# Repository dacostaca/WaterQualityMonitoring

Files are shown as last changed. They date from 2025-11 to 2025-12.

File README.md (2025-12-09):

# Water Quality Monitoring System 🌊





Un sistema autónomo de monitoreo de calidad del agua basado en ESP32 con cuatro sensores: pH, temperatura, TDS y turbidez. Incluye implementación de Deep Sleep y Watchdog Timer para operación autónoma y monitoreo de errores.

---

## 📋 Tabla de Contenidos

- [Descripción General](#-descripción-general)
- [Estado del Proyecto](#-estado-del-proyecto)
- [Estructura del Repositorio](#-estructura-del-repositorio)
  - [Etapa I - Trabajo Previo](#etapa-i---trabajo-previo)
  - [Etapa II - Desarrollo Actual](#etapa-ii---desarrollo-actual)
  - [Código del Firmware (MonitorAgua_ESP32)](#código-del-firmware-monitoragua_esp32)
  - [Código del Servidor (monitor_agua_pagina)](#código-del-servidor-monitor_agua_pagina)
- [Documentación del Código](#-documentación-del-código)
- [Inicio Rápido](#-inicio-rápido)
- [Requisitos](#-requisitos)
- [Colaboradores](#-colaboradores)
- [Licencia](#-licencia)

---

## 🌟 Descripción General

Este proyecto implementa un sistema de monitoreo de calidad del agua diseñado para operar de forma autónoma. El sistema mide cuatro parámetros críticos del agua (pH, temperatura, TDS y turbidez) y transmite los datos a un servidor web para su visualización y análisis.

### ¿Qué mide el sistema?

- **pH**: Nivel de acidez/alcalinidad del agua (0-14)
- **Temperatura**: Temperatura del agua en °C usando sensor DS18B20
- **TDS (Total Dissolved Solids)**: Concentración de sólidos disueltos en ppm
- **Turbidez**: Claridad del agua en NTU

### Aplicaciones

- Monitoreo ambiental de cuerpos de agua naturales
- Control de calidad en plantas de tratamiento
- Investigación científica y educativa
- Acuicultura y piscicultura
- Sistemas de agua potable

---

## 📌 Estado del Proyecto

**Estado actual**: El desarrollo del proyecto ha sido completado en su Etapa II. El sistema se encuentra funcional y documentado, listo para su uso o para ser retomado por futuros desarrolladores que deseen realizar mejoras o extensiones.

**Última actualización**: 09 de diciembre de 2025 (Etapa II)

---

## 📁 Estructura del Repositorio

```
WaterQualityMonitoring/
│
├── Etapa I/                        # Trabajo previo del proyecto (01-08-2025)
│   ├── diseños_pcb/               # Diseños de PCB originales
│   └── documentacion.pdf          # Documentación de la etapa inicial
│
├── Etapa II/                       # Desarrollo actual (09-12-2025)
│   ├── Manual de Usuario.md       # Guía completa para el usuario
│   ├── Pruebas y Validación.pdf   # Documento de pruebas realizadas
│   └── registro sistema de monitoreo.rar  # Fotos y fuente LaTeX
│
├── MonitorAgua_ESP32/             # Código del firmware (ESP32)
│   ├── .vscode/                   # Configuración de Visual Studio Code
│   ├── include/                   # Archivos de cabecera (placeholder)
│   ├── lib/                       # Librerías del proyecto
│   ├── src/                       # Código fuente principal
│   ├── test/                      # Directorio de tests (placeholder)
│   ├── .gitignore                # Archivos ignorados por Git
│   ├── Doxyfile                  # Configuración para Doxygen
│   └── platformio.ini            # Configuración de PlatformIO
│
├── monitor_agua_pagina/           # Código del servidor web
│   ├── web_interface/            # Interfaz web del sistema
│   └── servidor.py               # Servidor Python
│
└── README.md                     # Este archivo
```

---

## 📂 Descripción de Carpetas

### Etapa I - Trabajo Previo

**Fecha de entrega**: 01 de agosto de 2025

La carpeta **`Etapa I/`** contiene el trabajo realizado por los desarrolladores iniciales del proyecto:

#### 📐 Diseños de PCB
- **Ubicación**: `Etapa I/diseños_pcb/`
- **Contenido**: Archivos de diseño de la placa de circuito impreso (PCB) utilizados en las versiones iniciales del proyecto
- **Propósito**: Referencia para entender el hardware original y base para mejoras futuras

#### 📄 Documentación Inicial
- **Ubicación**: `Etapa I/documentacion.pdf`
- **Contenido**: Documentación técnica del proyecto en su fase inicial
- **Incluye**: 
  - Especificaciones originales del sistema
  - Diagramas de conexión
  - Resultados de pruebas preliminares
  - Decisiones de diseño tomadas

**Colaboradores Etapa I:**
- Maria Alejandra González Duque
- Juan Carlos Delgado Figueroa

---

### Etapa II - Desarrollo Actual

**Fecha de entrega**: 09 de diciembre de 2025

La carpeta **`Etapa II/`** contiene el trabajo realizado durante el segundo semestre de 2025:

#### 📖 Manual de Usuario
- **Archivo**: `Etapa II/Manual de Usuario.md`
- **Descripción**: Guía completa y detallada para usuarios finales del sistema
- **Contenido**:
  - Instalación del entorno de desarrollo (Visual Studio Code y PlatformIO)
  - Configuración del hardware y drivers
  - Conexión física de sensores a los pines GPIO
  - Flasheo del programa a la ESP32
  - Configuración de red WiFi
  - Uso del sistema y visualización de datos
  - Solución de problemas comunes
  - Referencias y recursos adicionales
- **Audiencia**: Usuarios finales, técnicos, estudiantes

#### 🧪 Documento de Pruebas y Validación
- **Archivo**: `Etapa II/Pruebas y Validación.pdf`
- **Descripción**: Documentación de todas las pruebas realizadas al sistema
- **Contenido**:
  - Metodología de pruebas
  - Casos de prueba ejecutados
  - Resultados obtenidos
  - Análisis de desempeño del sistema
  - Validación de funcionalidades
  - Conclusiones y recomendaciones
- **Propósito**: Validar el correcto funcionamiento del sistema y documentar su rendimiento

#### 📸 Registro del Sistema (LaTeX)
- **Archivo**: `Etapa II/registro sistema de monitoreo.rar`
- **Contenido**:
  - **Fotografías**: Imágenes del sistema ensamblado, sensores conectados, pruebas en campo
  - **Fuente LaTeX**: Archivos `.tex` del documento de registro
  - **Recursos**: Figuras, tablas y archivos auxiliares para compilar el documento
- **Propósito**: Documentación visual del proyecto y fuente editable para reportes académicos
- **Uso**: Descomprimir el archivo RAR y compilar el documento LaTeX para visualizar el registro completo del sistema

**Colaboradores Etapa II:**
- Daniel Felipe Acosta Castro
- Oscar Santiago Erazo Mora

*Estudiantes de Ingeniería Electrónica, Universidad Nacional de Colombia*

---

### Código del Firmware (MonitorAgua_ESP32)

La carpeta **`MonitorAgua_ESP32/`** contiene todo el código que se ejecuta en la placa ESP32.

#### Estructura del Firmware

```
MonitorAgua_ESP32/
│
├── .vscode/                       # Configuración del entorno VSCode
│   └── [archivos de configuración]
│
├── include/                       # Directorio para archivos de cabecera
│   └── README                    # Archivo placeholder
│
├── lib/                          # Librerías personalizadas del proyecto
│   ├── CalibrationManager/      # Gestión de calibración de sensores
│   │   ├── CalibrationManager.cpp
│   │   └── CalibrationManager.h
│   │
│   ├── DeepSleep/               # Implementación de modo Deep Sleep
│   │   ├── DeepSleep.cpp
│   │   └── DeepSleep.h
│   │
│   ├── RTC/                     # Control del reloj de tiempo real (RTC)
│   │   ├── RTC.cpp
│   │   └── RTC.h
│   │
│   ├── RTCMemory/               # Gestión de memoria del RTC
│   │   ├── RTCMemory.cpp
│   │   └── RTCMemory.h
│   │
│   ├── Sensors/                 # Controladores de sensores
│   │   ├── pH.cpp              # Sensor de pH
│   │   ├── pH.h
│   │   ├── Temperature.cpp     # Sensor de temperatura DS18B20
│   │   ├── Temperature.h
│   │   ├── TDS.cpp             # Sensor TDS
│   │   ├── TDS.h
│   │   ├── Turbidity.cpp       # Sensor de turbidez
│   │   └── Turbidity.h
│   │
│   ├── WatchDog/                # Implementación del Watchdog Timer
│   │   ├── WatchDog.cpp
│   │   └── WatchDog.h
│   │
│   └── WifiManager/             # Gestión de conectividad WiFi
│       ├── WifiManager.cpp
│       └── WifiManager.h
│
├── src/                          # Código fuente principal
│   └── main.cpp                 # Punto de entrada del programa
│
├── test/                         # Directorio para tests unitarios
│   └── README                   # Archivo placeholder
│
├── .gitignore                    # Archivos ignorados por Git
├── Doxyfile                      # Configuración de Doxygen
└── platformio.ini                # Configuración de PlatformIO
```

#### Descripción de Componentes del Firmware

##### Librerías Principales

- **CalibrationManager**: Gestiona los valores de calibración de los sensores, permitiendo ajustar las lecturas para mayor precisión
- **DeepSleep**: Implementa el modo de bajo consumo de energía, haciendo que la ESP32 entre en Deep Sleep entre mediciones para optimizar el uso de batería
- **RTC**: Maneja la comunicación con el módulo de reloj de tiempo real (RTC DS3231) para mantener estampas de tiempo precisas
- **RTCMemory**: Gestiona el almacenamiento de datos en la memoria del RTC que persiste durante los ciclos de Deep Sleep
- **Sensors**: Contiene los controladores para cada uno de los cuatro sensores:
  - **pH**: Sensor analógico de pH que mide acidez/alcalinidad del agua
  - **Temperature**: Sensor digital DS18B20 que usa protocolo OneWire
  - **TDS**: Sensor analógico de sólidos totales disueltos
  - **Turbidity**: Sensor analógico de turbidez que mide claridad del agua
- **WatchDog**: Implementa el temporizador Watchdog para reiniciar automáticamente el sistema en caso de fallos o bloqueos
- **WifiManager**: Gestiona la conexión WiFi, reconexión automática y comunicación con el servidor

##### Código Principal

- **main.cpp**: Programa principal que orquesta todas las funcionalidades:
  - Inicialización de sensores y periféricos
  - Bucle principal de medición
  - Almacenamiento local de datos
  - Gestión de ciclos de Deep Sleep
  - Conexión periódica a WiFi para transmisión de datos

#### Archivos de Configuración

- **platformio.ini**: Define la configuración del proyecto para PlatformIO, incluyendo:
  - Placa objetivo (ESP32)
  - Framework (Arduino)
  - Librerías externas requeridas
  - Velocidad de baudios para comunicación serial
  - Flags de compilación

- **Doxyfile**: Configuración para generar documentación automática del código usando Doxygen

#### Funcionalidades Principales del Firmware

- ⚡ **Adquisición de datos**: Lee valores de los cuatro sensores de forma periódica
- 💾 **Almacenamiento local**: Guarda mediciones en memoria del RTC cuando no hay conectividad
- 🌐 **Conectividad WiFi**: Se conecta a red configurada para transmisión de datos al servidor
- ⏰ **RTC externo**: Mantiene estampas de tiempo precisas con batería de respaldo
- 🔋 **Deep Sleep**: Reduce consumo de energía entrando en modo de bajo consumo entre mediciones
- 🛡️ **Watchdog Timer**: Reinicia automáticamente el sistema ante fallos o bloqueos
- 📊 **Calibración**: Sistema de calibración para ajustar lecturas de sensores
- 📡 **Protocolo OneWire**: Comunicación con sensor de temperatura DS18B20

---

### Código del Servidor (monitor_agua_pagina)

La carpeta **`monitor_agua_pagina/`** contiene el servidor web que recibe y visualiza los datos del sistema.

#### Estructura del Servidor

```
monitor_agua_pagina/
│
├── web_interface/                # Interfaz web del sistema
│   ├── css/                     # Hojas de estilo
│   │   └── styles.css          # Estilos de la interfaz
│   │
│   ├── js/                      # JavaScript del cliente
│   │   └── script.js           # Lógica de la interfaz web
│   │
│   └── index.html               # Página principal
│
└── servidor.py                   # Servidor Python
```

#### Descripción de Componentes del Servidor

##### Servidor Backend

- **servidor.py**: Servidor web implementado en Python que maneja:
  - Recepción de datos enviados por la ESP32
  - Procesamiento y validación de mediciones
  - Almacenamiento temporal de datos
  - Servicio de la interfaz web
  - API para consulta de datos históricos

##### Interfaz Web (web_interface/)

- **index.html**: Página principal de la aplicación web que proporciona:
  - Visualización de datos en tiempo real
  - Gráficos de tendencias de mediciones
  - Tabla con historial de datos (últimas 120 mediciones por defecto)
  - Botón para solicitar datos almacenados en la ESP32
  - Indicadores de estado de conexión

- **styles.css**: Hoja de estilos que define:
  - Diseño y apariencia de la interfaz
  - Estilos para gráficos y tablas
  - Diseño responsivo
  - Indicadores visuales de estado

- **script.js**: JavaScript del lado del cliente que maneja:
  - Solicitudes AJAX al servidor
  - Actualización dinámica de la interfaz
  - Generación de gráficos interactivos
  - Procesamiento y visualización de datos recibidos
  - Gestión de eventos de usuario (botones, filtros, etc.)

#### Funcionalidades del Servidor

- 🌐 **API REST**: Endpoints para recibir datos de la ESP32 vía HTTP
- 📊 **Visualización**: Interfaz web para mostrar datos en tiempo real y tendencias
- 💾 **Almacenamiento temporal**: Mantiene datos recientes en memoria para consulta
- 🔄 **Actualización dinámica**: Refresca automáticamente la interfaz con nuevos datos
- 📈 **Gráficos**: Generación de gráficos de series de tiempo para cada sensor
- 🎨 **Interfaz responsiva**: Diseño adaptable a diferentes tamaños de pantalla

#### Tecnologías Utilizadas

- **Backend**: Python (servidor web)
- **Frontend**: HTML5, CSS3, JavaScript
- **Comunicación**: HTTP/REST API
- **Visualización**: JavaScript (librerías de gráficos integradas en script.js)

---

## 📖 Documentación del Código

### Documentación Doxygen del Firmware

El código del firmware en la carpeta **`MonitorAgua_ESP32/`** está completamente documentado utilizando el estándar **Doxygen**. Esto permite generar documentación HTML profesional de forma automática a partir de los comentarios en el código.

#### ¿Qué es Doxygen?

Doxygen es una herramienta que extrae comentarios especialmente formateados del código fuente y genera documentación en varios formatos (HTML, PDF, LaTeX). Es ampliamente utilizado en proyectos de software para mantener la documentación sincronizada con el código.

#### 📚 Generación de la Documentación

##### Prerrequisitos

Antes de generar la documentación, asegúrese de tener Doxygen instalado:

**Windows:**
1. Descargue el instalador desde: https://www.doxygen.nl/download.html
2. Ejecute el instalador y siga las instrucciones

##### Pasos para Generar la Documentación

1. **Abrir una terminal** (Command Prompt o PowerShell) en la carpeta raíz del firmware:
   ```
   cd MonitorAgua_ESP32
   ```

2. **Ejecutar el comando de Doxygen**:
   ```
   doxygen Doxyfile
   ```

3. **Esperar** a que el proceso termine. Verá mensajes en la terminal indicando el progreso de la generación.

4. **Acceder a la documentación generada**:
   - Una vez completado el proceso, se creará una carpeta llamada **`html/`** dentro del proyecto `MonitorAgua_ESP32/`
   - Navegue a la carpeta: `MonitorAgua_ESP32/html/`
   - Abra el archivo **`index.html`** en su navegador web preferido (doble clic sobre el archivo)

##### Contenido de la Documentación

La documentación generada incluye:

- **Índice de archivos**: Listado de todos los archivos del proyecto con su descripción
- **Índice de clases**: Todas las clases definidas con sus métodos y atributos
- **Índice de funciones**: Listado alfabético de todas las funciones del proyecto
- **Diagramas de clases**: Visualización de relaciones entre clases (requiere Graphviz)
- **Diagramas de dependencias**: Muestra qué archivos dependen de otros
- **Gráficos de llamadas**: Ilustra qué funciones llaman a otras funciones
- **Documentación detallada**: Descripción completa de cada función con:
  - Propósito y funcionalidad
  - Parámetros de entrada
  - Valores de retorno
  - Notas y advertencias
  - Ejemplos de uso (cuando aplica)

##### Navegación de la Documentación

Una vez abierto `index.html`:

1. Use el menú superior para navegar entre secciones:
   - **Files**: Ver todos los archivos del proyecto
   - **Classes**: Ver las clases definidas
   - **Functions**: Buscar funciones específicas

2. Use la barra de búsqueda en la esquina superior derecha para encontrar elementos específicos

3. Haga clic en cualquier elemento para ver su documentación detallada

---

## 🚀 Inicio Rápido

### 1. Clonar el Repositorio

```bash
git clone https://github.com/dacostaca/WaterQualityMonitoring.git
cd WaterQualityMonitoring
```

### 2. Configurar el Firmware (ESP32)

1. Abra Visual Studio Code
2. Instale la extensión PlatformIO IDE
3. Abra la carpeta `MonitorAgua_ESP32` con PlatformIO
4. Conecte la ESP32 al computador mediante USB
5. Compile y flashee el programa usando el botón "Upload" (→) en la barra inferior de PlatformIO

**Nota importante**: El puerto USB Tipo C de la ESP32 solo funciona en **una orientación**. Si el computador no detecta la placa, desconecte el cable USB, voltéelo e intente conectar nuevamente.

### 3. Configurar el Servidor

1. Navegue a la carpeta del servidor:
   ```bash
   cd monitor_agua_pagina
   ```

2. Asegúrese de tener Python instalado en su sistema

3. Ejecute el servidor:
   ```bash
   python servidor.py
   ```

### 4. Acceder a la Interfaz Web

1. Abra su navegador web
2. Vaya a la dirección proporcionada por el servidor (típicamente `http://localhost:5000` o similar)
3. Espere a que la ESP32 se conecte a la red WiFi configurada
4. Use el botón "Solicitar Datos" para descargar las mediciones almacenadas en la ESP32

### 5. Configurar Red WiFi

El sistema está configurado por defecto para conectarse a:
- **SSID**: `RED_MONITOREO`
- **Contraseña**: `Holamundo6`

Para cambiar estas credenciales, edite el archivo de configuración en el firmware y vuelva a flashear el programa.

---

## 🔧 Requisitos

### Hardware

- **Placa**: ESP32 S2 o compatible
- **Sensores DFRobot**:
  - Sensor de pH (analógico)
  - Sensor de temperatura DS18B20 (digital, protocolo OneWire)
  - Sensor TDS (analógico)
  - Sensor de turbidez (analógico)
- **Módulo RTC**: DS3231 con batería CR2032 de 3.3V
- **Cable**: USB Tipo C
- **Alimentación**: 5V (USB o fuente externa)
- **Computador**: Windows 10/11 con puerto USB disponible

### Software

- **[Visual Studio Code](https://code.visualstudio.com/)** - Editor de código
- **[PlatformIO IDE](https://platformio.org/)** - Extensión para VSCode
- **[Python](https://www.python.org/downloads/)** - Para ejecutar el servidor (versión 3.7 o superior)
- **[CP210x USB to UART Bridge Drivers](https://www.silabs.com/developers/usb-to-uart-bridge-vcp-drivers)** - Drivers para comunicación con ESP32
- **[Doxygen](https://www.doxygen.nl/download.html)** - (Opcional) Para generar documentación del código
- **[Graphviz](https://graphviz.org/download/)** - (Opcional) Para diagramas en Doxygen

### Conocimientos Recomendados

- Manejo básico de Visual Studio Code
- Conceptos básicos de electrónica (voltaje, corriente, conexión de sensores)
- Navegación en interfaces web
- Conocimientos básicos de línea de comandos (para ejecutar el servidor)

---

## 📄 Documentación Adicional

Para información detallada sobre el uso del sistema, consulte:

- **[Manual de Usuario](Etapa%20II/Manual%20de%20Usuario.md)**: Guía completa de instalación, configuración y uso
- **[Pruebas y Validación](Etapa%20II/Pruebas%20y%20Validación.pdf)**: Resultados de las pruebas realizadas al sistema
- **[Registro LaTeX](Etapa%20II/registro%20sistema%20de%20monitoreo.rar)**: Documentación visual y fuente LaTeX (descomprimir para acceder)
- **[Documentación Etapa I](Etapa%20I/documentacion.pdf)**: Trabajo previo del proyecto
- **Documentación del código**: Generar con Doxygen siguiendo las instrucciones de la sección anterior

---

## 👥 Colaboradores

### Etapa I (01 de agosto de 2025)
- **Maria Alejandra González Duque**
- **Juan Carlos Delgado Figueroa**

*Responsables del diseño inicial de hardware y primera implementación del sistema*

### Etapa II (09 de diciembre de 2025)
- **Daniel Felipe Acosta Castro** - [GitHub](https://github.com/dacostaca)
- **Oscar Santiago Erazo Mora**

*Estudiantes de Ingeniería Electrónica*  
*Universidad Nacional de Colombia*  
*Segundo semestre de 2025*

---

## 🙏 Agradecimientos

- DFRobot por la documentación de los sensores utilizados
- Comunidad de PlatformIO por las herramientas de desarrollo
- Espressif por el soporte de ESP32
- Universidad Nacional de Colombia por el apoyo académico

---

**⭐ Si este proyecto te fue útil, considera darle una estrella en GitHub ⭐**

---

*Proyecto desarrollado como parte del programa de Ingeniería Electrónica*  
*Universidad Nacional de Colombia - 2025*

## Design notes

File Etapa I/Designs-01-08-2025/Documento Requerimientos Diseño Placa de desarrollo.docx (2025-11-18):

Documento de Requerimientos para Diseño de Circuitos Electrónicos

# Especificaciones Técnicas y Selección de Componentes en diseño de PCB

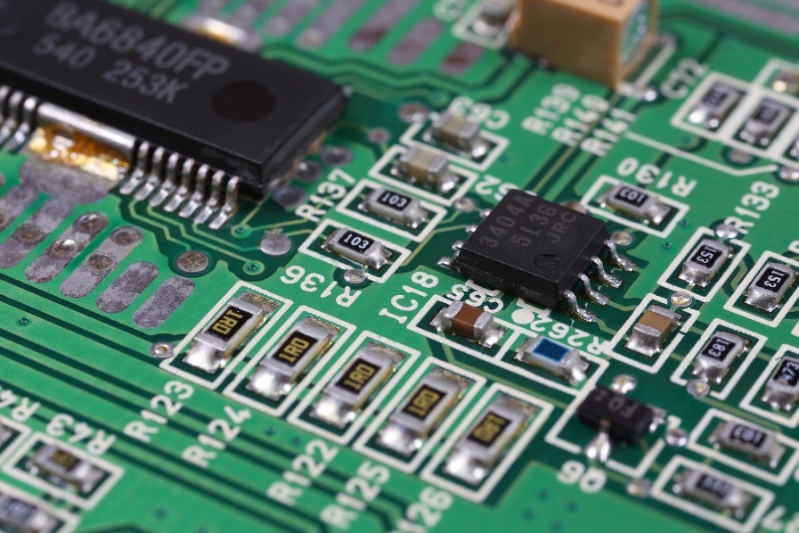
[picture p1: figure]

Tabla de Contenido

1. Introducción y Objetivos 1.1 Propósito del Documento 1.2 Alcance 1.3 Objetivos de Aprendizaje
2. Metodología de Análisis de Requerimientos 2.1 Proceso de Definición de Requerimientos 2.1.1 Identificación de Stakeholders 2.1.2 Jerarquía de Requerimientos 2.2 Análisis de Criticidad
3. Especificaciones Técnicas del Proyecto 3.1 Definición de Requerimientos Funcionales 3.1.1 RF-001 – Acceso físico a Pines GPIO 3.1.2 RF-002 – Interfaz de alimentación y comunicación USB 3.1.3 RF-003 – Indicadores y puntos de prueba 3.2 Requerimientos No Funcionales 3.2.1 RNF-001 – Consumo de Energía 3.2.2 RNF-002 – Estabilidad en entorno de desarrollo 3.2.3 RNF-003 – Manufacturabilidad 3.2.4 RNF-004 – Optimización de costo 3.3 Requerimientos Derivados 3.3.1 RD-001 – Selección de componentes 3.3.2 RD-002 – Tolerancias técnicas 3.3.3 RD-003 – Métodos de prueba y validación 3.4 Análisis de Carga y Distribución de Energía 3.4.1 Presupuesto de Energía
4. Criterios de Selección de Componentes 4.1 Metodología de Selección 4.1.1 Etapas del proceso de Evaluación 4.2 Criterios Específicos por Categoría 4.2.1 Microcontroladores 4.2.2 Componentes Pasivos 4.2.3 Conectores 4.3 Herramientas de Selección 4.3.1 Bases de Datos Recomendadas 4.3.2 Herramientas de Análisis 4.4 Selección de BOM para placa de desarrollo ESP32 4.4.1 Microcontrolador (ESP32-S2-SOLO) 4.4.2 Regulador de Voltaje (AMS1117CD-3.3) 4.4.3 Conector USB-C y ESD (TPD4S009DBVR) 4.4.4 Conversor USB-Serial (CP2102N) 4.4.5 Indicadores LED 4.4.6 Protección de Alimentación 4.4.7 Pasivos funcionales (resistencias, capacitores, inductores) 4.4.8 Automatización de Programación (BOOT & EN) 4.5 Análisis de Riesgo
5. Consideraciones de Normas y Estándares 5.1 Normas Internacionales 5.2 Reglas de Diseño Prácticas para Fabricación Recomendadas 5.3 Consideraciones de Costos
6. Validación y Pruebas 6.1 Estrategia de Validación 6.1.1 Niveles de Validación 6.1.2 Métodos de Validación 6.2 Protocolo de Pruebas 6.2.1 Pruebas Eléctricas Básicas 6.2.2 Pruebas Funcionales 6.3 Criterios de Aceptación
7. Documentación 7.1 Documentos Generados 7.2 Documentación de Diseño
8. Referencias Bibliográficas 8.1 Normas y Estándares 8.2 Literatura Técnica 8.3 Recursos Online
9. Conclusiones

1. Introducción y Objetivos

1.1 Propósito del Documento

Este documento técnico establece los requerimientos y lineamientos para el diseño y de un conjunto de placas electrónicas, compuesto por:

- Una placa de desarrollo general basada en el microcontrolador ESP32-S2-SOLO, orientada a prototipado y pruebas de comunicación.
- Una auxiliar, alimentada mediante dos baterías recargables de 3.7V, cuya carga y regulación está gestionada por el controlador MP2639, además de estar gestionada por un RTC externo.

1.2 Alcance

Este documento aplica a proyectos de diseño de circuitos electrónicos impresos (PCBs), incluyendo especificaciones funcionales y no funcionales, criterios de validación, selección de componentes clave y consideraciones de diseño electrónico y PCB que garanticen manufacturabilidad, seguridad y fiabilidad operativa. Está orientado a respaldar las decisiones técnicas de diseño.

1.3 Objetivos de Aprendizaje

Al aplicar esta metodología, el diseñador será capaz de:

- Convertir requerimientos funcionales en especificaciones técnicas claras
- Evaluar y seleccionar componentes usando criterios técnicos objetivos
- Identificar restricciones de diseño y riesgos técnicos en etapas tempranas del proyecto
- Documentar requerimientos técnicos de forma estructurada y trazable
- Aplicar buenas prácticas en el diseño esquemático y el ruteo de PCB
- Integrar consideraciones de alimentación, protección, comunicación y sensores en el diseño electrónico
- Establecer criterios de validación y pruebas acordes a los requerimientos definidos
- Generar documentación técnica útil para validación, rediseño y manufactura

2. Metodología de Análisis de Requerimientos

2.1 Proceso de Definición de Requerimientos

2.1.1 Identificación de Stakeholders

En esta etapa inicial es fundamental identificar a las partes interesadas del proyecto, ya que cada una de ellas impone requisitos específicos que deben ser considerados durante el diseño del circuito electrónico:

Stakeholders | Necesidad | Impacto en el diseño | Requerimientos derivados
Usuario Final | Facilidad de uso, funcionalidad clara, confiabilidad | Interfaz intuitiva, respuesta adecuada, diseño robusto | Dimensiones compactas, distribución funcional, protecciones básicas
Fabricación | Bajo costo, ensamblaje sencillo, procesos repetibles | Elección de componentes comunes, diseño sin pasos complejos | PCB de una o dos capas, encapsulados SMD comunes
Regulatorio | Cumplimiento de normativas básicas (CE, FCC, RoHS, etc.) | Aislamiento eléctrico, compatibilidad electromagnética (EMC) | Filtros EMI, separación de pistas, protección ESD
Mantenimiento y validación | Diagnóstico sencillo, acceso a señales, facilidad de reemplazo de componentes | Componentes accesibles con documentación clara, inclusión de puntos de prueba | Pads de prueba, conectores de depuración, etiquetas serigráficas, guía de soporte técnico.

2.1.2 Jerarquía de Requerimientos

Los requerimientos del sistema se organizan en tres categorías, cada una con un propósito específico dentro del diseño y validación de la placa de desarrollo.

A. Requerimientos Funcionales (RF)

Funciones que la placa debe realizar para cumplir su propósito como herramienta de prototipado.

- RF.1 Funciones Principales
- Exposición de señales digitales y analógicas mediante pines GPIO, respetando límites eléctricos.
- Interacción con sensores y/o módulos externos a través de buses de comunicación (UART, I²C, SPI).
- Alimentación regulada y protección básica para pruebas de conectividad.
- RF.2 Funciones secundarias
- Indicadores LED para estado de alimentación y comunicación.
- Zonas de test (test points) para caracterización eléctrica en placa.
- Pulsadores de reinicio y arranque para programación.
- RF.3 Interfaces externas
- Conectores físicos disponibles, incluyendo USB para alimentación y programación, y headers para expansión de periféricos.
- Acceso físico a buses de comunicación estándar (UART, I²C, SPI), a través de pines documentados en el datasheet del microcontrolador y habilitados en el diseño.
- Capacidad de comunicación inalámbrica programable por firmware.
B. Requerimientos No Funcionales (RNF)

Condiciones de calidad y operación bajo las cuales la placa de desarrollo debe funcionar en un entorno de pruebas o prototipado.

- RNF.1 Consumo de Energía
- El sistema debe operar con un consumo típico bajo, adecuado para aplicaciones de desarrollo embebidos.
- El sistema debe tolerar picos de corriente derivados de la activación simultánea de periféricos digitales, transmisores inalámbricos o funciones internas del microcontrolador.
- El diseño de la etapa de alimentación debe incorporar márgenes de seguridad que garanticen arranque estable y operación confiable durante actividades como la programación o la transmisión de datos.
- Se recomienda dimensionar la capacidad de corriente disponible en al menos un 30% por encima del consumo promedio estimado para evitar inestabilidad o caídas de voltaje.
- RNF.2 Confiabilidad en Entorno de Desarrollo
- Operación estable en sesiones prolongadas, sin reinicios ni fallos funcionales.
- Tolerancia a ciclos frecuentes de reinicio, programación y conexión/desconexión de periféricos sin pérdida de integridad.
- RNF.3 Manufacturabilidad
- Uso de componentes estándar (SMD, THT) con disponibilidad comercial.
- Diseño de PCB compatible con procesos básicos de ensamblaje manual o semiautomático.
- Trazabilidad y facilidad de reemplazo de componentes críticos durante pruebas.
- RNF.4 Costo
- Límite de costo estimado por unidad definido según el presupuesto del proyecto.
- Lista de materiales (BOM) optimizada con enfoque en disponibilidad y precio sin comprometer funcionalidad.
C. Requerimientos Derivados (RD)

Condiciones técnicas necesarias para implementar los requerimientos funcionales y no funcionales.

- RD.1 Selección de componentes específicos
- Elección de microcontrolador compatible con los requerimientos funcionales del proyecto.
- Reguladores de voltaje adecuados para manejo de corriente de carga.
- Componentes pasivos y sensores con tolerancias acordes a los márgenes operativos definidos.
- Preferencia por encapsulados compatibles con soldadura manual durante el prototipado.
- RD.2 Tolerancias técnicas
- Tolerancia de voltaje de entrada: ±5% respecto al valor nominal definido en el diseño.
- Compatibilidad con niveles lógicos de 3.3 V o 5 V, según la arquitectura seleccionada.
- Resistencia a ruido eléctrico y desacoples adecuados para operación confiable.
- RD.3 Métodos de prueba y validación
- Verificación de montaje.
- Medición de tensiones y corrientes en puntos clave del sistema (alimentación, referencia, señales de I/O).
- Verificación de arranque del microcontrolador mediante monitoreo serial.
- Carga de firmware de prueba y ejecución de funciones básicas (parpadeo de LED, comunicación UART o inalámbrica).

2.2 Análisis de Criticidad

La criticidad se determina para identificar qué requerimientos impactan directamente en la funcionalidad y validación del sistema. Esta clasificación permite priorizar el cumplimiento de aquellos aspectos que comprometerían el uso correcto del prototipo en caso de fallar.

ID | Tipo | Fuente | Verificación | Prioridad
RF-001 | Funcional | Usuario | Inspección visual y prueba de funcionalidad GPIO. | Alta
RF-002 | Funcional | Usuario | Verificación de funcionamiento de LEDs y test points. | Media
RF-003 | Funcional | Usuario | Prueba de conectividad física y funcionamiento de buses. | Alta
RNF-001 | No funcional | Diseñador | Medición de consumo y verificación de arranque | Alta
RNF-002 | No funcional | Usuario | Pruebas de uso prolongado en entorno de desarrollo. | Media
RNF-003 | No funcional | Diseñador | Revisión de componentes, layout y disponibilidad. | Alta
RNF-004 | No funcional | Proyecto | Comparación con presupuesto y análisis del BOM. | Media
RD-001 | Derivado | Diseñador | Revisión de hojas de datos y compatibilidad funcional. | Alta
RD-002 | Derivado | Diseñador | Cálculo de márgenes eléctricos y tolerancias. | Media
RD-003 | Derivado | Diseñador | Validación funcional mediante firmware de prueba. | Alta

3. Especificaciones Técnicas del Proyecto

3.1 Definición de Requerimientos Funcionales

3.1.1 RF-001 – Acceso físico a Pines GPIO

Descripción:

La placa de desarrollo debe proporcionar acceso físico a los pines GPIO del ESP32-S2-SOLO mediante conectores estándar (headers), respetando las especificaciones eléctricas del microcontrolador.

- Entradas: Señales digitales o analógicas desde sensores o periféricos externos.
- Salidas: Señales digitales, PWM, protocolos de comunicación (UART, I²C, SPI), según configuración del firmware.
- Criterios de Aceptación:
  - Todos los pines habilitados deben estar disponibles en conectores identificados mediante serigrafía legible en la PCB.
  - La disposición física debe permitir conexión directa a cables o módulos comunes de desarrollo.
  - El diseño debe mantener la capacidad nominal del ESP32-S2, incluyendo corriente máxima por pin (hasta 40 mA) bajo las condiciones indicadas en su hoja de datos.
- Prioridad: Alta

Nota técnica:
El valor de corriente máxima por pin (hasta 40 mA) corresponde a una especificación propia del microcontrolador ESP32-S2-SOLO bajo ciertas condiciones eléctricas. Esta placa de desarrollo no amplifica ni modifica dichas salidas, sino que simplemente las expone al usuario final mediante conectores adecuados, permitiendo el uso completo de las capacidades nativas del chip.

    3.1.2 RF-002 – Interfaz de alimentación y comunicación USB

Descripción:

La placa debe incorporar un conector USB-C para permitir tanto la alimentación como la programación del microcontrolador mediante una interfaz USB-UART integrada.

- Parámetros eléctricos:
  - Entrada: 5 V DC (desde puerto USB estándar).
  - Corriente mínima: 500 mA (USB 2.0), recomendada: 900 mA o más.
  - Salida regulada: 3.3 V DC, hasta 800 mA disponibles para el sistema.
- Criterios de Aceptación:
  - Presencia de conector USB-C funcional.
  - Regulación estable de 3.3 V bajo carga media.
  - Reconocimiento del dispositivo como puente USB-UART en el computador.
- Prioridad: Alta
    3.1.3 RF-003 – Indicadores y puntos de prueba

Descripción:

La placa debe incluir al menos dos LEDs de diagnóstico (alimentación y actividad GPIO), y puntos de prueba accesibles (test points) para monitorear señales clave.

- Criterios de Aceptación:
  - LED de encendido activo al recibir alimentación.
  - LED de usuario controlable desde GPIO del ESP32.
  - Al menos dos test points etiquetados (por ejemplo: 3.3 V, GND, UART TX o RX).
- Prioridad: Media

3.2 Requerimientos No Funcionales

    3.2.1 RNF-001 – Consumo de Energía

Especificación:

La placa debe tener un consumo típico máximo de 180 mA durante operación normal, con capacidad de tolerar picos de hasta 320 mA (modo transmisión WiFi), y hasta 500 mA en escenarios extremos.

- Condiciones de referencia:
  - Firmware con WiFi y UART activos.
  - GPIOs y periféricos en uso (SPI, I²C, ADC, etc.).
  - CPU a máxima frecuencia (240 MHz).
  - Posible carga externa moderada en salidas.
- Criterios de aceptación:
  - Consumo en reposo < 100 mA.
  - Soporte de picos sin inestabilidad o reinicios.
  - Regulador de 3.3 V funcionando dentro de rango térmico seguro.
- Prioridad: Alta
    3.2.2 RNF – 002: Estabilidad en entorno de desarrollo

Especificación:

La placa debe operar de manera estable en sesiones continuas (> 2 horas), soportando múltiples ciclos de programación, reinicio y conexión sin errores funcionales.

- Criterios de aceptación :
  - Sin reinicios inesperados.
  - LED y UART activos tras múltiples pruebas.
  - Capacidad de carga de firmware repetida sin fallos.
- Prioridad: Media
    3.2.3 RNF-003 – Manufacturabilidad

Especificación:

El diseño debe contemplar el uso de componentes estándar y encapsulados compatibles con procesos de ensamblaje manual o semiautomático, con especial atención a la accesibilidad para re-trabajo y sustitución durante pruebas.

- Criterios de aceptación:
  - Uso de componentes SMD comunes.
  - Layout compatible con servicios de manufactura comunes (JLCPCB, PCBWay u otros equivalentes).
  - Componentes críticos con distribución física que permita su sustitución sin riesgo de dañar pistas o pads cercanos.
- Prioridad: Alta
    3.2.4 RNF-004 – Optimización de costo

Especificación:

El diseño debe priorizar el uso de componentes con buena relación costo-beneficio, manteniendo la disponibilidad comercial y sin comprometer la funcionalidad mínima esperada del sistema.

- Criterios de aceptación:
  - Componentes clave disponibles en múltiples distribuidores confiables (LCSC, Digi-Key, Mouser).
  - Selección de componentes con equivalentes funcionales y encapsulados alternativos disponibles.
  - Estimación de costo unitario alineada con el presupuesto del proyecto, ajustable según volumen y proveedor.
- Prioridad: Media
  3.2 Requerimientos Derivados
    3.2.1 RD-001 – Selección de componentes

Especificación:

La placa debe garantizar componentes con compatibilidad eléctrica y funcional con los requerimientos definidos, priorizando disponibilidad comercial y facilidad de integración.

- Criterios de aceptación:
  - Microcontrolador con conectividad inalámbrica y buses periféricos integrados (ESP32-S2-SOLO).
  - Regulador con capacidad mínima de 800 mA y salida de 3.3 V.
  - Pasivos con tolerancia adecuada (resistencias ±5%, capacitores X7R o mejores).
- Prioridad: Alta
    3.2.2 RD-002 – Tolerancias técnicas

Especificación:

La placa debe tener tolerancias de voltaje, corriente y niveles lógicos deben mantenerse dentro de márgenes seguros definidos por la hoja de datos para los componentes principales.

- Criterios de aceptación:
  - Voltaje de entrada permitido: 5 V ±5%.
  - Niveles lógicos compatibles con 3.3 V (máximo absoluto: 3.6 V).
  - Uso de desacoples y filtrado para proteger contra transitorios.
  - Aislamiento adecuado entre señales sensibles y líneas de alimentación.
- Prioridad: Media
    3.2.3 RD-003 – Métodos de prueba y validación

Especificación:

Se deben realizar pruebas funcionales básicas que permitan verificar el montaje, la alimentación, y la comunicación del microcontrolador con el entorno de desarrollo.

- Criterios de aceptación:
  - Medición de voltaje regulado (3.3 V) en punto de prueba.
  - Verificación de consumo de corriente con multímetro.
  - Prueba de encendido de LED conectado a GPIO.
  - Carga de firmware.
  - Comunicación UART funcional (reconocimiento por PC).

Nota: No se incluyen pruebas de estrés, ambientales ni de certificación industrial, por tratarse de una placa de desarrollo.

- Prioridad: Alta
  3.3 Análisis de Carga y Distribución de Energía
    3.3.1 Presupuesto de Energía

Esta sección define los márgenes de consumo eléctrico esperados para la placa, considerando distintos modos de operación y posibles picos de corriente. Su objetivo es asegurar una fuente de alimentación adecuada que garantice estabilidad y confiabilidad durante el uso del sistema.

Componente | Corriente Típica | Corriente Máxima | Notas
ESP32-S2-SOLO | 80mA | 320mA | Pico durante transmisión WiFi (802.11b)
CP2102N | 11.4mA | 20mA | Durante comunicación USB-UART
LEDs indicadores | 5-10mA | 10mA | Corriente limitada por resistencia
Periféricos GPIO | 0-50mA | 200mA | Dependiente del uso y carga conectada.
Total | 155mA | 540mA | Margen de seguridad 20%

El valor pico de 320 mA proviene de la hoja de datos del ESP32-S2, en modo de transmisión 802.11b a 20 MHz, 1 Mbps @19.5 dBm.

El valor estimado de 790 mA representa un escenario extremo, considerando el consumo simultáneo del microcontrolador, el CP2102N (~14 mA), los LEDs, periféricos GPIO activos, y posibles buffers o módulos conectados externamente.

Recomendación: El sistema de alimentación debe estar dimensionado para entregar al menos 800 mA de corriente de salida, considerando márgenes de seguridad, condiciones pico y la eficiencia del regulador.

4. Criterios de Selección de Componentes

4.1 Metodología de Selección

La selección de componentes se realiza bajo un enfoque técnico y estratégico, considerando tanto los requerimientos funcionales como las restricciones reales de manufactura manual y presupuesto. Se priorizan componentes con documentación técnica confiable, disponibilidad estable y compatibilidad adecuada para procesos de prototipado manual, reconociendo la dificultad inherente de este tipo de montaje.

4.1.1 Etapas del proceso de Evaluación

La selección técnica de componentes deberá contemplar, como mínimo, los siguientes aspectos:

1. Definición de Especificaciones Mínimas
- Identificación clara y precisa de parámetros eléctricos esenciales (voltaje, corriente máxima, tolerancia requerida, frecuencia de operación), rango de temperatura de funcionamiento según las condiciones típicas.
- Restricción del tipo de encapsulado a formatos compatibles con ensamblaje manual o semiautomático, priorizando encapsulados SMD desde tamaño 0603 en adelante, o THT cuando el componente lo requiera por disponibilidad, facilidad de montaje o reemplazo.
- Consideración de dimensiones físicas que permitan fácil acceso a pines o terminales para soldadura, medición o validación funcional durante el desarrollo.
2. Búsqueda y Filtrado
  - Consultar en bases de datos confiables de componentes electrónicos (Digi-Key, Mouser, LCSC), filtrando según las especificaciones mínimas definidas.
  - Aplicación de filtros técnicos que garanticen compatibilidad eléctrica y mecánica, con prioridad a formatos compatibles con montaje manual.
  - Verificación de disponibilidad comercial inmediata y suficiente cantidad en stock para garantizar la continuidad del prototipo o pruebas.
3. Evaluación Técnica
  - Análisis crítico de hojas de datos, asegurando que las características y parámetros técnicos sean compatibles con las condiciones reales del proyecto.
  - Comparación de alternativas viables en función de parámetros clave (rendimiento eléctrico, límites operativos, tolerancias, condiciones de montaje manual).
  - Evaluación realista de márgenes de seguridad y robustez del diseño frente a posibles variaciones en condiciones operativas.
4. Evaluación Comercial
  - Análisis de costos unitarios y posibles descuentos por volumen de compra.
  - Evaluación detallada sobre disponibilidad actual, confiabilidad del suministro y plazos de entrega.
  - Revisión cuidadosa del entorno de soporte disponible, incluyendo documentación técnica, referencias de aplicación, herramientas de software y respaldo de la comunidad).
5. Validación y Selección Final
  - Se deben realizar pruebas prácticas o prototipos preliminares para verificar el desempeño real de los componentes seleccionados, especialmente si son críticos o presentan desafíos para el montaje manual.
  - Análisis da vigencia comercial del componente, considerando su disponibilidad a largo plazo, la hoja de ruta del fabricante y su política de retiro (End of Life – EOL), minimizando riesgos de obsolescencia.
  - Decisión fundamentada en criterios técnicos y comercialmente objetivos, documentando claramente las razones que respaldan la selección realizada.

4.2 Criterios Específicos por Categoría

Los criterios de evaluación deben adaptarse al tipo de componente considerado, atendiendo a sus funciones, requerimientos de integración y criticidad en el sistema. A continuación, se describen los principales aspectos a considerar por categoría.

4.2.1 Microcontroladores

- Evaluar la capacidad de procesamiento en función de la velocidad de reloj, la cantidad de memoria RAM y flash disponibles, así como los tiempos de respuesta ante eventos.
- Asegurar la disponibilidad y diversidad de periféricos (UART, SPI, I²C, ADC, PWM, entre otros) son fundamentales para garantizar la compatibilidad con el resto del sistema.
- Analizar el consumo energético debe analizarse tanto en operación activa como en modos de bajo consumo, especialmente en aplicaciones portátiles o de energía limitada o alimentadas por batería.
- Verificar la compatibilidad con entornos de desarrollo consolidados, así como la disponibilidad de documentación técnica, soporte del fabricante y respaldo por parte de la comunidad.
- Comprobar la continuidad del producto en el tiempo, mediante la revisión de la hoja de ruta tecnológica del fabricante y su política de soporte a largo plazo.

4.2.2 Componentes Pasivos

- Evaluar la tolerancia en función del costo y la aplicación, especialmente en circuitos que requieran precisión, como divisores de tensión o filtros.
- Considerar la estabilidad frente a temperatura, envejecimiento y variaciones ambientales, en especial en capacitores e inductores.
- Seleccionar el tamaño del encapsulado considerando ensamblaje, disponibilidad y espacio en el PCB.
- Validar límites eléctricos (voltaje, corriente, disipación térmica) y establecer márgenes adecuados para confiabilidad a largo plazo.
- Incluir dispositivos de protección según criticidad del nodo: diodos Schottky, TVS, fusibles o resistencias de 0 Ω.

4.2.3 Conectores

- Analizar la durabilidad mecánica en función de los ciclos de uso, robustez y resistencia al desgaste.
- Asegurar la capacidad de conducción de corriente sin comprometer la integridad del sistema.
- Priorizar compatibilidad con cables y pines estándar, facilitando mantenimiento y evitando herramientas especiales.
- Precio del conector y del cable compatible, incluyendo accesorios o herramientas si son necesarios.

4.3 Herramientas de Selección

La selección de componentes se apoyó en plataformas confiables que permiten consultar especificaciones técnicas, verificar disponibilidad comercial y comparar alternativas de manera eficiente.

4.3.1 Bases de Datos Recomendadas

- Digi-Key y Mouser: Distribuidores con filtros técnicos detallados, documentación técnica y herramientas de selección asistida.
- LCSC: Distribuidor de bajo costo con conexión directa a JLCPCB para producción y ensamble de tarjetas electrónicas.
- Octopart: Plataforma de búsqueda con integración multi-distribuidor, útil para comparación rápida de precios y disponibilidad.
    4.3.2 Herramientas de Análisis

En aplicaciones discretas como filtros, fuentes o protecciones, se emplearon simuladores eléctricos o herramientas de análisis físico de PCB. Su aplicación en circuitos integrados complejos es limitada y se complementa con hojas de datos y notas de aplicación del fabricante.

- TINA-TI y LTSpice son simuladores SPICE adecuados para validar reguladores, etapas de filtrado o circuitos analógicos simples.
- Altium Designer y KiCad, además de ser entornos de diseño, permiten realizar análisis básicos y simulaciones preliminares de ciertos componentes antes de su integración en el diseño final.
  4.3 Selección de BOM para placa de desarrollo ESP32

La selección de componentes se realizó siguiendo los lineamientos definidos en la sección 4.1, integrando criterios técnicos, comerciales y de disponibilidad. Se tomaron en cuenta tanto los requerimientos funcionales específicos del sistema como las restricciones derivadas del diseño del circuito esquemático y la implementación física en la PCB.

La mayoría de los componentes incluidos en la lista de materiales (BOM) corresponden a dispositivos de montaje superficial (SMD), lo cual permite optimizar el uso del espacio, mejorar el comportamiento eléctrico de las señales y facilitar la producción mediante procesos automatizados de ensamblaje.

Si bien ciertos componentes podrían implementarse en versiones through-hole (THT) sin comprometer la funcionalidad, se priorizó el uso de tecnología SMD debido a sus ventajas en cuanto a densidad de integración, disponibilidad en el mercado y compatibilidad con servicios de ensamblaje industrial, como los ofrecidos por JLCPCB o similares.

4.4.1 Microcontrolador

Requerimiento funcional:

El sistema requiere un microcontrolador de arquitectura de 32 bits con conectividad WiFi-integrada, soporte para interfaces periféricas estándar (UART, SPI, I²C), y capacidad de procesamiento suficiente para manejo de sensores comunicación y funciones de control local.

Componente seleccionado: ESP32-S2-SOLO (Espressif Systems)

Justificación de Selección:

El ESP32-S2-SOLO fue utilizado por su disponibilidad previa en el laboratorio y por cumplir con los requerimientos funcionales del sistema. Aunque no se evaluaron múltiples alternativas, se validó que sus características técnicas fueran adecuadas para la aplicación. Entre sus características técnicas relevantes se incluyen:

- Núcleo Xtensa LX7 32-bit a 240 MHz,
- 320 kB de memoria SRAM interna y flash incluida.
- Conectividad WiFi 802.11 b/g/n (2.4 GHz).
- UART, SPI, I²C, ADC y hasta 43 pines GPIOs disponibles.
- Soporte para USB-OTG, permitiendo comunicación directa con PC o periféricos sin requerir un chip USB-UART adicional.
- Múltiples modos de bajo consumo disponibles.

El microcontrolador cuenta con amplio soporte de desarrollo (ESP-IDF, Arduino), documentación oficial completa y comunidad activa, lo cual facilita la implementación, depuración del firmware y mantenimiento del firmware.

Implementación en hardware:

El microcontrolador se integró siguiendo el circuito mínimo de aplicación recomendado en la Hoja de datos. Se emplearon valores de capacitores de filtrado y desacoplo según las indicaciones de Espressif para garantizar la estabilidad del sistema y la correcta operación del microcontrolador.

Cabe aclarar que no todos los elementos del circuito de aplicación típico fueron implementados; se emplearon únicamente aquellos relevantes para los requerimientos funcionales del sistema, como el botón de arranque (boot), resistencias de configuración y líneas de comunicación esenciales.

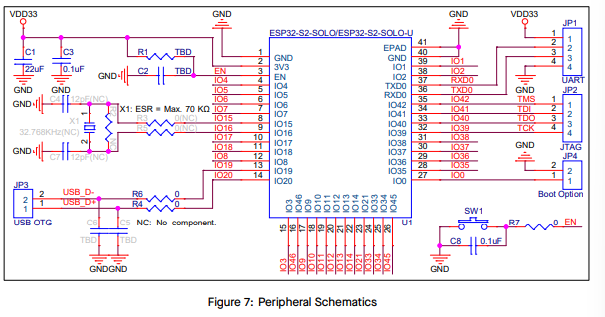
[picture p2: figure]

Figura 4.1 – Circuito de aplicación típico del ESP32-S2-SOLO
Diagrama oficial sugerido por Espressif para implementar las conexiones mínimas del microcontrolador, incluyendo alimentación, cristal externo, botón de reinicio, USB-OTG y puertos UART/JTAG.
Fuente: Espressif Systems – Hoja de datos del ESP32-S2-SOLO/SOLO-U, sección 6: Peripheral Schematics.

    4.3.2 Regulador de Voltaje

Requerimiento Funcional:

El sistema requiere un regulador de voltaje capaz de convertir una entrada de 5 V proveniente del puerto USB-C a una salida estable de 3.3 V con una capacidad mínima de corriente de 800 mA, considerando picos de consumo del microcontrolador y periféricos conectados. Además, se privilegió una solución con buena disipación térmica.

Alternativas evaluadas:

Se analizaron cinco reguladores de voltaje de salida fija a 3.3 V, ampliamente utilizados en aplicaciones de bajo voltaje. La siguiente tabla resume las principales características y criterios que influyeron en su selección o descarte:

Componente | Corriente máx. salida | Dropout @ IOUT máx | Encapsulado | Resultado
AP2112K-3.3 | 600 mA | 0.40 V | SOT-25 | Descartado por corriente limitada
RT9013-33GB | 500 mA | 0.40 V | SOT-23-5 | Descartado por corriente limitada
AMS1117-3.3 | 1 A | 1.1 V | SOT-223-3L | Aceptable, pero menos eficiente y peor disipación térmica
AMS1117CD-3.3 | 1 A | 1.1 V | TO-252-2 | Seleccionado por disipación, disponibilidad y corriente

Justificación de Selección:

El regulador AMS1117CD-3.3 fue seleccionado por ofrecer una combinación adecuada entre capacidad de corriente (hasta 1 A), robustez térmica y compatibilidad con fabricación manual, además, su disponibilidad comercial y uso extendido en diseños similares lo convierten en una solución versátil y confiable. Su encapsulado TO-252-2 proporciona una base metálica de disipación más amplia que otras versiones (como el SOT-223), facilitando el manejo de potencia sin necesidad de soluciones adicionales de refrigeración.

Implementación en hardware:

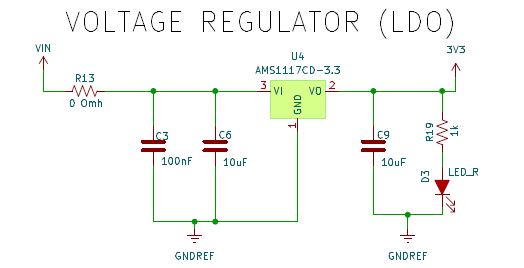
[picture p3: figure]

Figura 4.2 – Implementación del regulador AMS1117CD-3.3

El regulador AMS1117CD-3.3 fue implementado conforme a la topología mínima sugerida por el fabricante, con adaptaciones menores orientadas a facilitar el ensamblaje y el monitoreo en la placa. Se utilizaron capacitores de entrada y salida según la hoja de datos, junto con un LED indicador en la salida (con resistencia limitadora) para verificar la presencia de voltaje. También se incorporó una resistencia de 0 Ω que, además de facilitar pruebas o depuración, puede actuar como punto de seccionamiento o protección ante fallos menores.

    4.3.3 Conector USB-C y ESD

Requerimiento Funcional:

El sistema requiere un conector USB tipo C que actúe como entrada principal de alimentación (5 V) y enlace de comunicación USB 2.0. Debe ser compatible con dispositivos host estándar (computadoras, cargadores, etc.), admitir al menos 500 mA y permitir la negociación de corriente de hasta 3 A. Es indispensable que el conector soporte transferencia de datos, no limitándose únicamente a funciones de carga.

Componente Seleccionado:

- Nombre: UJ20-C-H-G-SMT-1-P16-TR
- Tipo: Receptáculo USB Tipo C, compatible con estándar USB 2.0
- Corriente nominal: Hasta 3 A
- Motivo de selección: Compatibilidad mecánica, disponibilidad y soporte completo para señales D+/D− del estándar USB 2.0.

Este conector cuenta con 16 pines, incluyendo VBUS, GND, D+, D−, y los pines CC1 y CC2, que permiten detectar la orientación del cable y negociar la corriente disponible con el host. A diferencia de conectores diseñados solo para carga, este modelo permite comunicación completa, cumpliendo con el perfil "Sink" según la especificación USB-C, lo que lo hace adecuado para aplicaciones mixtas de alimentación y transmisión de datos

Protección contra ESD:

Las líneas D+ y D− están protegidas mediante el TPD4S009DBVR, un supresor de transitorios de voltaje (TVS) diseñado para proteger hasta cuatro líneas de señal frente a descargas electrostáticas (ESD) o picos transitorios. Este dispositivo brinda protección bidireccional conforme a los requerimientos de integridad de señal USB.

Aunque en esta placa de desarrollo solo se utilizan dos líneas sensibles (D+/D−), se optó por emplear este modelo de (ESD) debido a su disponibilidad en laboratorio. Para diseños más optimizados o con restricciones de espacio y/o costo, podría considerarse el uso de un TVS de menor cantidad de canales, específicamente diseñado para proteger dos líneas USB, manteniendo la protección requerida. Por ejemplo, comparando el utilizado actualmente, con algunos comunes de 2 canales:

Componente | Canales | Tipo | Encapsulado | Comentario
TPD4S009DBVR | 4 | Bidireccional | SOT-23-6 | Utilizado; disponible en laboratorio
PESD2USB | 2 | Bidireccional | SOT-236AB | Alternativa más compacta
USBLC6-2SC6 | 2 | Bidireccional | SOT-23-6 | Baja capacitancia (~ 3.5 pF),
TPD2E007 | 2 | Bidireccional | SC-70-3 | Alta velocidad de respuesta, protección bidireccional

Implementación en hardware:

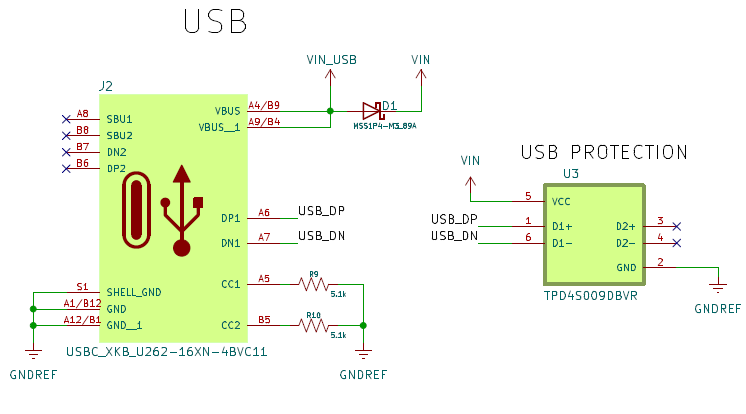
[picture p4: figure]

Figura 4.3 – Conexión e implementación del conector USB-C con protección de datos

El conector USB-C vincula las líneas VBUS y GND al sistema de alimentación. Para proteger el sistema frente a posibles inversiones de polaridad o picos de voltaje, se utilizó un diodo Schottky (D1) en la línea de entrada VIN, permitiendo conducción directa hacia la etapa de regulación de voltaje con caída mínima de tensión.

Las señales D+ y D− se enrutan como par diferencial hacia el convertidor USB–Serial CP2102N, pasando previamente por el supresor de transitorios (TVS) TPD4S009 para brindar protección frente a descargas electrostáticas (ESD) y picos de tensión.

Se implementaron resistencias de 5.1 kΩ en CC1 y CC2 para configurar el dispositivo como sink (receptor de energía) frente al host, conforme a la especificación del estándar USB-C, la cual establece que un dispositivo tipo UFP (Upstream Facing Port) debe colocar resistencias Rd a GND en dichos pines para que el DFP (Downstream Facing Port) detecte y negocie la corriente de suministro disponible (ver Figura 4.3).

Según Texas Instruments:
“USB-C can natively support either 1.5A or 3A. A DFP can advertise its current-carrying capability with a specific value pullup resistor. A UFP has a fixed-value pulldown resistor (Rd) such that when connected, it forms a voltage divider with Rp.”

— Texas Instruments, USB Type-C® Basics, SLYY228, p. 3.

    4.3.4 Conversor USB-Serial

Requerimiento Funcional:

El sistema requiere una interfaz de conversión USB–UART confiable para realizar la programación, monitoreo y comunicación del microcontrolador ESP32-S2 desde un PC. El componente debe ofrecer velocidad de transmisión adecuada (≥ 2 Mbps), disponibilidad en el mercado, soporte de drivers actualizados y un encapsulado que facilite la integración en placa.

Alternativas Evaluadas:

Se consideraron dos conversores USB–UART ampliamente utilizados en aplicaciones electrónicas. La comparación incluyó aspectos de velocidad, encapsulado, disponibilidad y confiabilidad general. La tabla resume los criterios clave para su evaluación.

Componente | Velocidad máx. UART | Tipo de comunicación Serial | Distribuidores | Precio | Encapsulado | Drivers
CH340C | 2 Mbps | Full-Dúplex | LCSC | $0.52 | SOP-16 | Nativos en Windows / Linux
CP2102N-A02-GQFN28 | 3 Mbps | Full-Dúplex | LCSC / DigiKey Mouser | $1.66 / $4.32 | QFN-28 | Soporte oficial Silicon Labs (instalación manual)

Justificación de Selección:

Aunque ambos componentes son ampliamente utilizados en proyectos de desarrollo, se optó por el CP2102N-A02-GQFN28 debido a su mayor velocidad de transmisión (3 Mbps), bajo consumo energético y un encapsulado más compacto QFN-28. Cuenta además con soporte oficial por parte de Silicon Labs y alta disponibilidad en múltiples distribuidores.

Implementación en hardware:

Figura 4.4 – Implementación del conversor USB–Serial CP2102N-A02-GQFN28.

El conversor fue implementado siguiendo las recomendaciones del fabricante para el CP2102N. En el esquemático se observa la conexión del puente USB–UART con las señales de datos (D+ y D−), que ya se encuentran protegidas mediante el circuito ESD mostrado en la sección del conector USB-C. También se incorporaron capacitores de desacoplo y conexiones adecuadas de alimentación (VREGIN, VDD, VBUS). Las líneas UART se conectan directamente al microcontrolador, asegurando compatibilidad con el estándar USB 2.0.

    4.3.5 Indicadores LED

Requerimiento funcional:

El sistema permite incorporar indicadores visuales (LEDs) para facilitar el diagnóstico del estado de alimentación y el funcionamiento básico del microcontrolador. La cantidad y ubicación de estos elementos puede adaptarse según las necesidades del usuario o del entorno de desarrollo, pero en diseños educativos o de prototipo se recomienda al menos un LED de encendido (Power) y otro conectado a una línea GPIO programable.

Criterios para selección de LEDs:

A continuación, se presentan las recomendaciones técnicas para seleccionar LEDs adecuados en un diseño electrónico básico, considerando tanto funcionalidad como disponibilidad comercial:

Parámetro | Recomendación | Justificación
Tipo de LED | SMD (Montaje Superficial) | Optimiza el espacio, facilita la automatización y reduce costos frente a LEDs THT.
Encapsulado | 0603 o 0805 | 0805: mejor disipación térmica y manejo manual; 0603: mayor densidad en diseño compacto.
Color | Rojo, Verde, Azul, Blanco, Amarillo | Códigos de color estándar facilitan diagnóstico visual e interpretación rápida.
Voltaje directo (Vf) | 1.8 - 2.2 V (Rojo / Amarillo) 2.0 – 2.4 V (Verde) 2.8 – 3.4 V (Azul) 3.0 – 3.6 V (Blanco) | Parámetro crítico para calcular correctamente la resistencia limitadora.
Corriente típica (Id) | 5 – 20 mA (típico 10 mA) | Balance entre visibilidad, consumo de energía y vida útil del LED.
Corriente máxima | 20 – 30 mA | Límite seguro de operación; superar este valor puede degradar rápidamente el LED.
Brillo (mcd) | Interior: 50 – 200 mcd Exterior: 500 - 1000 mcd | Garantiza visibilidad adecuada según el entorno.
Temperatura de operación | –40 °C a +85 °C | Rango estándar para aplicaciones industriales y ambientes exigentes.
Vida útil | >50,000 horas | Garantiza confiabilidad durante la vida del producto.
Disponibilidad comercial | Activo, con stock, no obsoleto o con alternativas recomendadas | Facilita la reposición y evita rediseños por cambios de componente.
Documentación | Hoja de datos y curva I-V disponibles | Permite validar comportamiento eléctrico y compatibilidad con el circuito.

Recomendación por color y función:

Color | Uso común sugerido
Rojo | Indicador de alimentación, error, o alarma
Verde | Estado OK, listo, encendido exitoso
Azul | Comunicación activa, modo especial, transferencia
Amarillo/Ámbar | Advertencia, transición de estado, actividad en pausa
Blanco | Iluminación general, estado neutro

Componentes seleccionados:

Se integraron dos LEDs SMD de color rojo de uso general, acompañados por resistencias limitadoras de 1 kΩ.

LED (Rojo) de encendido (Power LED):
Conectado a la salida del regulador de 3.3 V, permite verificar visualmente que la regulación de voltaje es correcta. Si no está encendido, indica un posible fallo en el sistema de alimentación.

LED (Verde) de usuario (GPIO2):
Conectado al pin GPIO2 del ESP32-S2, se utiliza como señal visual en pruebas de carga de firmware o control básico de salidas digitales. Este pin es comúnmente utilizado por Espressif en sus ejemplos y placas de referencia, por lo que su inclusión resulta útil para verificación rápida de funcionalidad.

Implementación en hardware:

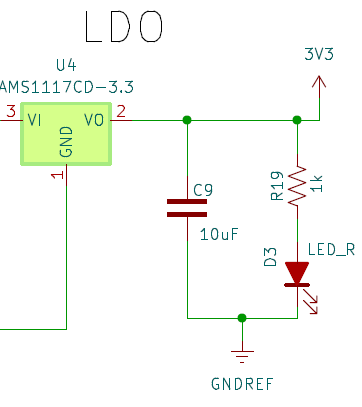
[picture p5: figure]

Figura 4.5 – 4.6 – Diodos LED de verificación (Power y Prueba)

Ambos LEDs (rojo y verde) fueron conectados en configuración estándar con resistencia limitadora en serie y referencia a GND. El LED rojo se vinculó a la salida del regulador para indicar presencia de voltaje, mientras que el LED verde se asoció al pin GPIO2 del microcontrolador, permitiendo pruebas funcionales durante el desarrollo del firmware. Las resistencias se calcularon para operar a 3.3 V, asegurando visibilidad óptima sin impactar el consumo del sistema.

    4.3.6 Protección de Alimentación

Requerimiento funcional:

El sistema debe contar con elementos que garanticen la protección de la entrada de energía (VIN), especialmente frente a eventos de conexión invertida, picos de tensión o condiciones de sobrecorriente. Estas protecciones buscan evitar daños permanentes a los reguladores, al microcontrolador o a los periféricos sensibles del sistema.

Tipos comunes de protección en la entrada de alimentación:

- Diodo Schottky: El diodo Schottky es uno de los métodos más comunes para proteger contra inversión de polaridad en la entrada de alimentación. Su estructura metal-semiconductor le otorga una respuesta ultrarrápida y una caída de voltaje directa, típicamente baja, entre 0.2 V y 0.4 V, lo que minimiza pérdidas frente a diodos de silicio tradicionales.
  - Respuesta rápida sin tiempo de recuperación inversa significativo y favorable para señales o conmutaciones rápidas.
  - Alta eficiencia en conmutación y protección inmediata.
  - En sistemas de alta corriente, puede requerir disipación térmica adecuada.

Es ideal para sistemas embebidos o alimentados por USB, donde se busca simplicidad, robustez y bajo consumo. A continuación, se presentan los criterios clave para su selección:

Criterio | Recomendación | Justificación
Corriente directa (IF) | ≥120 - 150 % de la corriente máxima esperada del sistema. | Evita operación al límite y mejora la confiabilidad térmica.
Voltaje inverso VRRM) | ≥1.5 × la tensión máxima de entrada. | Protege contra sobrevoltajes en polarización inversa.
Caída de voltaje directa (VF) | Lo más baja posible (ideal: 0.2 V–0.45 V en Schottky). | Minimiza pérdidas de energía y calentamiento.
Encapsulado | Compatible con espacio disponible y disipación (SOD-123, DO-214, SMA, etc.) | Facilita montaje, disipación térmica y automatización.
Disponibilidad | Modelos ampliamente disponibles con suficiente stock y activos. | Evita problemas de reposición o escalado del diseño.
Documentación | Datasheet completo y claro del fabricante. | Permite verificar y comparar especificaciones.

- MOSFET de Protección (P-Channel): Ofrece una solución más eficiente que el diodo Schottky para proteger la entrada de alimentación. Gracias a su baja resistencia en conducción, reduce significativamente las pérdidas de potencia, lo que lo hace ideal para sistemas de alta corriente o alimentados por batería.
  - Muy baja caída de voltaje (típicamente 10 mV–100 mV).
  - Alta eficiencia energética y menor generación de calor.
  - Bloqueo total en caso de inversión de polaridad.
  - Ideal para dispositivos portátiles, telecomunicaciones y aplicaciones de alta corriente.

Puede requerir un circuito de control adicional (auto-polarizado o con GPIO), lo que complica ligeramente el diseño en comparación con un simple diodo. Además, su capacitancia parásita puede afectar el rendimiento en aplicaciones sensibles a EMI. A continuación, se presentan los criterios clave para su selección:

Criterio | Recomendación | Justificación
Voltaje de drenador-fuente ( V_(DS) ) | ≥ 1.5 × tensión máxima del sistema. | Garantiza operación segura ante transitorios y sobrevoltajes.
Resistencia en conducción ( R_(DS) (on)) | Lo más baja posible (≤ 100 mΩ ideal). | Minimiza pérdidas térmicas y mejora eficiencia energética.
Corriente continua ( I_D )) | ≥ 150 % de la corriente máxima esperada. | Asegura margen térmico y evita saturación en condiciones exigentes.
Voltaje de compuerta ( V_(GS) (th)) | Acorde a señal de control (típico -1 V a -4 V). | Permite conmutación confiable según lógica de control utilizada.
Encapsulado | Acorde a disipación y espacio (SOT-23, DPAK, TO-220) | Facilita montaje y control térmico.
Disponibilidad | Modelos con buen stock, activos. | Facilita la reposición y evita modificaciones innecesarias en el diseño.
Documentación | Datasheet confiable | Permite verificar y comparar especificaciones.

- Diodo TVS (Transient Voltage Suppressor): Es un dispositivo diseñado para proteger entradas de alimentación y señales contra picos de voltaje, ESD y transitorios. Su respuesta es ultrarrápida (nanosegundos), conduciendo cuando se supera su voltaje de ruptura, limitando el voltaje a un nivel seguro.
  - Disponible en versiones unidireccionales (líneas DC) y bidireccionales (líneas AC o señales diferenciales).
  - Modelos de baja capacitancia ideales para proteger señales de datos (USB, HDMI, I2C, etc.) sin afectar su integridad.

La selección debe considerar voltaje de trabajo, sujeción, potencia pico y capacitancia. En señales rápidas, usar TVS < 5 pF. Se ubican cerca del conector o punto vulnerable. A continuación, se resumen los criterios clave de selección:

Criterio | Recomendación | Justificación
Voltaje de trabajo ( V_(RWM) ) | ≥ 10 % sobre el voltaje nominal del sistema. | Evita conducción en condiciones normales.
Voltaje de sujeción ( V_C ) | ≤ el voltaje máximo tolerado por el circuito. | Limita el voltaje durante el transitorio y evita daños.
Voltaje de ruptura ( V_(BR) ) | Debe estar entre V_(RWM) y V_C . | Asegura activación precisa sin falsas detecciones.
Potencia pico ( P_(PK) ) | ≥ 400 W (alimentación) o según riesgo esperado. | Define la capacidad de absorber picos sin daño.
Capacitancia ( C_j ) | < 5 pF en señales rápidas (USB, HDMI, etc.). | Evita distorsión en líneas de datos de alta velocidad.
Tipo | Unidireccional para DC, bidireccional para AC o señales diferenciales. | Asegura compatibilidad con el tipo de línea protegida.
Tiempo de respuesta | Nanosegundos. | Asegura protección efectiva ante picos rápidos como ESD.
Encapsulado | SMC, DO-214, SMB, SOT-23, etc. | Depende de potencia requerida y espacio disponible.
Disponibilidad | Modelos comunes y con buen stock | Evita problemas de reposición o rediseño.
Documentación | Datasheet confiable del fabricante | Permite comparar parámetros críticos de manera precisa.

- PTC Resettable (Polymeric Positive Temperature Coefficient Thermistor): Dispositivo de protección contra sobrecorrientes. Ofrece recuperación automática tras una falla, evitando reemplazos y permitiendo ciclos repetidos de protección. Su resistencia aumenta bruscamente con la temperatura (efecto Joule). Cuando la corriente supera el umbral, el dispositivo se calienta y su resistencia crece exponencialmente, limitando la corriente a un valor seguro.
  - Tiempo de respuesta más lento que un fusible (segundos).
  - Mayor resistencia en estado normal que un fusible (~0.1–1 Ω).
  - Dependiente de temperatura ambiente (afecta disparo)

Parámetro | Recomendación | Justificación
Corriente de mantenimiento ( I_(HOLD) ) | ≥ corriente normal del sistema. | Evita activación errónea.
Corriente de disparo ( I_(TRIP) ) | ~2 x I_(HOLD) . | Asegura activación ante sobrecorrientes.
Voltaje máximo ( V_(MAX) ) | ≥ 10 % por encima del voltaje de operación. | Evita fallos por sobretensión.
Tiempo de disparo | Segundos (varía con la corriente y temperatura). | Define velocidad de respuesta ante fallas.
Resistencia inicial ( R_(MIN) ) | ~0.1–1 Ω. | Minimiza caída de tensión en operación normal.
Temperatura de operación | –40 °C a +85 °C (típico). | Asegura funcionamiento confiable en ambientes industriales.
Encapsulado | SMD (1206, 1812) o radial (según espacio) | Facilita integración en el layout y disipación térmica
Disponibilidad | Modelos comunes y con buen stock | Evita problemas de reposición o rediseño.
Documentación | Datasheet confiable del fabricante | Permite comparar parámetros críticos de manera precisa.

Componente seleccionado:

Dado el análisis previo de los principales mecanismos de protección para la alimentación en placas de desarrollo, se optó por la implementación combinada de un diodo Schottky y un diodo TVS, seleccionados en función de sus características eléctricas adecuadas al entorno de operación de la placa.

- Nombre: MSS1P4-M3-89A

Tipo: Diodo Schottky

Corriente directa (IF): Hasta 1 A

Tensión inversa repetitiva máxima (VRRM): 40 V

Tensión Directa (VF): 0.550 V

- Nombre: TPD4S009DBVRG

Tipo: Diodo TVS

Tensión de trabajo (VRWM): 5.5 V

Tensión de sujeción (VC): 20 V (máx)

Tensión de ruptura (VBR): 9 V (min)

Potencia pico (PPK): 25W

Capacitancia (Cj): 0.8 pF

Tipo de polaridad: Unidireccional

Implementación en hardware:

Ambos dispositivos fueron montados directamente en la zona del conector USB (ver Figura 4.3), maximizando su efectividad como primera línea de defensa ante eventos eléctricos.

- El diodo Schottky fue colocado en serie sobre la línea de alimentación VIN, actuando como barrera contra polaridad inversa y caída de tensión controlada.
- El diodo TVS fue conectado entre las líneas D+ y D- y tierra, brindando protección efectiva contra descargas electrostáticas (ESD) y transitorios rápidos sobre las líneas de datos del USB.

Esta implementación proporciona una primera línea de defensa tanto para la alimentación como para la integridad de la interfaz de datos USB, sin comprometer el funcionamiento normal del sistema ni generar interferencias relevantes en señales de alta velocidad.

4.4.7 Pasivos funcionales

Requerimiento Funcional:

El diseño requiere el uso de elementos pasivos para funciones esenciales de acondicionamiento, filtrado, desacoplo, polarización y configuración de líneas de señal. Estos elementos garantizan estabilidad eléctrica, protección contra ruido y correcto funcionamiento del sistema en diferentes condiciones de operación.

Tipos comunes de componentes Pasivos Funcionales:

- Resistencias: Las resistencias son componentes fundamentales en el diseño de PCBs. Se utilizan para limitar corriente, dividir voltajes, fijar niveles lógicos, polarizar transistores, proteger entradas, sensar corriente, entre muchas otras funciones. Su correcta selección afecta directamente la precisión, seguridad, consumo y estabilidad del circuito.

Existen varios tipos según su construcción, cada uno con propiedades específicas:

- Película delgada: Fabricadas con una capa fina de material resistivo, ofrecen alta precisión, baja tolerancia (±0.1–1%) y bajo coeficiente térmico. Son ideales para circuitos analógicos, sensores, ADCs/DACs y divisores de tensión donde la estabilidad y exactitud son críticas.
- Película gruesa: Son las más comunes en electrónica general. Tienen tolerancias más amplias (±5%), suficiente para aplicaciones digitales, pull-ups, LEDs, y uso general. Son económicas y de amplia disponibilidad.
- Bobinadas (Wirewound): Construidas con un alambre resistivo enrollado. Soportan altas corrientes y disipación de potencia (hasta decenas de vatios). Se usan en etapas de potencia, pruebas de carga, frenado dinámico o fuentes conmutadas. No son recomendadas para frecuencias altas, ya que pueden presentar inductancia parasitaria.

Clasificación funcional:

Grupo | Uso | Aplicación principal
Configuración y control lógico | Pull-up / Pull-down, puente/jumper. | Fijan niveles lógicos estables en entradas digitales flotantes. Se usan también como rutas de configuración, selección de modos (boot, periferias) o para verificación durante pruebas. - Pull-up/down: típicas 5.1 k – 10 kΩ - Puente: 0 Ω
Protección y limitación | Limitadoras de corriente, termistores (PTC/NTC), resistencias en serie | Protegen componentes como LEDs (limitación de corriente), entradas digitales (protección básica frente a ruido o sobrecorriente) o controlan el encendido suave (termistores). - LEDs: R= (V_(fuente) -V_(LED))/(I_(LED)) , 220–470 Ω (típica), hasta 1kΩ o más para menor consumo e intensidad. - GPIO/señales: 100–100k Ω
Medición y referencia | Resistencias de sensado, divisores de tensión normalmente película delgada. | Permiten medición precisa de corriente / voltaje y establecen referencias precisas. - Sensado: típicas 0.01 – 1 Ω
Potencia y disipación | Resistencias bobinadas de película gruesa o cerámicas de alta potencia | Empleadas en sistemas que requieren disipación significativa o absorción de energía en frenado, precarga o pruebas de carga. • Valores: 1 Ω – 1 kΩ o más • Potencias: desde 1 W hasta 20 W (según necesidad)

Criterios para selección de resistencias:

Criterio | Recomendación | Justificación
Tolerancia | ±1% para señales críticas (ADCs o) o mediciones. ±5% para usos generales. | Mejora precisión donde se requiere estabilidad (referencias, sensores); tolerancia mayor donde no afecta.
Potencia nominal (W) | Mínimo 1/4 W para lógica. ≥1/2 W en LED, elementos de disipación. | Evita sobrecalentamiento, garantiza margen seguro ante variaciones de voltaje o carga.
Coeficiente térmico (ppm/°C) | ≤100 ppm/°C para resistencias de precisión. No crítico en pull-up/down, LEDs o señales no sensibles | Mantiene estabilidad de valores resistivos ante variaciones térmicas ambientales.
Encapsulado | SMD: 0201, 0402, 0603, 0805 para tamaño compacto. 1206+ para mayor potencia. | Optimiza espacio en PCB y facilita el montaje según la potencia requerida.
Tipo de película | Película delgada. Película gruesa. Resistencia bobinada. | Adecúa la tecnología al nivel de precisión o disipación necesaria.
Disponibilidad | Serie E24 para aplicaciones generales, E96 en diseño de precisión. Buscar fabricantes con amplio stock | Garantiza continuidad de producción y reduce riesgos de rediseño por obsolescencia.
Documentación | Hoja de datos del fabricante. | Permite verificar comportamiento eléctrico bajo condiciones específicas.

- Capacitores: Los capacitores son componentes pasivos esenciales que almacenan y liberan energía eléctrica, suprimen ruidos, estabilizan tensiones y permiten el acoplamiento o desacoplo de señales. Su correcta selección impacta directamente en la estabilidad, eficiencia y comportamiento del sistema electrónico, particularmente en frecuencia, temperatura y duración operativa. Según su construcción y material dieléctrico tenemos lo siguientes:
- Cerámicos (MLCC - Multicapa) Son los más utilizados. Tienen baja ESR, buena respuesta en alta frecuencia y tamaño compacto. Se emplean en desacoplo, filtrado, bypass, osciladores y señales de alta velocidad.
    - Clase I (C0G/NP0): Muy estables, baja deriva con temperatura y voltaje. Ideales para aplicaciones críticas o RF.
    - Clase II (X7R, X5R): Mayor capacidad por volumen, pero menor estabilidad. Adecuados para desacoplo general.
    - Clase III (Y5V, Z5U): Muy alta capacidad, pero poca estabilidad. Solo para usos no críticos o baja frecuencia.
- Electrolíticos (aluminio/tántalo) Alta capacidad en volúmenes pequeños. Útiles en filtrado de energía, almacenamiento de carga y estabilización de alimentación.
- Aluminio: Mayor capacidad y económicos, pero con mayor ESR.
- Tántalo: Mejor estabilidad, menor ESR, más costosos y sensibles al sobrevoltaje.
- Poliéster / Polipropileno Alta estabilidad, baja absorción dieléctrica. Usados en circuitos de precisión, audio, temporización, y fuentes de potencia. Soportan voltajes altos.
- Electrolíticos sólidos (polímeros) Baja ESR, buena estabilidad, larga vida útil. Son ideales para fuentes de alimentación modernas (switching, CPUs , etc.).

Clasificación funcional:

Grupo | Uso / Aplicación principal
Desacoplo / bypass | Estabilización de tensión de alimentación y supresión de ruido de alta frecuencia. Se colocan cerca de CI. Típicos: 100nF (cerámico clase II) por pin, combinados con mayores (1 µF – 10 µF – 22uF).
Filtrado | Remueven componentes de alta frecuencia en fuentes o líneas de señal. Complementan inductores o protegen etapas sensibles Típicos: 1 µF – 470 µF (electrolíticos o cerámicos de gran tamaño).
Acoplamiento / bloqueo DC | Permiten el paso de señales AC entre etapas y bloquean el componente DC. Muy comunes en audio, sensores o comunicaciones. Típicos: 100nF – 10 µF (dependiendo de impedancias). (Cerámicos clase I, II o de Tántalo).
Temporización / osciladores | Determinan tiempos en circuitos RC (reset, rampas, PWM, osciladores). Típicos: 1nF – 1 µF (con resistencias). (Cerámicos de precisión o Poliéster).
Estabilización / almacenamiento | En fuentes de poder, cargadores, conversores DC-DC. Tienen alta capacidad para mantener voltaje estable ante cambios de carga. Típicos: 10 µF – 1000 µF (electrolíticos, polímeros, tántalo, cerámico X7R).

Nota: Los capacitores electrolíticos (aluminio, tántalo, polímero) son polarizados: tienen un terminal positivo (+) y uno negativo (–). En cambio, los capacitores cerámicos y de película no tienen polaridad, por lo que pueden instalarse en cualquier sentido.

Criterios para selección de capacitores:

Criterio | Recomendación | Justificación
Tolerancia | ±5% o mejor en temporización / precisión. +-10% - ±20% para desacoplo general. | La precisión de capacitancia influye en frecuencias, tiempos y estabilidad del circuito
Voltaje nominal | ≥ 2× el voltaje real de operación. | Margen de seguridad ante sobrevoltajes; compensación por derivas en cerámicos
Coeficiente de temperatura (TCC) | C0G/NP0 para precisión. X7R/X5R en desacoplo. Evitar Y5V/Z5U en funciones críticas. | Mantiene comportamiento estable en ambientes con variaciones térmicas.
Constante de tiempo (τ = RC) | Evaluar en temporizadores, filtros, control de carga. | Determina respuesta transitoria, duración de señales y tiempo de retardo
Encapsulado | SMD: 0201, 0402, 0603, 0805 para tamaño compacto 1206+ en mayores capacidades Radiales/SMD en electrolíticos | Relación tamaño vs montaje y disipación
ESR / ESL | Baja ESR en fuentes conmutadas, alta frecuencia. No crítico en bypass simple. | Afecta directamente el comportamiento en régimen transitorio.
Vida útil | Consultar hoja de datos (mil horas a 85° o 105°C). Polímeros y cerámicos tienden a durar más. | Importante en fuentes de alimentación y equipos de larga duración.
Documentación | Verificar hoja de datos, curva de capacitancia vs voltaje, ESR, tolerancia real. | Validación técnica para comportamiento en condiciones reales.

- Inductores: Son componentes pasivos que almacenan energía en forma de campo magnético cuando circula corriente a través de ellos. Se oponen a los cambios bruscos de corriente y resultan fundamentales en aplicaciones de filtrado, conversión de energía, almacenamiento y oscilación. Su correcta elección impacta directamente en la eficiencia, estabilidad, ruido, respuesta dinámica y compatibilidad electromagnética (EMI) del circuito.

Según su construcción y material de núcleo, podemos clasificarlos en:

- Núcleo de aire: No poseen material magnético, lo que les otorga gran estabilidad y linealidad, aunque con baja inductancia y eficiencia. Se utilizan principalmente en osciladores de radiofrecuencia (RF) y filtros para señales de alta frecuencia.
- Núcleo de ferrita: Poseen alta permeabilidad magnética, ofreciendo buena eficiencia en rangos de frecuencia baja y media. Son ideales para filtrado de EMI, almacenamiento de energía y se utilizan comúnmente en fuentes conmutadas, filtros EMI y convertidores DC-DC
- Núcleo de polvo de hierro: Se caracterizan por una saturación más gradual y menor permeabilidad que los de ferrita, pero con excelente estabilidad térmica. Son adecuados para convertidores tipo Buck/Boost, filtros de audio y corrección de factor de potencia (PFC).
- Toroidal: Toroidales: Estos inductores están bobinados en forma de toroide (donut). Esta geometría minimiza las fugas de campo magnético y el acoplamiento con otros componentes, lo que permite una alta eficiencia y bajo ruido EMI. Se aplican en filtros de línea, inductores de potencia y circuitos de audio. Generalmente, usan núcleos de ferrita o polvo de hierro y son más comunes en montaje THT aunque existen algunas versiones SMD para aplicaciones específicas.

Clasificación funcional:

Grupo | Uso / Aplicación principal
Filtrado EMI / RFI | Atenúan interferencias de alta frecuencia en líneas de alimentación o señal. Típicos: 1 uH – 1 mH (ferrita, SMD, toroidal).
Convertidores DC-DC | Almacenan energía durante la conmutación para regular el voltaje. Típico: 1 µH – 1000 µH (núcleo de ferrita o polvo de hierro).
Filtros LC / Integradores | Forman filtros pasivos paso bajo, paso alto o integradores analógicos. Típico: 10 µH – 1 mH (depende de frecuencia y carga).
Desmagnetización / flyback | En fuentes aisladas, almacenan y liberan energía al secundario. Típicos: 10 µH – 1 mH (ferrita, toroides).
Osciladores LC / RF | Definen frecuencia de resonancia junto con capacitores. Típico: 10 nH – 10 µH (núcleo aire o cerámico SMD)

Nota: Los inductores generan campos magnéticos que pueden acoplarse con otras pistas o componentes sensibles (como señales analógicas). Es recomendable alejarlos o usar modelos blindados.

Tabla para criterios de selección:

Criterio | Recomendación | Justificación
Tolerancia | Usualmente ±10 % o ±20 %. Para filtros de precisión, elegir inductores de ±5 % o mejor. | En aplicaciones como osciladores o filtros sintonizados, la tolerancia afecta directamente la frecuencia de corte o resonancia.
Corriente nominal (IRMS, ISAT) | IRMS ≥ corriente promedio del circuito. ISAT ≥ pico esperado sin saturar el núcleo. | Protege el componente y evita saturación que reduce su efectividad.
Resistencia serie (DCR) | Baja DCR para minimizar pérdidas mínimo en el orden de los mΩ (especialmente en convertidores). | Afecta la eficiencia y disipación térmica.
Frecuencia de trabajo | Seleccionar inductores optimizados para la frecuencia (100 kHz – MHz). | Los núcleos y pérdidas varían según frecuencia.
Tamaño / Encapsulado | SMD: 0603 – 1210 para electrónica compacta. Axiales / Toroidales en fuentes grandes. | Relación tamaño, disipación y corriente.
Tipo de núcleo | Ferrita: eficiencia alta, saturación brusca. Hierro en polvo: buena tolerancia, saturación gradual. | Afecta respuesta dinámica, estabilidad térmica y EMI.
Factor Q | Alto Q en filtros resonantes. (Q = reactancia / resistencia). | Mejora selectividad y eficiencia en filtros.
Blindaje | Usar blindados en diseño denso o sensible a EMI. | Reduce emisión de interferencias y ruido acoplado.
Documentación | Verificar curvas de inductancia vs frecuencia, DCR, ISAT y comportamiento térmico en la hoja de datos. Asegura un diseño fiable bajo condiciones reales de operación. | Asegura que el comportamiento real coincide con el esperado en condiciones operativas.

Componentes seleccionados en diseño:

A. Resistencias:
  - Pull-up / Pull-down: Estabilizan niveles lógicos en entradas digitales del ESP32 (IO0, EN) y del CP2102N (~RST, ~SUSPEND).
  - Resistencias limitadoras: Aplicadas en LEDs para verificación de presencia de tensión (post-regulación) y programación vía GPIO2. También son comunes en líneas de comunicación (TX, RX), aunque en este diseño no fueron colocadas.
  - Puentes de 0 Ω: Empleadas como puentes de configuración y prueba, permiten reconfiguración del circuito o aislamiento durante el desarrollo y validación.
  - Divisores de tensión: Usados en la línea VBUS del CP2102N para su activación correcta, asegurando niveles lógicos seguros.
B. Capacitores:
- Desacoplo / Bypass : Capacitores cerámicos de 100 nF, 0.1 µF, 10 µF y 22 µF fueron distribuidos estratégicamente en pines de alimentación del ESP32 y CP2102N, así como en la entrada y salida del regulador AMS1117CD-3.3, con el fin de suprimir ruido y estabilizar el voltaje.
- Filtrado y estabilización: Particularmente en la etapa de regulación y entradas sensibles, mejorando la respuesta transitoria ante cambios de carga.
- Temporización / reinicio: Asociados a las líneas BOOT y EN del ESP32 para generar retardo de arranque y permitir la correcta secuencia de programación automática.
C. Inductores: No se emplearon inductores en esta versión del diseño. Sin embargo, pueden integrarse fácilmente para filtrado EMI o mejoras de eficiencia.

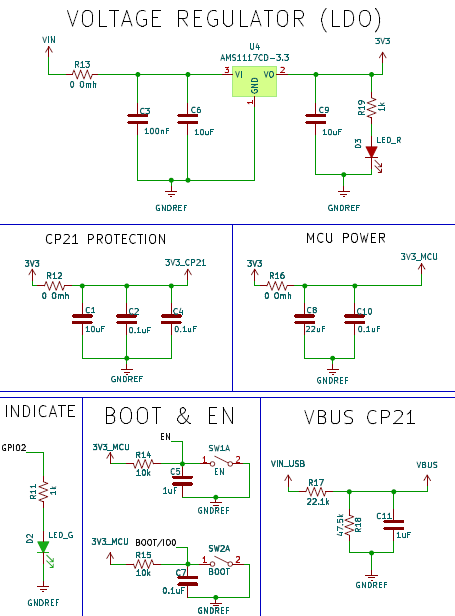
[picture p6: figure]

Figura 4.7 Implementación de componentes pasivos en el diseño.

    4.4.8 Automatización de Programación (BOOT & EN)

Requerimiento funcional:

El sistema debe permitir la programación del microcontrolador ESP32-S2 sin necesidad de presionar botones físicos, utilizando una lógica que controle automáticamente las señales EN (reset) e IO0 (modo boot). Esta lógica será controlada por el convertidor USB-UART (CP2102N) durante la carga del firmware, mediante las señales RTS y DTR.

Adicionalmente, el sistema debe incluir botones físicos para EN y IO0, que permitan realizar reinicios o entradas manuales al modo de programación en caso de necesidad (por ejemplo, en pruebas sin PC o por fallas en la lógica automática). Esto garantiza redundancia funcional y mejora la usabilidad durante el desarrollo.

Criterios de Selección – Transistores NPN para señales EN y BOOT

Criterio | Recomendación | Justificación
Encapsulado | SMD: SOT-23 para un NPN SOT363, SC88, SC70, SOT-563 para pares NPN | Compacto y compatible con montaje superficial en PCBs modernas.
Corriente de colector (IC) | ≥ 100 mA | Las señales de control consumen pocos mA, pero un margen amplio mejora fiabilidad.
Tensión colector-emisor (VCEO) | ≥ 30 V | Muy superior a los 3.3 V de operación lógica. Protege contra picos de voltaje.
Tensión colector-emisor (VEBO) | ≥ 5 V | Evita ruptura por exceso de polarización inversa en la unión base-emisor.
Disipación de potencia | ≥ 250 mW | Asegura estabilidad térmica ante corrientes moderadas sin necesidad de disipador externo.
Ganancia (hFE) | 50 – 800 (típico a baja corriente) | Facilita saturación con corrientes de base muy pequeñas, ideales para activación directa desde UART.
Tensión de saturación (VCE(sat)) | ≤ 0.3 V a 5–10 mA de IC | Asegura que EN e IO0 bajen a nivel lógico 0 confiable cuando están activados.
Frecuencia de transición (fT) | ≥ 100 MHz | Proporciona conmutación rápida en señales digitales. Aunque no es crítico, mejora margen de diseño.
Documentación | Verificar curvas: hFE vs IC, VCE(sat) vs IC, Pd, límites absolutos | Asegura que el comportamiento real coincide con los requerimientos de la aplicación.

Switches físicos – EN y BOOT

Aunque la programación automática se logra con transistores y control UART, se incluyen pulsadores físicos conectados a los pines EN e IO0, como respaldo manual.

- Encapsulado SMD tipo tact-switch (2 o 4 pines) o THT estándar (miniatura de 6x6 mm)
- Sus requisitos eléctricos mínimos, soporte al menos 5V y 10 mA. Requieren resistencias pull-up externas o internas si no están ya en la placa.

Estos botones son necesarios para forzar manualmente el modo de programación o reiniciar el sistema, útil en pruebas sin computadora o ante errores del circuito automático.

Componentes seleccionados:

- Nombre: BC848

Tipo: Transistor NPN (x2)

Corriente colector (IC): 100 mA

Tensión colector-emisor (VCEO): 30 V

Tensión colector-emisor (VEBO): 5 V

Tensión de saturación (VCE(sat)): 600 mV (Aunque es algo superior al valor recomendado, en la práctica suele ser menor bajo baja corriente. Se ha validado su correcto funcionamiento en placas ESP32-S2 comerciales.

Disipación de potencia: 250 mW

Ganancia (hFE): 450

Frecuencia de transición (fT): 100 MHz

Observación final: Aunque el BC848 ha demostrado un desempeño aceptable en la aplicación propuesta, se recomienda considerar su reemplazo en futuras versiones del diseño, ya que este componente se encuentra actualmente descontinuado. Además, existen alternativas con características eléctricas mejoradas (menor VCE(sat), mayor hFE) que podrían optimizar el comportamiento del sistema y mejorar la disponibilidad a largo plazo.

- Nombre: PTS810SJG250SMTR LFS

Tipo: Switch táctil (x2)

Numero contactos: 4

Justificación de selección:

Los transistores BC848 fueron seleccionados por su disponibilidad en laboratorio, dimensiones compactas (SOT-23), capacidad de corriente adecuada para control de señales lógicas y ganancia suficiente para operar con las líneas UART del CP2102N sin requerir amplificación adicional. A pesar de tener una VCE(sat) algo mayor a la ideal, su comportamiento práctico ha demostrado ser funcional para la activación confiable de los pines EN y IO0 del ESP32-S2 en múltiples placas comerciales.

Implementación en hardware:

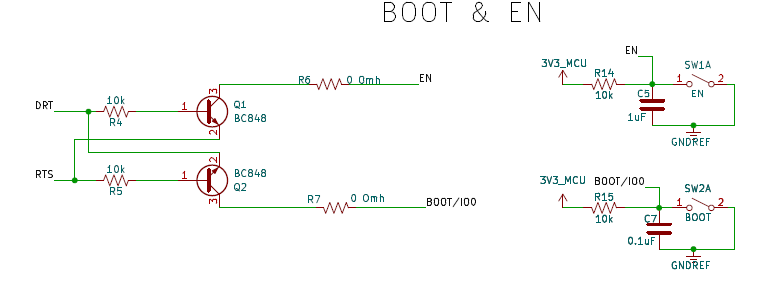
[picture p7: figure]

Figura 4.8 Circuito de programación automática del ESP32-S2

La lógica automática basada en transistores NPN permite activar los pines EN e IO0 desde el CP2102N usando señales RTS y DTR, replicando la secuencia de programación sin intervención del usuario. Los pulsadores físicos se conectan en paralelo para permitir activación manual cuando sea necesario

  4.4 Análisis de Riesgo

Durante el proceso de selección de componentes, se evaluaron los principales riesgos asociados a disponibilidad, soporte técnico y posibles afectaciones a largo plazo. A continuación, se presentan los aspectos considerados:

- Riesgo de Obsolescencia: Se priorizó el uso de componentes activos con producción vigente, documentación técnica actualizada y respaldo oficial del fabricante .Se evitaron referencias en estado EOL (End of Life). En casos puntuales, se utilizaron componentes disponibles en laboratorio que actualmente se encuentran descontinuados o fuera del mercado comercial; esta condición fue debidamente documentada y se recomienda su reemplazo en versiones futuras del diseño.
- Riesgo de Suministro: Para componentes críticos se verificó la disponibilidad en múltiples distribuidores internacionales (Digi-Key, Mouser, LCSC), seleccionando referencias ampliamente utilizadas en la industria y con múltiples equivalentes funcionales (por ejemplo, AMS1117, TPD4S009, UJ20-C-H), con el fin de garantizar continuidad de abastecimiento.
- Riesgo Técnico: Los componentes con impacto directo en la funcionalidad del sistema —como el regulador de voltaje, el microcontrolador y el convertidor USB-UART— fueron validados mediante el análisis de sus hojas de datos y los circuitos de aplicación recomendados por el fabricante. Se procuró una adaptación mínima al diseño original para reducir errores de implementación y asegurar un funcionamiento confiable.
- Riesgo de Costo: Se descartaron componentes con precios unitarios excesivos o alta volatilidad en el mercado. Se priorizaron soluciones estables en costo, adecuadas tanto para prototipos como para escalabilidad en lotes pequeños, sin comprometer la funcionalidad ni la robustez del sistema. Esto contribuye a mantener un balance entre rendimiento técnico y viabilidad económica.

5. Consideraciones de Normas y Estándares de diseño

5.1 Normas Internacionales

Durante el desarrollo del circuito impreso, se consideraron las siguientes normas técnicas de referencia:

Norma | Aplicable | Fase de Aplicación | Criticidad | Observación
IPC-2221A | Sí | Diseño PCB | Alta | Norma fundamental para el diseño de circuitos impresos. Establece directrices sobre espaciado, ancho de pistas, aislamiento eléctrico y requisitos de seguridad.
IPC-A-610 | Sí | Manufactura | Alta | Estándar clave para evaluar la calidad del ensamblado, incluyendo soldadura, limpieza, alineación de componentes y criterios de inspección visual.
IEEE 802.11 | Sí | Diseño RF | Media | Aplica indirectamente debido a la integración de Wi-Fi en el ESP32-S2. Es relevante en el diseño de antenas impresas (PCB) o trazados de alta frecuencia..
FCC Part 15 | Opcional | Certificación | Nula | No aplicable a prototipos personales sin intención de comercialización. Será relevante si el proyecto evoluciona hacia una versión certificada.

5.2.1 Reglas de Diseño Prácticas para Fabricación Recomendadas

Se siguieron criterios compatibles con los servicios de fabricación económica de placas como JLCPCB, lo cual permite asegurar manufacturabilidad con bajo costo y altos estándares de calidad. Aunque existen múltiples proveedores, los valores aquí presentados se alinean con las capacidades comunes para PCBs de FR4 a 2 capas.

Parámetro | Valor mínimo | Valor recomendado | Comentario
Clearance | 0.127 mm | ≥ 0.20 mm | Espaciado entre pistas y pads. Mayor aislamiento, reduce riesgo de cortocircuitos.
Track width | 0.127 mm | ≥ 0.20 mm | Ancho de pista. Mejora la resistencia térmica y facilita la inspección visual.
Vía diameter (externo) | 0.25 mm | ≥ 0.6 mm | Mejora la resistencia mecánica y facilita soldadura manual.
Vía hole size (interno) | 0.15 mm | ≥ 0.3 mm | Mejora robustez y facilidad de manufactura.
Anular ring | 0.2 mm | ≥0.25 mm | Área de cobre alrededor de la vía. Disminuye riesgo de desprendimiento del cobre.
Hole-to-hole spacing | 0.127 mm | ≥ 0.2 mm | Evita debilidad mecánica entre taladros.
Pad-to-track clearance | 0.1 mm | ≥ 0.25 mm | Reduce riesgo de puentes de soldadura.
Silkscreen line width | 0.15 mm | ≥ 0.2 mm | Mejora legibilidad y durabilidad del texto.
Silkscreen to pad clearance | 0.15 mm | ≥ 0.2 mm | Evita la superposición con pads, mejorando la legibilidad y reduciendo defectos de soldadura.
Soldermask bridge mínimo | 0.2 mm | ≥ 0.25 mm | Reduce posibilidad de cortocircuitos por soldadura.
Soldermask expansion | 0.05 mm | 0.05 – 0.12 mm | Mejora tolerancia de alineación de máscara.
Copper thickness | 35 µm (1 oz) | 35 µm (1 oz) | Estándar para corriente < 1 A.
PCB thickness estándar | 0.4–2.0 mm | 1.6 mm | Buena rigidez y compatibilidad con conectores estándar.
Surface finish | HASL / ENIG / OSP | ENIG | Mejora soldabilidad y precisión en SMD.
Pares diferenciales (USB) | ≥ 0.1 mm | 0.15–0.20 mm (espaciado) | Mantener impedancia característica cercana a 90 Ω.

Buenas prácticas:

- Rutas de potencia: usar ≥ 0.4 mm (16 mil) para pistas que conduzcan más de 500 mA.
- Antenas o pares diferenciales (USB, I²C de alta velocidad): mantener simetría, traza directa, sin cambios de capa si es posible. Evitar pistas bajo el par diferencial.
- Disipación de potencia: en lugar de pistas, usar zonas de cobre cuando se maneje corriente significativa.
- Usar teardrops: mejora la transición mecánica entre pista y pad, y refuerza conexiones.
- Habilitar thermal pads facilita la soldadura en pads conectados a planos de masa o alimentación, reduciendo la disipación térmica durante el proceso.
- Plano de tierra en ambas capas: interconectado mediante múltiples vías. Evitar dejar “islas” sin cobre o zonas sin conexión clara.
- Evitar pistas paralelas entre capas: reduce acoplamiento capacitivo y ruido inducido.
- Evitar trazas en zonas de interferencia: como cerca de inductores, osciladores o módulos RF.

5.3 Consideraciones de Costos

- Tolerancias mínimas elevan costos: Usar valores mínimos de pista, vía o spacing incrementa significativamente el costo, ya que requiere procesos de mayor precisión, control óptico estricto y pruebas adicionales.
- Diseño con reglas estándar reduce el precio: Para placas prototipo o de producción limitada, se recomienda respetar los parámetros estándar del fabricante (pistas ≥ 0.2 mm, vías ≥ 0.25 mm, clearances ≥ 0.2 mm) para garantizar compatibilidad con procesos económicos de fabricación.
- Color del soldermask: Los colores no estándar (como negro, blanco, azul o amarillo) pueden presentar mayores tolerancias dimensionales, menor definición en la serigrafía, y en algunos casos, una disipación térmica menos eficiente o una reflectancia óptica no deseada. Además, algunos fabricantes limitan la densidad de cobre en capas internas con soldermask blanco o negro, lo cual puede afectar diseños de alta corriente o RF. El color verde sigue siendo el más económico, confiable y ampliamente utilizado en la industria.
- Acabado superficial: Acabados como ENIG o OSP son más caros que HASL, pero ofrecen mejor soldabilidad, especialmente en componentes SMD. ENIG se recomienda si el presupuesto lo permite y se requiere mayor durabilidad o manejo de componentes de paso fino (fine pitch).
- Número de capas: a mayor cantidad de capas, mayor complejidad y precio. Una PCB de 2 capas es significativamente más económica que una de 4 o más, tanto en materiales como en pruebas y fabricación.
- Perforaciones y fresados especiales: el uso de ranuras, bordes curvos, V-cuts, o perforaciones no estándar (slots, castellated holes) también incrementa el costo de fabricación.

6. Validación y Pruebas

Una vez completada la fabricación del PCB y el montaje de los componentes, se inició el proceso de validación del sistema con el objetivo de verificar su funcionalidad eléctrica, mecánica y de comunicación. El enfoque se estructuró en varios niveles y utilizó métodos de prueba progresivos, adaptados al estado del prototipo.

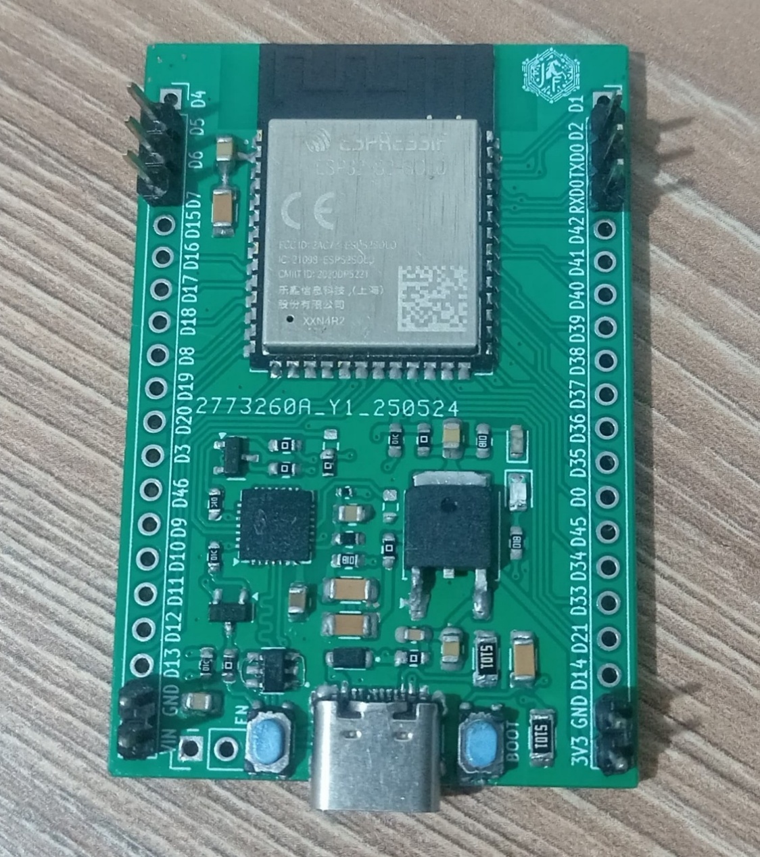
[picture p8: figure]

Figura 6.1 PCB montada

6.1 Estrategia de Validación

    6.1.1 Niveles de Validación
- Componente: Cada componente clave fue inspeccionado visualmente antes del montaje para verificar su valor, orientación y encapsulado. Se utilizaron pruebas simples de continuidad y verificación con multímetro para comprobar reguladores, conectores y diodos de protección.
- Subsistema: Se validaron bloques funcionales como el sistema de alimentación, la comunicación USB-UART, y la respuesta del microcontrolador ESP32-S2-SOLO de forma parcial, verificando arranque y respuesta básica.
- Sistema: Se comprobó la funcionalidad completa del diseño, incluyendo carga de firmware, alimentación estable, arranque, y comunicación con el entorno de desarrollo ESP-IDF.
- Integración: Se realizaron pruebas en condiciones reales de uso, validando la capacidad de programar y alimentar la tarjeta desde un computador, así como la detección del dispositivo en el sistema operativo.

6.1.2 Métodos de Validación

- Análisis: Se consultaron hojas de datos y referencias para seleccionar valores adecuados, realizando algunos cálculos manuales y otras selecciones basados en los datasheets aunque no se realizaron simulaciones debido a la complejidad del sistema embebido.
- Inspección: Se efectuó una revisión visual tras el montaje, verificando el correcto posicionamiento, soldadura y orientación de los componentes. También se midieron dimensiones básicas para asegurar compatibilidad con carcasas.
- Prueba: Se utilizaron instrumentos como multímetro para verificar continuidad, presencia de voltaje, y consumo de corriente en la fuente. Se probó la comunicación serial y programación del micro.
- Demostración: El sistema fue puesto en funcionamiento, con conexión a PC, carga de firmware vía USB, encendido de LEDs de prueba, y reconocimiento del dispositivo como puerto serial.

6.2 Protocolo de Pruebas

6.2.1 Pruebas Eléctricas Básicas

Se realizaron pruebas iniciales tras el montaje de la PCB para verificar la integridad eléctrica y funcionamiento básico del sistema.

- Continuidad de conexiones críticas: Se verificó con multímetro la continuidad entre el conector USB-C, LDO, líneas de alimentación principales, y pines del ESP32-S2-SOLO.
- Aislamiento entre redes: Se revisaron posibles cortocircuitos entre VCC y GND antes de aplicar voltaje. No se detectaron fallas críticas.

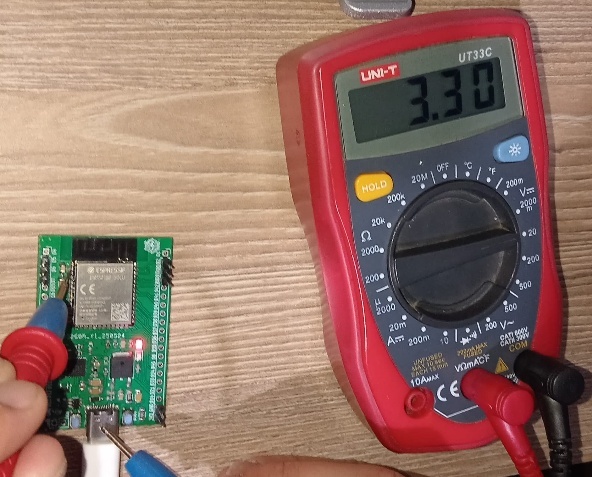
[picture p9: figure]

- Voltajes de alimentación: Entrada de 5V desde USB correctamente regulada a 3.3V por el regulador principal (Figura 6.2) y Se midieron 3.3V estables en la salida del regulador y en el pin de alimentación del ESP32 (Figura 6.3).

Figura 6.3 Medición 3.3 V en el pin de entrada del ESP32-S2

Figura 6.2 Medición 3.3 V Salida LDO

- Corrientes de consumo: Se realizaron mediciones de corriente en diferentes estados operativos del sistema para evaluar el comportamiento energético de la placa. Las pruebas se efectuaron sin carga externa conectada a los pines GPIO, por lo que los resultados reflejan únicamente el consumo intrínseco del microcontrolador y los circuitos asociados.

Los estados considerados fueron los siguientes:

  - Reposo: Se cargó un firmware completamente vacío, sin ninguna tarea activa ni inicialización de periféricos. En este estado, el microcontrolador permanece encendido con configuración por defecto, pero sin generar actividad en sus bloques funcionales. Esto permite estimar el consumo mínimo de la placa en condiciones de espera sin uso funcional
  - Ejecución básica: Firmware con una rutina que alterna el estado de un LED conectado a un GPIO y transmite mensajes por UART. Este escenario simula un uso básico del sistema con salida visual e interacción mínima
  - Consumo máximo simulado: Se activaron periféricos internos como ADC, UART, WiFi en modo activo y varias salidas digitales configuradas en alto. Aunque esta configuración permite estimar un consumo elevado, no representa un caso completamente real, ya que los pines no tienen cargas conectadas (sensores, actuadores u otros dispositivos), lo que limita el flujo de corriente total en comparación con una aplicación final.

Esta caracterización sirve como base para el análisis energético y puede ampliarse con pruebas en condiciones reales.

Estado | Condiciones | Consumo típico (mA)
Reposo | Firmware completamente vacío. Sin inicialización de periféricos ni tareas activas. Microcontrolador encendido sin uso funcional. | 20 mA
Ejecución básica | Firmware con parpadeo de LED en GPIO y transmisión periódica por UART. Sin cargas externas conectadas. | 20 mA
Consumo máximo simulado | Periféricos internos habilitados: ADC, UART, WiFi activo, múltiples GPIO en alto. Sin dispositivos externos conectados (carga mínima en pines). | 90 mA

Figura 6.4 Reposo Figura 6.5 Ejecución básica

Figura 6.6 Máximo consumo

- Funcionalidad básica:
  - LED de voltaje regulado activado.
  - Regulador con salida estable de 3.3V
  - El microcontrolador recibe alimentación.

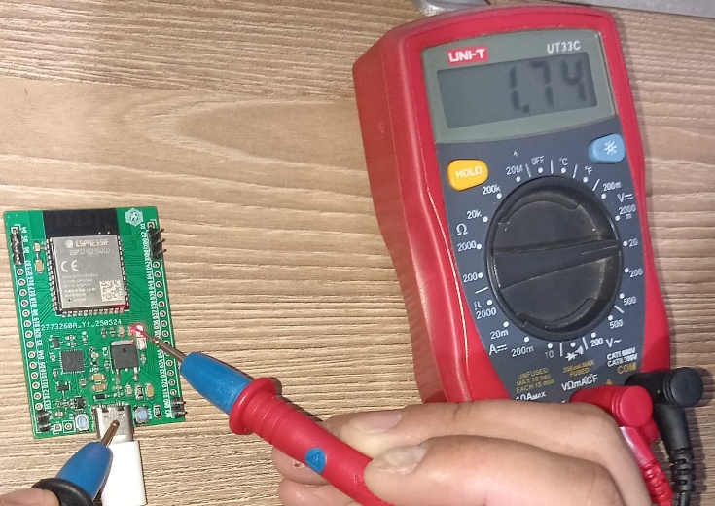
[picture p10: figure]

Figura 6.7 Tensión a través del LED de encendido desde el LDO, a través de una resistencia de 1 kΩ.

Estas pruebas básicas validaron el correcto funcionamiento inicial del sistema, sirviendo como punto de partida para pruebas funcionales más avanzadas.

6.2.2 Pruebas Funcionales

Una vez verificada la integridad eléctrica, se procedió a validar funciones específicas del sistema.

- Programación y comunicación:

Durante las pruebas iniciales, el dispositivo no era detectado como puerto serial en el computador. Al revisar el diseño, se identificó un error de conexión en el supresor de transitorios TPD4S009DBVR, el cual impedía que las señales de datos del USB llegaran correctamente al convertidor USB-UART CP2102N.

Causa del error:
Las líneas USB_DP y USB_DN fueron conectadas al par de pines D1+ y D1− del supresor ESD, pero luego se intentó continuar la señal hacia el CP2102N desde los pines D2+ y D2−, asumiendo erróneamente que estos actuaban como salidas. Esta interpretación incorrecta se debió a una lectura superficial de la hoja de datos del componente.

No obstante, el TPD4S009DBVR está diseñado para proteger hasta dos pares de señales independientes, y no actúa como un bloque de entrada-salida. Por tanto, las señales deben conectarse únicamente al par D1+ / D1−, y desde esos mismos nodos derivarse hacia el CP2102N. Los pines D2+ / D2− deben dejarse sin conexión si no se utilizan (ver Figura 6.5).

Solución implementada:
Dado que el dispositivo está compuesto por diodos TVS en paralelo con la señal, se optó por realizar un puente directo entre los nodos D1 y D2 correspondientes, de modo que se restableciera la continuidad de la línea de datos hacia el CP2102N. Esta solución fue válida sin comprometer la integridad de la señal USB, ya que los TVS actúan únicamente cuando se supera el umbral de tensión y poseen una capacitancia parásita muy baja, adecuada para señales de alta velocidad.

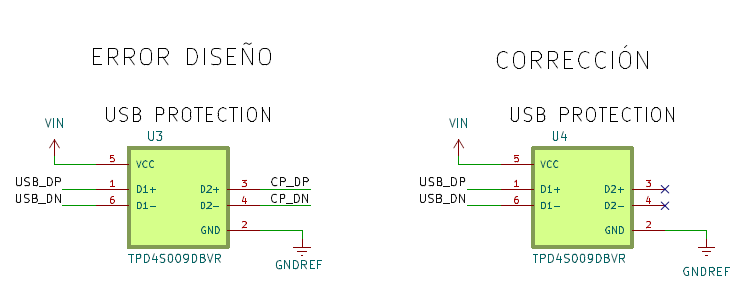
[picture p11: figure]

Figura 6.8 Comparación esquemático entre el diseño incorrecto (izquierda) y la corrección implementada (derecha) en la protección ESD para las líneas de datos USB.

Este error fue identificado una vez las placas ya estaban fabricadas, por lo que el inconveniente se corrigió durante el montaje. Se analizó en profundidad el datasheet del TVS y se verificó que la solución adoptada no afectaría el funcionamiento eléctrico ni la integridad de señal, permitiendo continuar con la validación sin necesidad de fabricar nuevas placas.

La siguiente imagen muestra el montaje físico de la placa con el supresor conectado, donde se aplicó una corrección para redirigir las líneas USB directamente al CP2102N, solucionando el problema de comunicación serial.

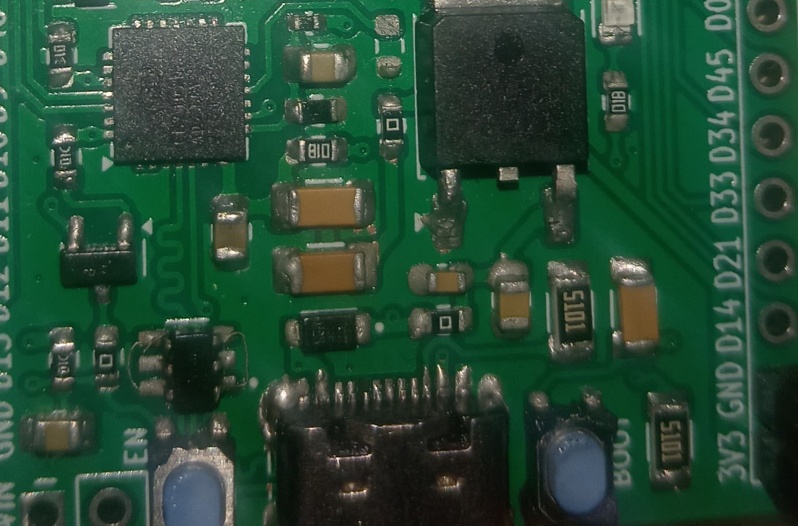
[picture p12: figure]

TPD4S009DBVR

Figura 6.9 Región de la PCB donde se encontraba el error en el conexionado del supresor ESD TPD4S009

Problema adicional durante la programación:
Después de resolver el problema de detección USB, el sistema identificó correctamente el dispositivo como "Silicon Labs CP210x USB to UART Bridge". Sin embargo, al intentar cargar el firmware desde el entorno ESP-IDF, aparecía el mensaje “El ESP32-S2 no responde”.

Al principio, se pensó que el problema podría estar en los transistores de control para los pines BOOT y EN, pero los pulsos de programación se generaban correctamente. También se revisaron las conexiones entre el CP2102N y el ESP32-S2 (TX y RX), sin encontrar errores.

Como siguiente paso, se intentó usar un conversor USB-UART externo, conectado directamente a los pines del microcontrolador (TX, RX, 3.3 V y GND), pero el problema seguía. No se recibía ninguna respuesta del ESP32-S2.

Entonces, se decidió probar algo simple: se desconectaron las resistencias de 0 Ω entre el CP2102N y el micro. Al repetir la prueba con el convertidor externo, esta vez funcionó perfectamente. Esto sugería que el problema estaba en el propio CP2102N, tal vez interfiriendo en la comunicación.

Para confirmarlo, se desmontó y volvió a montar el CP2102N con cuidado, descartando posibles cortocircuitos. Luego se hizo una prueba de loopback conectando su salida TX a su propia entrada RX desde el PC, pero no se recibió ninguna respuesta: el pin RX estaba dañado.

Finalmente, se hizo una prueba cruzada conectando otro convertidor USB-UART directamente al CP2102N, y se confirmó que sí transmitía datos (TX funcionaba), pero no recibía nada (RX seguía fallando).

Solución final:
Se reemplazó el CP2102N por un nuevo componente, tras lo cual la programación vía ESP-IDF fue exitosa. El problema se debió a una falla física en el pin RX del CP2102N original.

- Operación de GPIO

Se validó la funcionalidad de los pines GPIO programables a través de una rutina de prueba que configuraba ciertos pines como salidas digitales para encender/apagar un LED, y otros como entradas digitales con pulsadores. Se verificó que respondieran correctamente en tiempo real y sin interferencias lógicas o conflictos eléctricos. Esta prueba también confirmó la correcta configuración de resistencias pull-up/pull-down internas del microcontrolador.

Figura 6.10 Prueba de funcionalidad de GPIO

mediante encendido de LED verde.

- Estabilidad térmica

El dispositivo se mantuvo encendido durante sesiones prolongadas (>2 horas) bajo condiciones normales de operación para observar posibles incrementos de temperatura o comportamientos erráticos. Se usó una cámara térmica para confirmar que ninguna región de la PCB superara los 50 °C, incluyendo el regulador de voltaje y el microcontrolador. No se observaron apagones, reinicios espontáneos ni degradación en el rendimiento.

- Compatibilidad electromagnética

Dado que no se realizaron pruebas certificadas en cámara anecoica, se optó por una verificación preliminar. Se encendió el dispositivo cerca de una radio AM/FM y de otros dispositivos inalámbricos para detectar interferencias. Adicionalmente, se verificó que el módulo WiFi/Bluetooth operara de forma estable sin cortes ni pérdidas de conectividad al transmitir datos. No se observaron comportamientos anómalos atribuibles a EMC.

6.3 Criterios de Aceptación

Para cada bloque funcional probado se definieron criterios objetivos de éxito. A continuación, se presenta un ejemplo correspondiente a la prueba de conectividad USB-UART mediante el convertidor CP2102N:

- Condiciones de prueba:
  - Plataforma: PC con Windows 11.
  - Cable: USB tipo C.
  - Herramienta: ESP-IDF correctamente instalado y configurado.
  - Alimentación: 5 V, 1 A, estable.
- Procedimiento:
  - Conectar el dispositivo al PC mediante el puerto USB-C.
  - Verificar en el Administrador de dispositivos que sea reconocido como:

"Silicon Labs CP210x USB to UART Bridge (COM12)"

  - Abrir una terminal (PowerShell o CMD) con el entorno ESP-IDF activo (por ejemplo, ejecutando export.ps1).
  - Ejecutar comando: “idf.py -p COMX monitor”, reemplazando X por el puerto correspondiente.
  - Observar en el monitor serie la salida enviada por la ESP32-S2, incluyendo mensajes de arranque del bootloader y ejecución del firmware.

Figura 6.11 Ejecución de firmware "Blink" en terminal serial.

En este caso, se utilizó un programa de ejemplo que hace parpadear un LED conectado al GPIO2 cada 2 segundos. El resultado confirma que el firmware fue cargado correctamente, ejecutándose el código y dando veracidad que la comunicación UART funciona correctamente.

- Criterios de pase/falla:
  - El dispositivo no aparece como puerto USB.
  - No hay salida en terminal tras pulsar EN o al encender el dispositivo.
  - Aparecen símbolos extraños (problemas de velocidad de baudios o hardware dañado).
  - El microcontrolador entra en reinicios repetidos o muestra errores críticos.
- Documentación:
  - Registro de número de serie del dispositivo probado (si aplica.
  - Bitácora de eventos observados en consola durante la sesión.
  - Confirmación de comportamiento esperado del firmware.
  - Observaciones relevantes (ej. tiempos de respuesta, temperatura de operación, consistencia de comunicación).

6.4 Observaciones sobre placa alternativa basada en el diseño principal

Durante la etapa de pruebas y validación, se diseñó una segunda versión de la placa con el objetivo de desarrollar un sistema capaz de medir ciertos parámetros del agua en quebradas, alimentado por dos celdas de batería. Esta nueva versión incorporó un módulo RTC y un gestor de carga de baterías MP2639, permitiendo que el sistema se alimente automáticamente desde batería cuando se desconecte la entrada USB, y que se cargue la batería cuando el USB esté conectado.

6.4.1 Error detectado: pin PB sin configuración adecuada

Uno de los problemas detectados en esta placa fue el manejo incorrecto del pin PB (Push Button Input) del MP2639. En el esquemático original, el pin PB no fue conectado a ningún componente. Al detectar esta omisión una vez fabricada la PCB, se intentó corregir mediante la conexión directa de un botón entre PB y tierra (GND). Sin embargo, no se incorporó una resistencia de pull-up externa a VCC, lo que provocó que el pin quedara flotante cuando el botón no era presionado, generando un comportamiento errático.

Cabe mencionar que se deben revisar otras conexiones del MP2639, ya que podrían existir errores adicionales no detectados durante esta fase preliminar.

6.4.2 Consecuencia observada

Durante las pruebas realizadas:

- Al presionar brevemente el botón, se activaba el modo de descarga del MP2639.
- No obstante, no se activaba el voltaje de salida VL, por lo que la placa no era alimentada correctamente desde la batería.
- El sistema comenzaba a descargar la batería, pero sin energizar el resto del circuito, lo que se identificó como una falla crítica.

Este comportamiento coincide con la información técnica del datasheet del MP2639, en el cual se explica que:

“When PB is pushed for less than 2.5s, the discharge function is enabled and latched when MODE is high. If discharging is enabled, push PB for more than 2.5s to disable the discharge. Otherwise, discharging remains, and LED1-4 are enabled for 5s.”

En los diagramas de aplicación del fabricante, se sugiere explícitamente conectar el pin PB mediante un botón hacia GND, acompañado de una resistencia de pull-up externa (típicamente de 10kΩ) a VCC. Esta configuración asegura un nivel lógico alto cuando el botón no está presionado y permite que el sistema reconozca correctamente los eventos de entrada por pulsación.

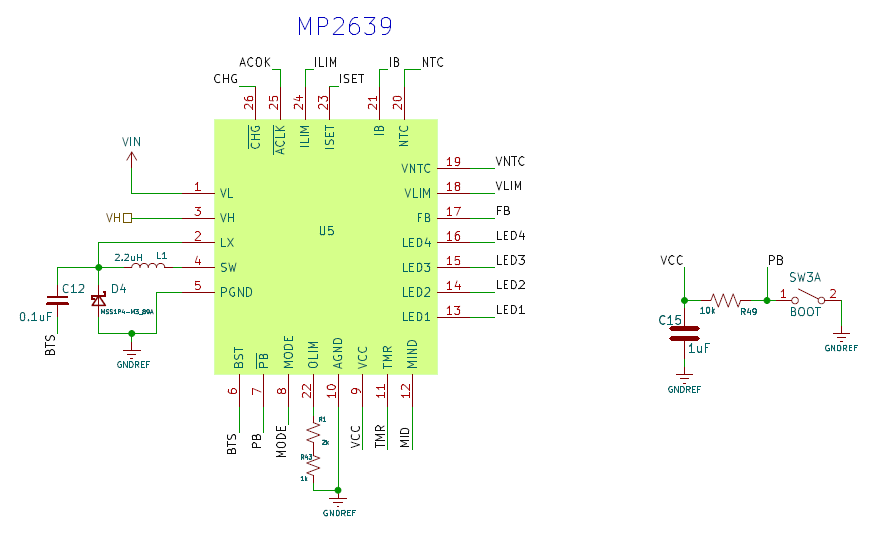
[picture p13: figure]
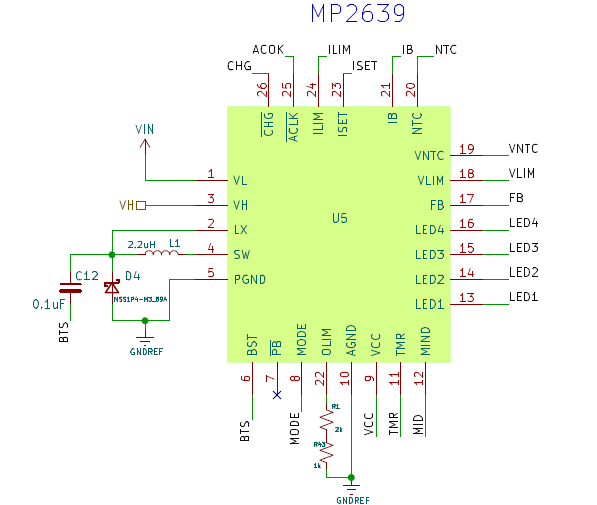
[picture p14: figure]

Figura 6.12 Error de conexión: pin PB Figura 6.13 Conexión corregida del sin configurar en esquemático original. Pin PB con resistencia pull-up y botón a tierra.

7. Documentación

Esta sección describe los documentos técnicos generados durante el desarrollo del proyecto. Si bien algunos elementos ya han sido explicados en las secciones anteriores, aquí se organiza de forma estructurada todo el conjunto de entregables que forman parte del diseño completo del sistema.

7.1 Documentos Generados

- Diseño Eléctrico (Esquemático): El circuito principal fue desarrollado en entorno KiCad. El archivo PDF correspondiente será incluido como parte del entregable técnico.
- Diseño de PCB (Layout): El diseño físico del circuito impreso fue realizado con base en el esquemático anterior. Se incluyen consideraciones de enroutado, tamaños de pads y restricciones de manufactura.

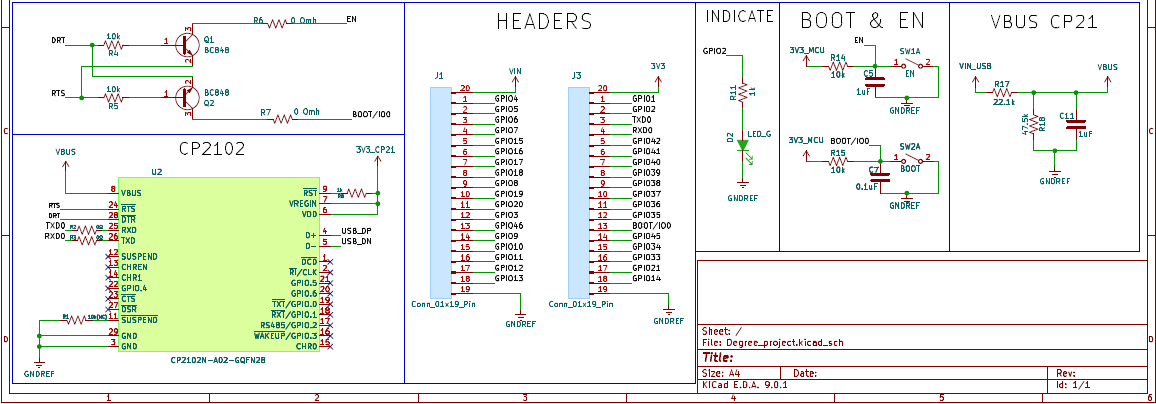
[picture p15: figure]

- Lista de Materiales (BOM): Contiene los componentes utilizados, junto con valores, referencias, encapsulados y códigos de fabricante. Aunque no se incluye en este documento debido a su extensión, forma parte del conjunto de archivos generados desde el software de diseño electrónico y puede ser entregado por separado si se requiere.

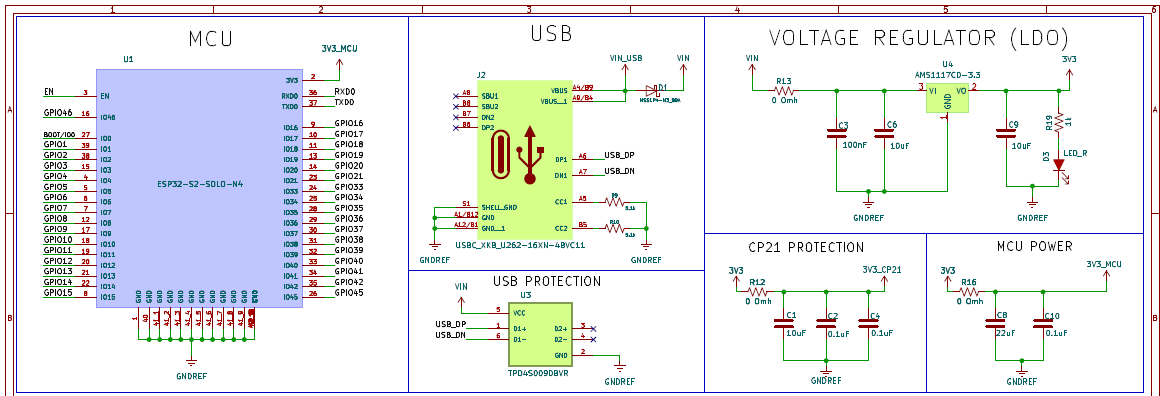
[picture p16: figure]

Figura 7.1 Esquemático diseño placa de desarrollo basado en ESP32

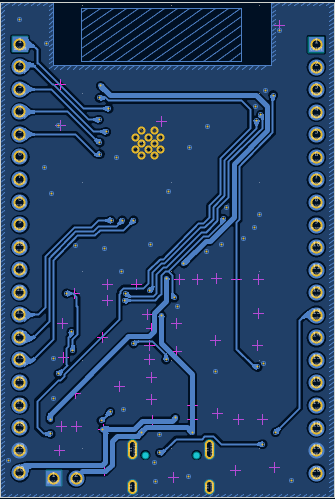
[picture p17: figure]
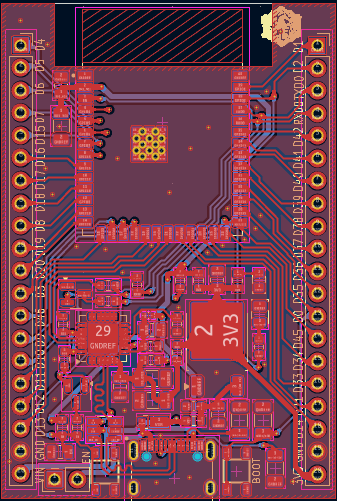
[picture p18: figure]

Figura 7.2 Lyout del PCB

7.1.2 Documentación de Diseño

La documentación técnica generada incluye tanto el esquemático eléctrico como el diseño físico del PCB, ambos elaborados en el software KiCad. Esta información permite comprender la distribución funcional de los componentes y facilita procesos como validación, depuración y fabricación.

- Figura 7.1 muestra el esquemático eléctrico del sistema, organizado por bloques funcionales: microcontrolador (MCU), interfaz USB, reguladores de voltaje, protección ESD, conversión USB-UART y encabezados para pruebas o expansión. Este diagrama permite identificar fácilmente la conectividad entre señales y la asignación de pines.
- Figura 7.2 presenta el layout del PCB, con una vista de las capas superior (Top Layer) e inferior (Bottom Layer). El diseño contempla consideraciones de integridad de señal, rutas optimizadas para alimentación y datos, y un tamaño compacto. Las zonas de cobre (pours) están dedicadas a planos de GND y alimentación, lo que mejora el rendimiento eléctrico y térmico del sistema.

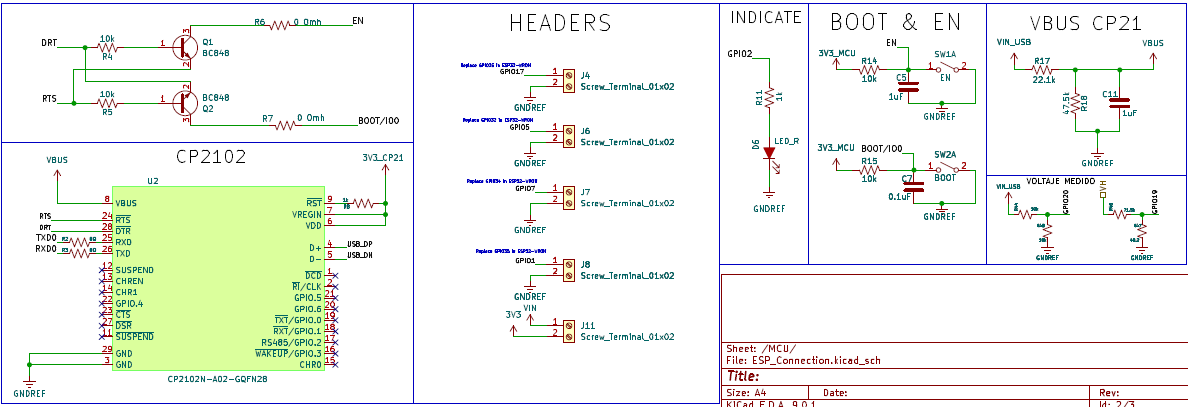
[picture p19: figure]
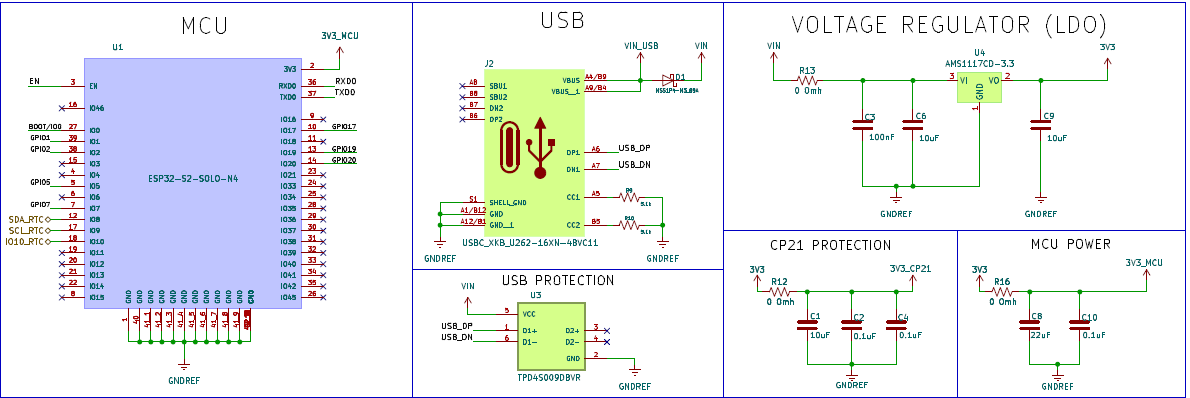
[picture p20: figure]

7.2 Documentación segunda placa con RTC y gestor de energía inteligente MP2639.

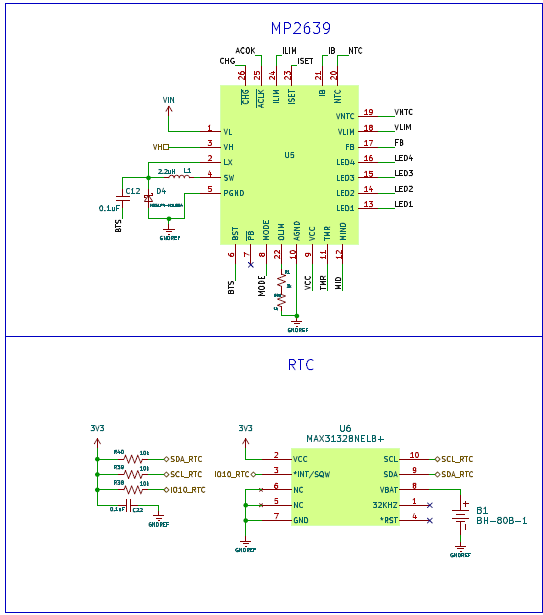
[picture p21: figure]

Figura 7.3 Esquemático de la segunda placa, con RTC MAX31328NE y gestor de carga MP2639.

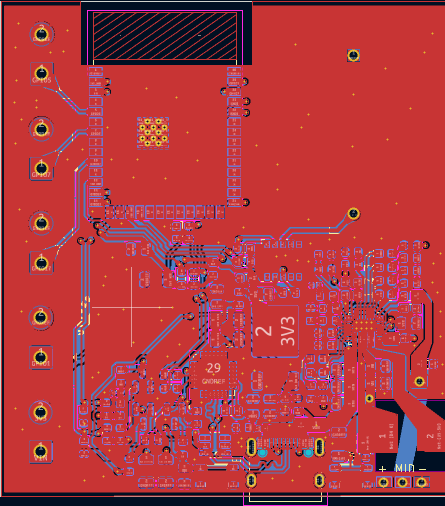
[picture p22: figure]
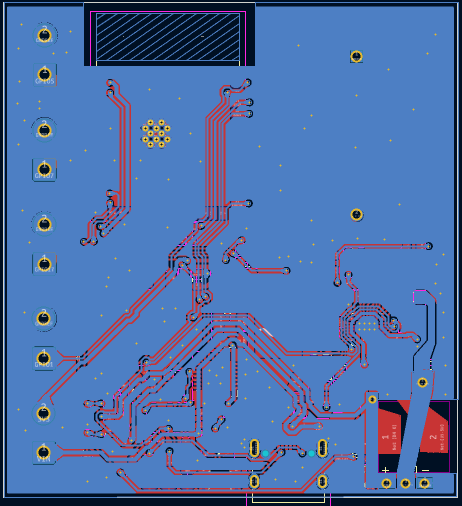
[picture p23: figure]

Figura 7.4 Lyout del PCB

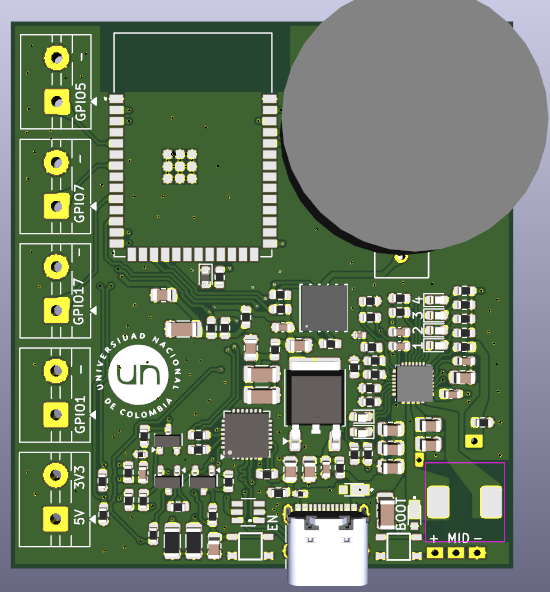
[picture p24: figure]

Figura 7.5 Vista 3D de la segunda placa de desarrollo

8. Referencias Bibliográficas

8.1 Normas y Estándares

- IPC-2221A. Generic Standard on Printed Board Design. IPC Association.
- IPC-A-610. Acceptability of Electronic Assemblies. IPC Association.
- IEEE 802.11. Wireless LAN Medium Access Control and Physical Layer Specifications. IEEE.
- ISO 9001. Quality Management Systems – Requirements. International Organization for Standardization.

8.2 Literatura Técnica

- Bogatin, E. Signal and Power Integrity – Simplified. Prentice Hall, 2nd Ed., 2009.
- Johnson, H., & Graham, M. High-Speed Digital Design: A Handbook of Black Magic. Prentice Hall, 1993.
- Montrose, M. EMC and the Printed Circuit Board: Design, Theory, and Layout Made Simple. Wiley-IEEE Press, 2000.

8.3 Recursos Online

- Altium Designer Documentation. Disponible en: https://www.altium.com/documentation
- Texas Instruments. USB Type-C® Basics. Document Number: SLYY228. Disponible en: https://www.ti.com/lit/eb/slyy228/slyy228.pdf

Conclusiones

El desarrollo del sistema basado en el microcontrolador ESP32-S2 permitió integrar de forma exitosa las funcionalidades previstas, desde el diseño esquemático hasta la validación en hardware real. A lo largo del proyecto se abordaron todas las etapas clave del ciclo de desarrollo electrónico, incluyendo selección de componentes, diseño de esquemático, layout del PCB, validación funcional y documentación técnica.

Se logró establecer una comunicación estable por USB mediante la interfaz CP2102, así como pruebas funcionales básicas utilizando el GPIO2 como indicador visual (LED). La integración con ESP-IDF demostró compatibilidad con el entorno de desarrollo y facilitó la depuración durante las etapas de prueba.

El diseño del PCB fue realizado teniendo en cuenta las restricciones de manufactura y aplicando buenas prácticas de distribución de señales, alimentación y planos de referencia. Esto permitió obtener una placa funcional y confiable.

Además, toda la documentación técnica generada facilita la comprensión del sistema, permitiendo su reproducción, depuración y mejora en futuras versiones.

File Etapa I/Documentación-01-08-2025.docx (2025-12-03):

Diseño y Análisis Teórico de un Sistema Autónomo de Monitoreo de Calidad del Agua

Realizado por: Maria Alejandra Gonzalez Duque

1. Arquitectura del Sistema y Principios de Diseño

1.1. Introducción

El monitoreo continuo e in situ de la calidad del agua es un pilar fundamental para la salvaguarda de la salud ecológica de los ecosistemas acuáticos y la seguridad del suministro de agua para consumo humano. Los métodos tradicionales, que dependen de la recolección manual de muestras y su posterior análisis en laboratorio, son costosos, laboriosos y ofrecen una resolución temporal limitada, lo que impide la detección de eventos de contaminación transitorios. En respuesta a estas limitaciones, los sistemas de monitoreo basados en el Internet de las Cosas han surgido como una alternativa escalable y costo-efectiva, permitiendo la recolección de datos de alta frecuencia directamente en el campo.

Este documento presenta el diseño y el análisis teórico de un nodo de monitoreo de calidad del agua autónomo, de bajo consumo y multiparamétrico. El objetivo principal del proyecto es desarrollar un kit de medición robusto, capaz de operar de manera desatendida en un cuerpo de agua como un río durante un período de dos días, registrando parámetros clave para la caracterización del agua. El sistema está diseñado para optimizar la autonomía energética mediante estrategias avanzadas de bajo consumo, almacenar las mediciones de forma persistente y transmitirlas a una estación base para su visualización y análisis.

1.2. Visión General del Sistema y Arquitectura de Alto Nivel

El sistema se concibe como un dispositivo electrónico integrado, compuesto por cuatro bloques funcionales principales que operan de manera coordinada bajo el control de un microcontrolador central. La arquitectura está diseñada para equilibrar la capacidad de medición, la eficiencia energética y la conectividad.

Los bloques funcionales son:

1. Unidad Central de Procesamiento (CPU): El núcleo del sistema es un microcontrolador ESP32. Este componente es responsable de orquestar todas las operaciones: gestionar los ciclos de sueño y despertar, inicializar y leer los datos de los sensores, procesar las señales, almacenar los resultados y manejar la comunicación inalámbrica.
2. Conjunto de Sensores (Sensor Array): Un grupo de sensores seleccionados para medir cuatro parámetros fundamentales de la calidad del agua:
  - Turbidez: Sensor analógico SEN0189.
  - Sólidos Disueltos Totales (TDS): Sensor analógico SEN0244.
  - Potencial de Hidrógeno (pH): Sensor analógico SEN0161-V2.
  - Temperatura: Sensor digital DS18B20.
3. Subsistema de Alimentación (Power Management Subsystem): Diseñado para la operación autónoma con baterías. Consiste en dos baterías de ion de litio de 3.7 V conectadas en serie, un chip MP2639A que es un dispositivo de gestión de carga de baterías en modo conmutado, altamente integrado y flexible, diseñado específicamente para paquetes de baterías de ion de 2 celdas en serie. Su característica principal es su operación bidireccional, que le permite tanto cargar la batería desde una fuente de 5V como alimentar un sistema a 5V desde la batería e incluye un sistema buck para reducir el voltaje de 5 V a 3.3 V.
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

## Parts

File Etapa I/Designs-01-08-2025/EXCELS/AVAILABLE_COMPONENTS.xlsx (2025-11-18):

AVAILABLE COMPONENTS
Index | Reference Designator | Component | Manufacturer Part Number | Manufacturer Name | Pack Quantity | Distributor | Package | Description | Munting Style | Pack Type
1 | U1 | MCU | ESP32-S2-SOLO | Espressif Systems | 6 | Mouser | 40-SMD Module | WiFi 802.11b/g/n Transceiver Module 2.4GHz PCB Trace Surface Mount | SMD/SMT | Cut Tape (CT)
2 | U2 | spiFlash | W25Q80DVSSIG | Winbond | 3 | Mouser | SOIC-8 | NOR Flash spiFlash, 8M-bit, 4Kb Uniform Sector | SMD/SMT | Cut Tape (CT)
3 | U3 | USB Interface | CP2102N-A02-GQFN28 | Silicon Labs | 1 (Falla TX) | Mouser | QFN-28 | USB Interface IC USBXpress - USB to UART Bridge QFN28 | SMD/SMT | Cut Tape (CT)
4 | U4 | ESD Protection Diodes | TPD4S009DBVR | Texas Instruments | 1 | Mouser | SOT-23-6 | ESD Protection Diodes / TVS Diodes 4Ch ESD Sol for Hi S peed Diff Interface | SMD/SMT | Cut Tape (CT)
5 | B1 | LDO | ADP150AUJZ-3.3-R7 | Analog Devices | 3 | Mouser | TSOT-23-5 | Linear Voltage Regulators 150mA Ultra-Low Noise LDO 3.3 Vout | SMD/SMT | Cut Tape (CT)
6 | LED1 | Red LED | TLMS1100-GS08 | Vishay Semiconductors | 3 | Mouser | 0603 (1608 Metric) | Single Color LEDs Red Non-Diffused | SMD/SMT | Cut Tape (CT)
7 | D | Schottky Diode | MSS1P4-M3_89A | Vishay General Semiconductor | 5 | Mouser | DO-219AD-2 | Schottky Diodes & Rectifiers 1.0 Amp 40 Volt | SMD/SMT | Cut Tape (CT)
8 | C1 | Capacitor 10uF 16V | GRM21BR61C106KE15L | Murata Electronics | 89 | Mouser | 0805 (2012 Metric) | Multilayer Ceramic Capacitors MLCC - SMD/SMT 10 uF 16 VDC 10% 0805 X5R | SMD/SMT | Cut Tape (CT)
9 | C2 | Capacitor 10uF 25V | GRM21BR61E106KA73L | Murata Electronics | 6 | Mouser | 0805 (2012 Metric) | Multilayer Ceramic Capacitors MLCC - SMD/SMT 10 uF 25 VDC 10% 0805 X5R | SMD/SMT | Cut Tape (CT)
10 | C3 | Capacitor 0,1uF 100V | C1206C104K1RACTU | KEMET | 88 | Mouser | 1206 (3216 Metric) | Multilayer Ceramic Capacitors MLCC - SMD/SMT 100V 0.1uF X7R 1206 10% | SMD/SMT | Cut Tape (CT)
11 | C4 | Capacitor 100nF 6,3V | CL03A104KQ3NNNH | Samsung Electro-Mechanics | 5 | Mouser | 0201 (0603 Metric) | Multilayer Ceramic Capacitors MLCC - SMD/SMT 100nF+/-10% 6.3V X5R 0201 | SMD/SMT | Cut Tape (CT)
12 | C5 | Capacitor 1uF 16V | CC0805KKX7R7BB105 | YAGEO | 2 | Mouser | 0805 (2012 Metric) | Multilayer Ceramic Capacitors MLCC - SMD/SMT 16V 1uF X7R 0805 10% HI CV | SMD/SMT | Cut Tape (CT)
13 | C6 | Capacitor 22uF 6.3VDC | GRM21BR60J226ME39L | Murata Electronics | 6 | Mouser | 0805 (2012 Metric) | Multilayer Ceramic Capacitors MLCC - SMD/SMT 22 uF 6.3 VDC 20% 0805 X5R | SMD/SMT | Cut Tape (CT)
14 | C7 | Capacitor 22nF 50V | CL21B223KBANNNC | Samsung Electro-Mechanics | 8 | Mouser | 0805 (2012 Metric) | Multilayer Ceramic Capacitors MLCC - SMD/SMT 22nF+/-10% 50V X7R 2 0805 | SMD/SMT | Cut Tape (CT)
15 | R1 | Resistor 10k | CR0603-FX-1002ELF | Bourns | 72 | Mouser | 0603 (1608 Metric) | Thick Film Resistors - SMD 10K 1% 1/10W | SMD/SMT | Cut Tape (CT)
16 | R2 | Resistor 0 Omh | RC0603JR-070RL | YAGEO | 2 | Mouser | 0603 (1608 Metric) | Thick Film Resistors - SMD 0 Ohms 100 mW 0603 5% | SMD/SMT | Cut Tape (CT)
17 | R3 | Resistor 1k | AC0603FR-071KL | YAGEO | 88 | Mouser | 0603 (1608 Metric) | Thick Film Resistors - SMD 1 k Ohms 100m W 0603 1% AEC-Q200 Standard Power Version | SMD/SMT | Cut Tape (CT)
18 | R4 | Resistor 2k | RC0603FR-072KL | YAGEO | 5 | Mouser | 0603 (1608 Metric) | Thick Film Resistors - SMD 2 kOhms 100mW 0603 1% | SMD/SMT | Cut Tape (CT)
19 | R5 | Resistor 22.1k | RC0402FR-0722K1L | YAGEO | 3 | Mouser | 0402 (1005 Metric) | Thick Film Resistors - SMD 22.1 kOhms 62.5mW 0402 1% | SMD/SMT | Cut Tape (CT)
20 | R6 | Resistor 47.5k | CRCW060347K5FKEA | Vishay / Dale | 1 | Mouser | 0603 (1608 Metric) | Thick Film Resistors - SMD 1/10watt 47.5Kohms 1% | SMD/SMT | Cut Tape (CT)
21 | R7 | Resistor 20k | AC0603FR-0720KL | YAGEO | 8 | Mouser | 0603 (1608 Metric) | Thick Film Resistors - SMD 20 kOhms 100mW 0603 1% AEC-Q200 Standard Power Version | SMD/SMT | Cut Tape (CT)
22 | Q | Transistor BJT | BC848CLT1G | onsemi | 2 | Mouser | SOT-23-3 | Bipolar Transistors - BJT 100mA 30V NPN | SMD/SMT | Cut Tape (CT)
23 | SW | Switch | PTS810SJG250SMTR LFS | C&K | 2 | Mouser |  | Tactile Switches Microminiature SMT Top Actuated | SMD/SMT | Cut Tape (CT)
24 | J1 | USB Connector | 651305142821 | Wurth Elektronik | 2 | Mouser |  | USB Connectors WR-COM Type AB SMT 5Pin Horztl FemlMini | SMD/SMT | Cut Tape (CT)
25 | J2 | Headers & Wire Housings | SSW-105-01-G-S | Samtec | 2 | Mouser | Bulk | Headers & Wire Housings Tiger Buy(TM) Socket Strip with PCB Tails | Through Hole | Cut Tape (CT)
26 | J3 | Headers & Wire Housings | 61300411121 | Wurth Elektronik | 6 | Mouser | Bulk | Headers & Wire Housings WR-PHD 2.54mm Hdr 4P Single Str Gold | Through Hole | Cut Tape (CT)
27 | C8 | Capacitor 100nF 16V | CC0603KPX7R7BB104 | YAGEO | 5 | Digi-Key | 0603 (1608 Metric) | 0.1 µF ±10% 16V Ceramic Capacitor X7R 0603 (1608 Metric) | SMD/SMT | Cut Tape (CT)
28 | C9 | Capacitor 33pF 10V | 885012005010 | Würth Elektronik | 8 | Digi-Key | 0402 (1608 Metric) | 33 pF ±5% 10V Ceramic Capacitor C0G, NP0 0603 (1608 Metric) | SMD/SMT | Cut Tape (CT)
29 | R8 | Resistor 27.4k | RC0603FR-0727K4L | YAGEO | 6 | Digi-Key | 0603 (1608 Metric) | 27.4 kOhms ±1% 0.1W, 1/10W Chip Resistor 0603 (1608 Metric) Moisture Resistant Thick Film | SMD/SMT | Cut Tape (CT)
30 | R9 | Resistor 71,5k | RC0603FR-0771K5L | YAGEO | 7 | Digi-Key | 0603 (1608 Metric) | 71.5 kOhms ±1% 0.1W, 1/10W Chip Resistor 0603 (1608 Metric) Moisture Resistant Thick Film | SMD/SMT | Cut Tape (CT)
31 | R10 | Resistor 86,6k | RC0603FR-0786K6L | YAGEO | 8 | Digi-Key | 0603 (1608 Metric) | 86.6 kOhms ±1% 0.1W, 1/10W Chip Resistor 0603 (1608 Metric) Moisture Resistant Thick Film | SMD/SMT | Cut Tape (CT)
32 | R11 | Resistor 100 Ohm | RC0603JR-07100RL | YAGEO | 9 | Digi-Key | 0603 (1608 Metric) | 100 Ohms ±5% 0.1W, 1/10W Chip Resistor 0603 (1608 Metric) Moisture Resistant Thick Film | SMD/SMT | Cut Tape (CT)
33 | R12 | Resistor 40,2 k | RC0603FR-1340K2L | YAGEO | 8 | Digi-Key | 0603 (1608 Metric) | 40.2 kOhms ±1% 0.1W, 1/10W Chip Resistor 0603 (1608 Metric) Thick Film | SMD/SMT | Cut Tape (CT)
34 | R13 | Thermistor 10k | ERT-J1VG103FA | Panasonic Electronic Components | 5 | Digi-Key | 0603 (1608 Metric) | THERMISTOR NTC 10KOHM 3380K 0603 | SMD/SMT | Cut Tape (CT)
35 | LED2 | Green LED | LTST-C191KGKT | Lite-On Inc. | 6 | Digi-Key | 0603 (1608 Metric) | Green 571nm LED Indication - Discrete 2V 0603 (1608 Metric) | SMD/SMT | Cut Tape (CT)
36 | L1 | Inductor 22 uH | 0630CDMCCDS-2R2MC | Sumida America Components Inc. | 1 | Digi-Key |  | 2.2 µH Shielded Molded Inductor 9.3 A 15mOhm Max Nonstandard | SMD/SMT | Cut Tape (CT)
37 | U5 | Charguer IC | MP2639AGR-Z | Monolithic Power Systems Inc. | 1 | Digi-Key | 26-QFN (4x4) | Charger IC Lithium Ion/Polymer 26-QFN (4x4) | SMD/SMT | Cut Tape (CT)
38 | Q2 | Transistor Chanel-N | PJA3404-AU_R1_000A1 | Panjit International Inc. | 4 | Digi-Key | SOT-23 | N-Channel 30 V 5.6A (Ta) 1.25W (Ta) Surface Mount SOT-23 | SMD/SMT | Cut Tape (CT)
39 | J4 | USB-C | UJ20-C-H-G-SMT-1-P16-TR | Same Sky (Formerly CUI Devices) | 2 | Digi-Key |  | USB JACK, TYPE C,2.0, HORIZONTAL | Surface Mount, Right Angle; Through Hole | Cut Tape (CT)
40 | J5 | Battery Holder | BH-80B-1 | Adam Tech | 1 | Digi-Key |  | Battery Holder (Open) Coin, 20.0mm 1 Cell PC Pin | Through Hole | Bulk
41 | U6 | RTC | MAX31328NELB+ | Analog Devices Inc./Maxim Integrated | 1 | Digi-Key | 10-LGA (5x5) | Real Time Clock (RTC) IC Clock/Calendar I2C 10-LLGA | SMD/SMT | Cut Tape (CT)
42 | U7 | LDO | AMS1117CD-3.3 | UMW(Youtai Semiconductor Co., Ltd.) | 8 | Digi-Key | TO-252-2 | 1A Fixed 3.3V Positive electrode 18V TO-252-2 Voltage Regulators - Linear, Low Drop Out (LDO) Regulators ROHS | SMD/SMT | Cut Tape (CT)

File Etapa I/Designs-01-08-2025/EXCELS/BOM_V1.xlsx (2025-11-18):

BOM
Index | Reference Designator | Manufacturer Part Number | Manufacturer Name | Pack Quantity | Pack Type | Digi-Key Part Number | Package | Munting Style | Description | Datasheet | Unit Price | Extended Price
1 | C3, Cc4, Cc8 | CC0603KPX7R7BB104 | YAGEO | 10 | Cut Tape (CT) | 311-1335-1-ND | 0603 (1608 Metric) | SMD/SMT | 0.1 µF ±10% 16V Ceramic Capacitor X7R 0603 (1608 Metric) | https://www.yageo.com/upload/media/product/productsearch/datasheet/mlcc/UPY-GPHC_X7R_6.3V-to-250V_24.pdf | $0.01400 | $0.14
2 | Cc9 | 885012006005 | Würth Elektronik | 10 | Cut Tape (CT) | 732-7428-1-ND | 0603 (1608 Metric) | SMD/SMT | 33 pF ±5% 10V Ceramic Capacitor C0G, NP0 0603 (1608 Metric) | https://www.we-online.com/components/products/datasheet/885012006005.pdf | $0.02700 | $0.27
3 | Rc1, Rc2 | RC0603FR-0727K4L | YAGEO | 10 | Cut Tape (CT) | 311-27.4KHRCT-ND | 0603 (1608 Metric) | SMD/SMT | 27.4 kOhms ±1% 0.1W, 1/10W Chip Resistor 0603 (1608 Metric) Moisture Resistant Thick Film | https://www.yageo.com/upload/media/product/products/datasheet/rchip/PYu-RC_Group_51_RoHS_L_12.pdf | $0.00700 | $0.07
4 | Rc15 | RC0603FR-0771K5L | YAGEO | 10 | Cut Tape (CT) | 311-71.5KHRCT-ND | 0603 (1608 Metric) | SMD/SMT | 71.5 kOhms ±1% 0.1W, 1/10W Chip Resistor 0603 (1608 Metric) Moisture Resistant Thick Film | https://www.yageo.com/upload/media/product/app/datasheet/rchip/pyu-af_51_rohs_l.pdf | $0.01000 | $0.10
5 | Rc14 | RC0603FR-0786K6L | YAGEO | 10 | Cut Tape (CT) | 311-86.6KHRCT-ND | 0603 (1608 Metric) | SMD/SMT | 86.6 kOhms ±1% 0.1W, 1/10W Chip Resistor 0603 (1608 Metric) Moisture Resistant Thick Film | https://www.yageo.com/upload/media/product/app/datasheet/rchip/pyu-af_51_rohs_l.pdf | $0.00900 | $0.09
6 | Rc3 | RC0603JR-07100RL | YAGEO | 10 | Cut Tape (CT) | 311-100GRCT-ND | 0603 (1608 Metric) | SMD/SMT | 100 Ohms ±5% 0.1W, 1/10W Chip Resistor 0603 (1608 Metric) Moisture Resistant Thick Film | https://www.yageo.com/upload/media/product/products/datasheet/rchip/PYu-RC_Group_51_RoHS_L_12.pdf | $0.00800 | $0.08
7 | Rc12 | RC0603FR-1340K2L | YAGEO | 10 | Cut Tape (CT) | 13-RC0603FR-1340K2LCT-ND | 0603 (1608 Metric) | SMD/SMT | 40.2 kOhms ±1% 0.1W, 1/10W Chip Resistor 0603 (1608 Metric) Thick Film | https://www.yageo.com/upload/media/product/products/datasheet/rchip/PYu-RC_Group_51_RoHS_L_12.pdf | $0.00900 | $0.09
8 | Rc11, Rc18 | ERT-J1VG103FA | Panasonic Electronic Components | 5 | Cut Tape (CT) | P12011CT-ND | 0603 (1608 Metric) | SMD/SMT | THERMISTOR NTC 10KOHM 3380K 0603 | https://industrial.panasonic.com/ww/products/pt/ntc-thermistor/models/ERTJ1VG103FA | $0.14600 | $0.73
9 | LED2,LED5,LED1,LED4,LED3 | LTST-C191KGKT | Lite-On Inc. | 10 | Cut Tape (CT) | 160-1446-1-ND | 0603 (1608 Metric) | SMD/SMT | Green 571nm LED Indication - Discrete 2V 0603 (1608 Metric) | https://optoelectronics.liteon.com/upload/download/DS22-2000-228/LTST-C191KGKT.PDF | $0.10000 | $1.00
10 | Lc1 | 0630CDMCCDS-2R2MC | Sumida America Components Inc. | 2 | Cut Tape (CT) | 308-2464-1-ND |  | SMD/SMT | 2.2 µH Shielded Molded Inductor 9.3 A 15mOhm Max Nonstandard | https://products.sumida.com/products/pdf/0630CDMCDDS.pdf | $0.70000 | $1.40
11 | Uc1 | MP2639AGR-Z | Monolithic Power Systems Inc. | 2 | Cut Tape (CT) | 1589-1618-1-ND | 26-QFN (4x4) | SMD/SMT | Charger IC Lithium Ion/Polymer 26-QFN (4x4) | https://www.monolithicpower.com/en/documentview/productdocument/index/version/2/document_type/Datasheet/lang/en/sku/MP2639A/document_id/1451 | $4.87000 | $9.74
12 | Qc1 | PJA3404-AU_R1_000A1 | Panjit International Inc. | 5 | Cut Tape (CT) | 3757-PJA3404-AU_R1_000A1CT-ND | SOT-23 | SMD/SMT | N-Channel 30 V 5.6A (Ta) 1.25W (Ta) Surface Mount SOT-23 | https://www.panjit.com.tw/upload/datasheet/PJA3404-AU.pdf | $0.29000 | $1.45
13 | J2, Jc1 | UJ20-C-H-G-SMT-1-P16-TR | Same Sky (Formerly CUI Devices) | 10 | Cut Tape (CT) | 2223-UJ20-C-H-G-SMT-1-P16-TRCT-ND |  | Surface Mount, Right Angle; Through Hole | USB JACK, TYPE C,2.0, HORIZONTAL | https://www.sameskydevices.com/product/resource/uj20-c-h-g-smt-1-p16-tr.pdf | $0.39200 | $3.92
14 | Jr1 | BH-80B-1 | Adam Tech | 2 | Bulk | 2057-BH-80B-1-ND |  | Through Hole | Battery Holder (Open) Coin, 20.0mm 1 Cell PC Pin | https://app.adam-tech.com/products/download/data_sheet/196963/bh-80b-1-data-sheet.pdf | $0.41000 | $0.82
15 | Ur1 | MAX31328NELB+ | Analog Devices Inc./Maxim Integrated | 2 | Cut Tape (CT) | 505-MAX31328NELB+-ND | 10-LGA (5x5) | SMD/SMT | Real Time Clock (RTC) IC Clock/Calendar I2C 10-LLGA | https://www.analog.com/media/en/technical-documentation/data-sheets/max31328.pdf | $4.94000 | $9.88
16 | U4 | AMS1117CD-3.3 | UMW(Youtai Semiconductor Co., Ltd.) | 10 | Cut Tape (CT) | 4518-AMS1117CD-3.3CT-ND | TO-252-2 | SMD/SMT | 1A Fixed 3.3V Positive electrode 18V TO-252-2 Voltage Regulators - Linear, Low Drop Out (LDO) Regulators ROHS | https://mm.digikey.com/Volume0/opasdata/d220001/medias/docus/5011/AMS1117.pdf | $0.57500 | $5.75
 |  |  |  |  |  |  |  |  |  |  |  | $35.53

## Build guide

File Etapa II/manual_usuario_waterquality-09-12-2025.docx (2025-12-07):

# MANUAL DE USUARIO

## SISTEMA DE MONITOREO DE CALIDAD DEL AGUA

Universidad: Universidad Nacional de Colombia

Autores: Daniel Felipe Acosta Castro – Oscar Santiago Erazo Mora

Año: 2025

Versión del documento: 1.0

## 1. INTRODUCCIÓN

### Objetivo del documento

Este manual tiene como objetivo proporcionar una guía completa y detallada para la instalación, configuración y uso del Sistema de Monitoreo de Calidad del Agua. El documento está diseñado para que usuarios con conocimientos básicos en electrónica y programación puedan implementar y operar el sistema de manera exitosa.

### Alcance

El manual cubre todos los aspectos necesarios para poner en funcionamiento el sistema, desde la preparación del entorno de desarrollo hasta la visualización de datos en la interfaz web, incluyendo la conexión física de los sensores y la solución de problemas comunes.

[Espacio para imagen: Diagrama general del sistema]

## 2. DESCRIPCIÓN DEL SISTEMA

El Sistema de Monitoreo de Calidad del Agua es una solución autónoma basada en la placa ESP32 que permite medir y registrar cuatro parámetros fundamentales de la calidad del agua:

- pH: Mide el nivel de acidez o alcalinidad del agua
- Temperatura: Registra la temperatura del agua en grados Celsius
- TDS (Sólidos Totales Disueltos): Cuantifica la concentración de partículas disueltas en el agua
- Turbidez: Evalúa la claridad del agua midiendo la dispersión de luz

El sistema opera de forma autónoma, tomando mediciones periódicas y almacenándolas localmente. Los datos pueden ser consultados y visualizados a través de una interfaz web cuando el dispositivo se conecta a internet.

### Componentes principales

- Placa de desarrollo ESP32
- Cuatro sensores de calidad del agua (pH, temperatura, TDS, turbidez)
- Módulo RTC (Reloj de Tiempo Real) con batería de respaldo
- Servidor web para visualización de datos
- Sistema de almacenamiento local de datos

[Espacio para imagen: Componentes del sistema ensamblados]

## 3. REQUISITOS DEL SISTEMA

### Hardware necesario

- Computador con puerto USB (Windows, macOS o Linux)
- Placa ESP32 con cable USB tipo C
- Sensores de calidad del agua DFRobot:
  - Sensor de pH (analógico)
  - Sensor de temperatura DS18B20 (digital)
  - Sensor TDS (analógico)
  - Sensor de turbidez (analógico)
- Módulo RTC con batería de 3.3V
- Fuente de alimentación 5V (si se requiere operación autónoma)

### Software necesario

- Visual Studio Code (última versión)
- Extensión PlatformIO para VSCode
- Drivers CP210x USB to UART Bridge VCP
- Navegador web moderno (Chrome, Firefox, Edge)

### Conocimientos previos recomendados

- Manejo básico de Visual Studio Code
- Conceptos básicos de electrónica (voltaje, corriente, tierra)
- Navegación en interfaces web

## 4. INSTALACIÓN DEL ENTORNO DE DESARROLLO

### 4.1 Configuración para la ESP32

La programación de la ESP32 se realiza utilizando Visual Studio Code con la extensión PlatformIO, que facilita el desarrollo, compilación y carga de programas para microcontroladores.

#### Paso 1: Instalar Visual Studio Code

1. Descargue Visual Studio Code desde la página oficial: https://code.visualstudio.com/
2. Ejecute el instalador y siga las instrucciones en pantalla
3. Complete la instalación y abra Visual Studio Code

[Espacio para imagen: Pantalla de instalación de VSCode]

#### Paso 2: Instalar la extensión PlatformIO

1. Abra Visual Studio Code
2. Haga clic en el ícono de extensiones en la barra lateral izquierda (o presione Ctrl+Shift+X)
3. En el cuadro de búsqueda, escriba "PlatformIO IDE"
4. Haga clic en el botón "Install" de la extensión oficial de PlatformIO
5. Espere a que finalice la instalación (puede tomar varios minutos)

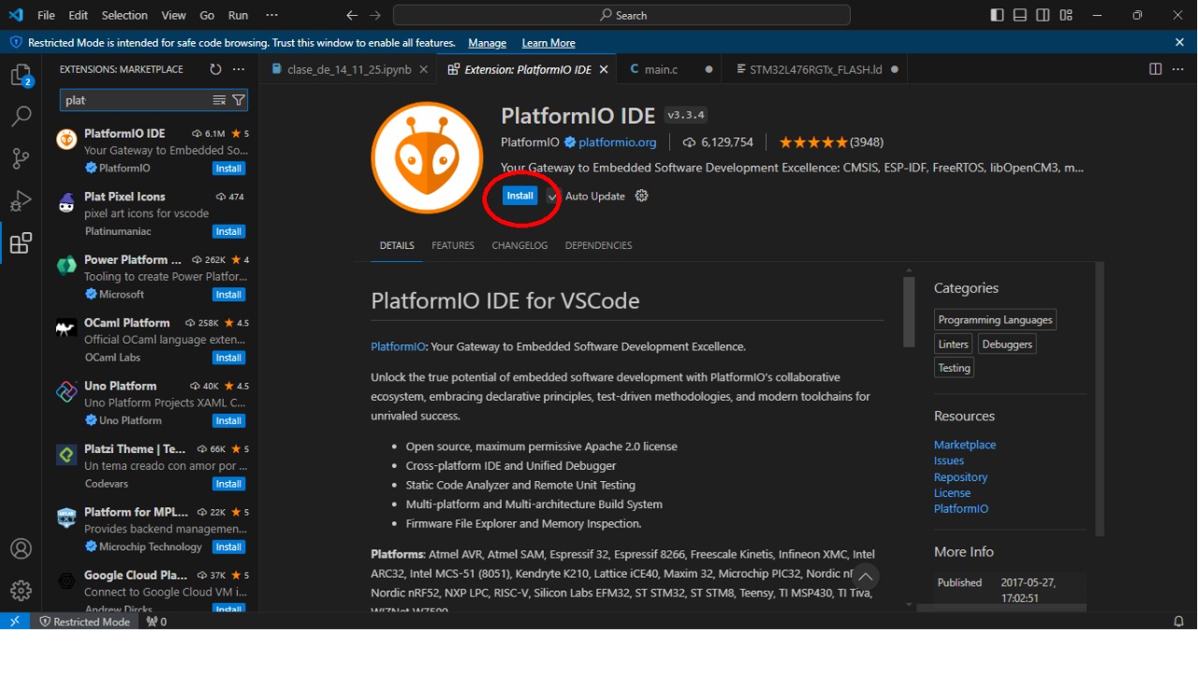
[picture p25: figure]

#### Paso 3: Abrir el proyecto

1. Una vez instalada la extensión, verá un nuevo ícono de PlatformIO en la barra lateral izquierda
2. Haga clic en el ícono de PlatformIO
3. Seleccione "Open" en el menú de PlatformIO Home
4. Navegue hasta la carpeta donde descargó el proyecto
5. Seleccione la carpeta del proyecto ESP32

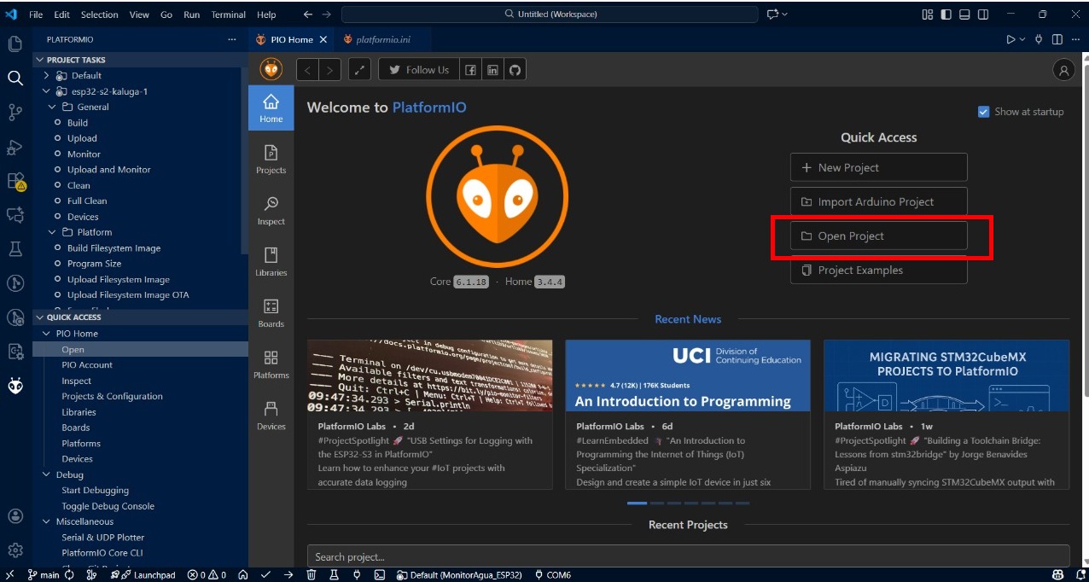
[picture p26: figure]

Con estos pasos completados, el entorno estará listo para construir, compilar y flashear el programa a la placa ESP32.

### 4.2 Configuración del Servidor

El servidor web se encarga de recibir, procesar y visualizar los datos enviados por la ESP32.

#### Paso 1: Abrir el proyecto del servidor

1. Abra Visual Studio Code
2. Seleccione "File" > "Open Folder"
3. Navegue hasta la carpeta del servidor del proyecto
4. Seleccione la carpeta y haga clic en "Abrir"

#### Paso 2: Instalar dependencias

El servidor requiere ciertas librerías para funcionar correctamente. A continuación, se listan las librerías mínimas necesarias:

Librerías requeridas:

- Express (servidor web)
- CORS (gestión de políticas de origen cruzado)
- Body-parser (procesamiento de datos JSON)
- Serialport (comunicación con la ESP32, si aplica)

Para instalar las dependencias, abra la terminal integrada en VSCode (Ctrl+Ñ o Terminal > New Terminal) y ejecute:

npm install

Este comando instalará automáticamente todas las dependencias listadas en el archivo package.json del proyecto.

#### Paso 3: Verificar la configuración

Revise el archivo de configuración del servidor (generalmente config.js o .env) para asegurarse de que los parámetros estén correctos:

- Puerto del servidor (por defecto: 3000)
- Rutas de almacenamiento de datos
- Configuración de CORS

## 5. PREPARACIÓN DEL HARDWARE

### 5.1 Instalación de Drivers

Para que su computador pueda comunicarse correctamente con la placa ESP32, es necesario instalar los drivers apropiados.

#### ¿Qué son los drivers y por qué son necesarios?

Los drivers son programas que permiten al sistema operativo reconocer y comunicarse con dispositivos de hardware. En este caso, la ESP32 utiliza un chip CP210x para la comunicación USB, por lo que necesitamos instalar sus drivers.

#### Pasos para instalar los drivers CP210x

1. Acceda al siguiente enlace para descargar los drivers: https://www.silabs.com/developers/usb-to-uart-bridge-vcp-drivers
2. Seleccione la versión correspondiente a su sistema operativo:
  - Windows 10/11
  - macOS
  - Linux
3. Descargue el archivo de instalación
4. Ejecute el instalador descargado:
  - Windows: Haga doble clic en el archivo .exe y siga las instrucciones
  - macOS: Abra el archivo .dmg y siga las instrucciones. Puede que necesite autorizar la instalación en "Preferencias del Sistema" > "Seguridad y Privacidad"
  - Linux: Generalmente los drivers vienen incluidos en el kernel, pero puede consultar la documentación si tiene problemas

### 5.2 Conexión de la Placa

#### Consideraciones importantes sobre la conexión USB

La placa ESP32 utilizada en este proyecto cuenta con un puerto USB tipo C. Sin embargo, es importante tener en cuenta que:

⚠️ IMPORTANTE: No todos los pines del puerto USB tipo C están habilitados en esta placa. Esto significa que la conexión solo será detectada cuando el cable se inserte en una orientación específica. Si conecta la placa y su computador no la reconoce, intente voltear el conector USB tipo C.

#### Pasos para conectar la placa

1. Tome el cable USB tipo C
2. Conecte un extremo al puerto USB de su computador
3. Conecte el otro extremo al puerto USB tipo C de la ESP32
4. Observe los indicadores LED de la placa (si están disponibles) para verificar que recibe alimentación
5. Si el computador no reconoce la placa:
  - Desconecte el cable
  - Voltee el conector USB tipo C
  - Vuelva a conectar
6. Verifique que el dispositivo fue reconocido:
  - Windows: Abra el "Administrador de dispositivos" y busque en "Puertos (COM y LPT)". Debería aparecer un puerto COM con el nombre "Silicon Labs CP210x USB to UART Bridge"

#### Limitaciones de alimentación actual

⚠️ NOTA: Aunque la placa cuenta con pines destinados a la conexión de baterías y posee un módulo de carga integrado, en la versión actual este sistema de carga no se encuentra funcional. Esto significa que las baterías conectadas podrán alimentar la placa mientras tengan energía, pero no serán recargadas a través del circuito incorporado.

Por esta razón, incluso cuando se utilicen baterías externas, es necesario contar con una fuente de alimentación por cable USB tipo C para garantizar el funcionamiento continuo del sistema y evitar interrupciones cuando la batería se descargue completamente.

## 6. CONEXIÓN FÍSICA DE SENSORES

Esta sección explica cómo conectar físicamente los sensores a la placa ESP32. Es fundamental seguir estas instrucciones cuidadosamente para evitar daños en los componentes.

### 6.1 Distribución de Pines

La placa cuenta con cinco borneras de dos entradas cada una, ubicadas en uno de los laterales de la placa, proporcionando un total de diez puntos de conexión.

#### Identificación de las borneras

Las borneras están distribuidas de la siguiente manera, comenzando desde la entrada más cercana al puerto USB tipo C:

Bornera | Pin Superior | Pin Inferior | Descripción
1 | 5V | 3.3V | Alimentación positiva
2 | GPIO1 | GND | Sensor de pH y tierra
3 | GPIO17 | GND | Sensor de temperatura y tierra
4 | GPIO7 | GND | Sensor TDS y tierra
5 | GPIO5 | GND | Sensor de turbidez y tierra

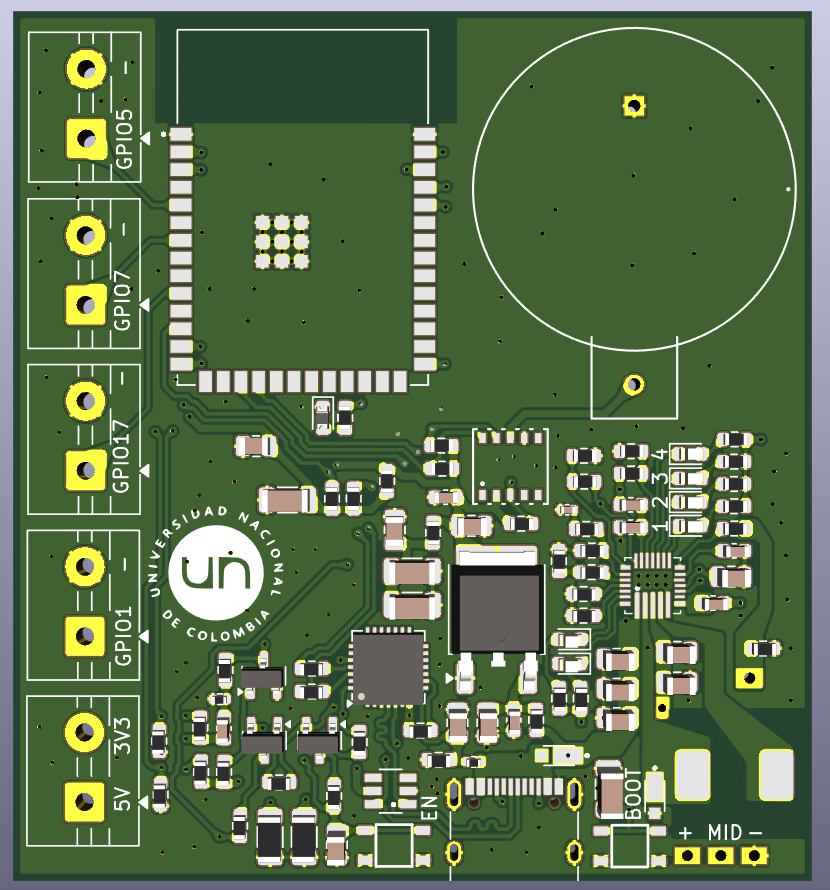
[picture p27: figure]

#### Asignación de sensores a pines GPIO

El software de la placa está configurado para leer los sensores en los siguientes pines:

- GPIO1: Salida analógica del sensor de pH
- GPIO17: Salida digital del sensor de temperatura DS18B20
- GPIO7: Salida analógica del sensor TDS
- GPIO5: Salida analógica del sensor de turbidez

### 6.2 Configuración del RTC (Reloj de Tiempo Real)

El módulo RTC es esencial para que el sistema registre correctamente la fecha y hora de cada medición.

#### ¿Qué es el RTC y por qué es importante?

El RTC (Real-Time Clock) es un circuito que mantiene la fecha y hora actualizadas, incluso cuando el dispositivo no tiene alimentación principal, gracias a una batería de respaldo. Esto permite que cada dato registrado tenga una estampa de tiempo precisa.

#### Verificación de la batería del RTC

⚠️ CRÍTICO: El RTC es alimentado por una batería tipo celda de reloj. Para su correcto funcionamiento, esta batería debe proporcionar 3.3V.

Pasos para verificar la batería:

1. Localice el módulo RTC en la placa (generalmente tiene una batería circular plateada)
2. Si tiene un multímetro, mida el voltaje de la batería:
  - Coloque la punta roja (+) en el terminal positivo de la batería
  - Coloque la punta negra (-) en el terminal negativo
  - Verifique que la lectura sea de aproximadamente 3.0V o superior
3. Si el voltaje es inferior a 2.8V, reemplace la batería

#### Consecuencias de una batería descargada

Si el RTC no funciona correctamente debido a una batería descargada:

- Los datos se seguirán registrando normalmente
- Sin embargo, NO tendrán la estampa de tiempo real correcta
- Al visualizar los datos en la interfaz web, se mostrarán con una estampa de tiempo relativa al momento en que fueron subidos, no al momento en que fueron tomados
- Los datos aparecerán en el orden correcto de captura, pero sin la fecha/hora real

### 6.3 Conexión de Sensores Individuales

A continuación, se detallan los pasos para conectar cada sensor. Importante: Realice estas conexiones con la placa desconectada de la alimentación.

#### Sensor de pH (GPIO1)

El sensor de pH mide la acidez o alcalinidad del agua en una escala de 0 a 14.

Conexiones:

1. Cable de alimentación del sensor → Bornera 1, pin 5V o 3.3V (consulte especificaciones del sensor)
2. Cable de señal (generalmente amarillo o blanco) → Bornera 2, pin GPIO1
3. Cable de tierra (generalmente negro) → Bornera 2, pin GND

Información adicional:

- Documentación del sensor: https://www.dfrobot.com/product-1782.html
- Antes del primer uso, el sensor requiere calibración según las instrucciones del fabricante

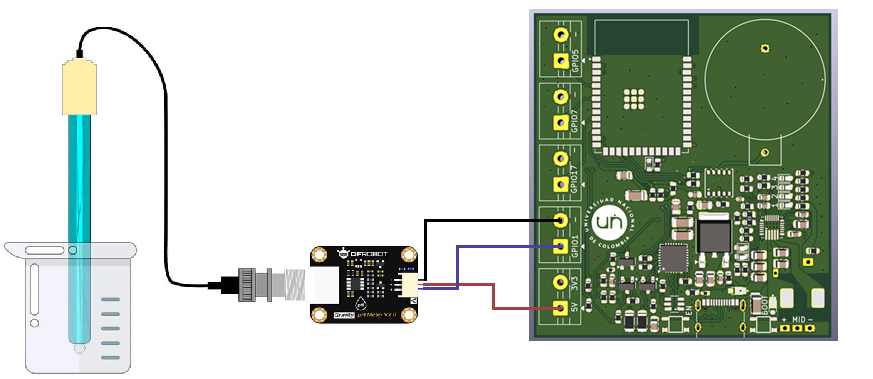
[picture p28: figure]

#### Sensor de Temperatura DS18B20 (GPIO17)

El sensor DS18B20 es un sensor digital que mide la temperatura del agua con alta precisión.

Conexiones:

1. Cable rojo (VCC) → Bornera 1, pin 3.3V o 5V
2. Cable amarillo o verde (DATA) → Bornera 3, pin GPIO17
3. Cable negro (GND) → Bornera 3, pin GND

Nota: Este sensor utiliza el protocolo OneWire y puede requerir una resistencia pull-up de 4.7kΩ entre la línea de datos y VCC (consulte si su sensor ya la incluye).

Información adicional:

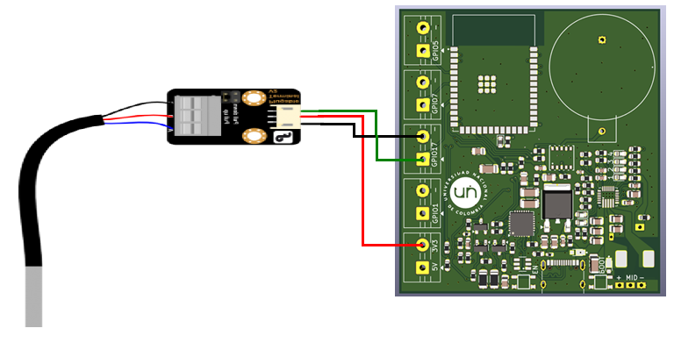
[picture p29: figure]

- Documentación del sensor: https://www.dfrobot.com/product-689.html

#### Sensor TDS (GPIO7)

El sensor TDS (Total Dissolved Solids) mide la concentración de partículas sólidas disueltas en el agua.

Conexiones:

1. Cable de alimentación (rojo) → Bornera 1, pin 5V
2. Cable de señal (generalmente azul o amarillo) → Bornera 4, pin GPIO7
3. Cable de tierra (negro) → Bornera 4, pin GND

Información adicional:

- Documentación del sensor: https://wiki.dfrobot.com/Gravity__Analog_TDS_Sensor___Meter_For_Arduino_SKU__SEN0244

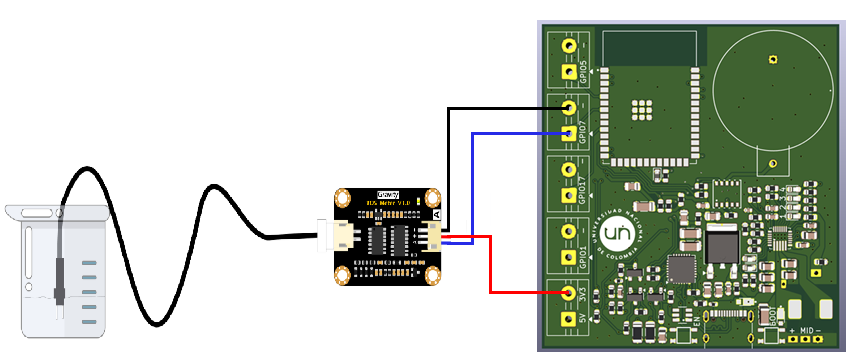
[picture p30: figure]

- El sensor puede requerir calibración con una solución estándar de TDS conocido

#### Sensor de Turbidez (GPIO5)

El sensor de turbidez mide la claridad del agua detectando la cantidad de partículas suspendidas.

Conexiones:

1. Cable de alimentación (rojo) → Bornera 1, pin 5V
2. Cable de señal (generalmente blanco o amarillo) → Bornera 5, pin GPIO5
3. Cable de tierra (negro) → Bornera 5, pin GND

Información adicional:

- Documentación del sensor: https://www.dfrobot.com/product-1394.html
- El sensor debe estar completamente sumergido para lecturas precisas

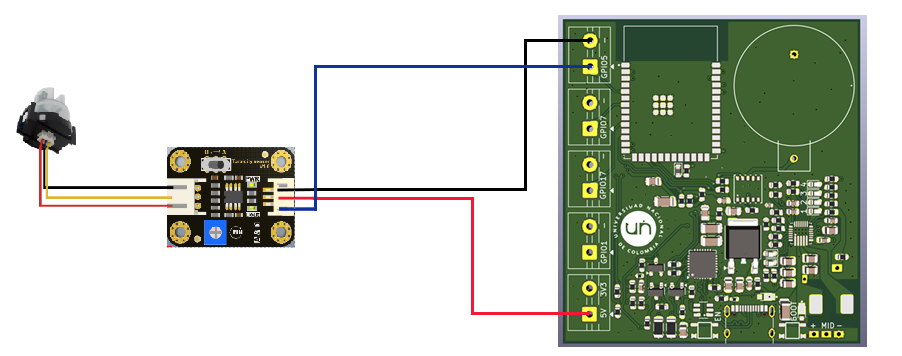
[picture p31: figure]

#### Verificación final de conexiones

Antes de energizar el sistema, verifique:

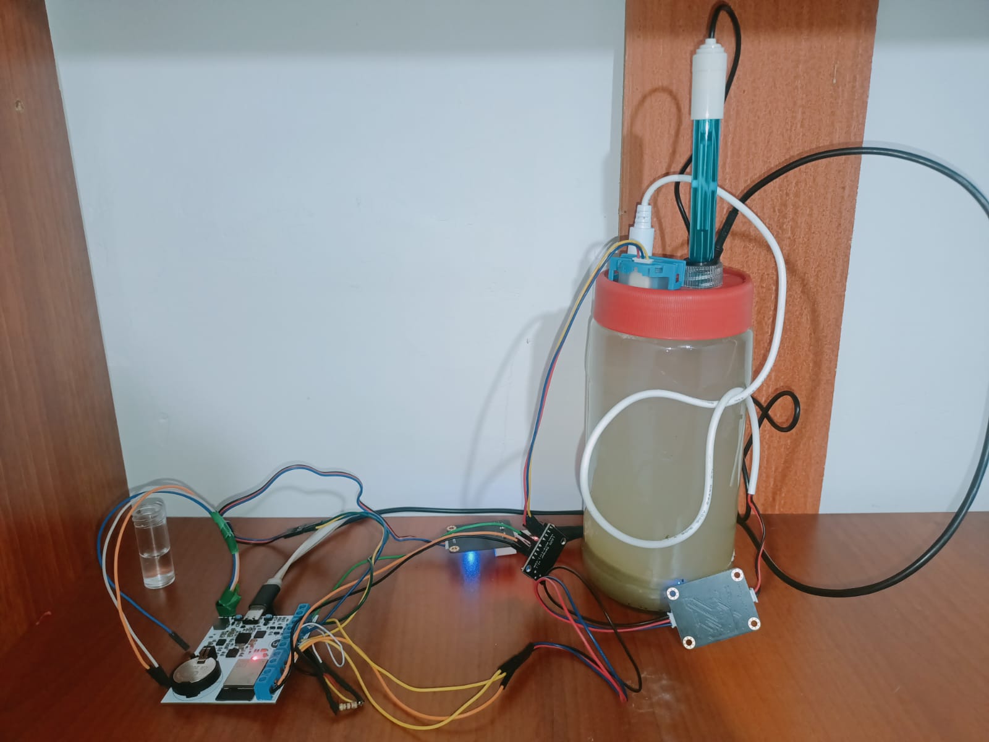
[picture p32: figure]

✓ Todas las conexiones de alimentación están correctas (5V y 3.3V según corresponda) ✓ No hay cables sueltos o mal conectados ✓ Los cables de señal están en los GPIOs correctos ✓ Todas las tierras (GND) están conectadas ✓ No hay cortocircuitos entre pines

## 7. CONFIGURACIÓN Y USO DEL SISTEMA

### 7.1 Flasheo del Programa

El "flasheo" es el proceso de cargar el programa en la memoria de la ESP32.

#### Pasos para flashear el programa

1. Asegúrese de que la placa está conectada al computador y fue reconocida
2. Abra el proyecto de la ESP32 en Visual Studio Code con PlatformIO
3. En la barra inferior de VSCode, localice los botones de PlatformIO:
  - ✓ (Build): Compila el código
  - → (Upload): Compila y sube el código a la placa
  - 🔌 (Serial Monitor): Abre el monitor serial
4. Haga clic en el botón "Upload" (→)
5. Observe la salida en la terminal. Verá mensajes indicando:
  - Compilación del código
  - Conexión con la placa
  - Subida del programa
  - Verificación

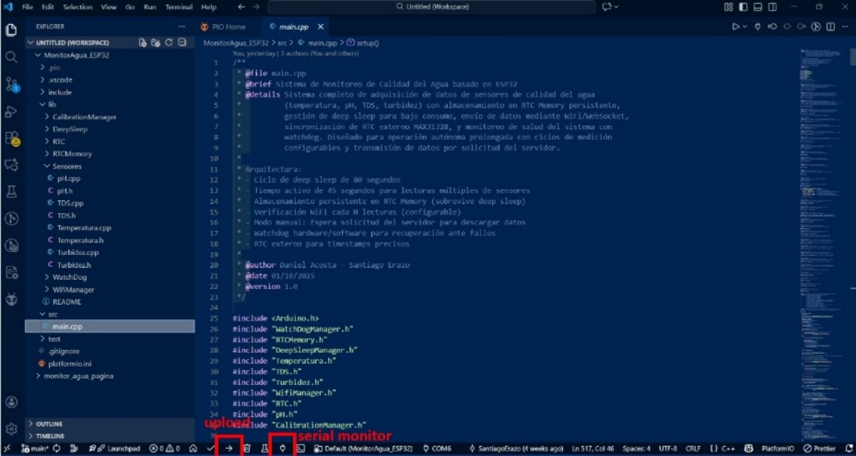
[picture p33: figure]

6. Si el proceso es exitoso, verá un mensaje como "SUCCESS" o "Uploading complete"

#### Solución de problemas durante el flasheo

Error: "No se puede conectar a la placa"

- Verifique que los drivers estén instalados correctamente
- Intente voltear el conector USB tipo C
- Cierre otros programas que puedan estar usando el puerto serial

Error: "Timeout esperando respuesta"

- Mantenga presionado el botón BOOT en la placa mientras inicia el flasheo
- Intente con un cable USB diferente

### 7.2 Configuración de Red WiFi

Para que la ESP32 pueda enviar datos al servidor, debe conectarse a una red WiFi.

#### Configuración de la red en el computador

El sistema está configurado por defecto para conectarse a una red con las siguientes credenciales:

- Nombre de red (SSID): RED_MONITOREO
- Contraseña: Holamundo6

Pasos para configurar un hotspot en Windows:

1. Abra "Configuración" > "Red e Internet" > "Zona con cobertura inalámbrica móvil"
2. Active "Compartir mi conexión a Internet con otros dispositivos"
3. Haga clic en "Editar" y configure:
  - Nombre de red: RED_MONITOREO
  - Contraseña de red: Holamundo6
4. Guarde los cambios y active el hotspot

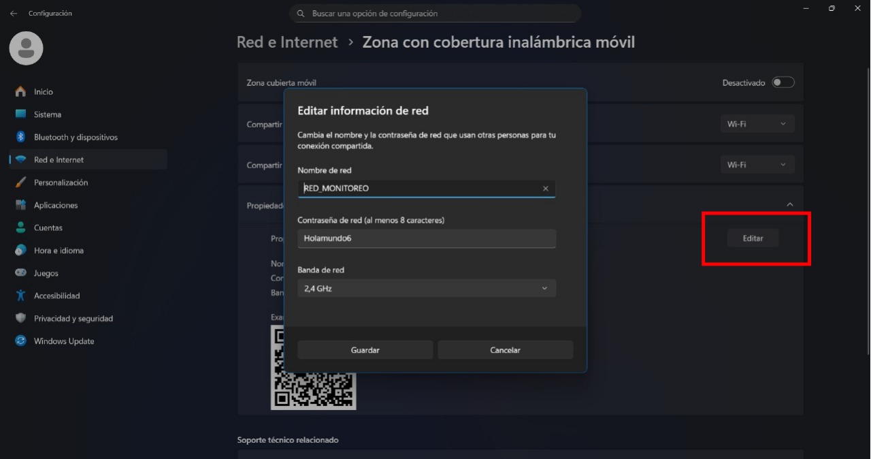
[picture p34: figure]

Pasos para configurar un hotspot en macOS:

1. Vaya a "Preferencias del Sistema" > "Compartir"
2. Seleccione "Compartir Internet" en la lista de la izquierda
3. Configure:
  - Compartir conexión desde: Ethernet o su conexión principal
  - Para ordenadores que usen: Wi-Fi
4. Haga clic en "Opciones de Wi-Fi" y configure:
  - Nombre de red: RED_MONITOREO
  - Seguridad: WPA2 Personal
  - Contraseña: Holamundo6
5. Active la casilla "Compartir Internet"

#### Modificación de credenciales WiFi (Avanzado)

Si desea usar una red WiFi diferente, puede modificar las credenciales en el código:

1. Abra el archivo principal del código de la ESP32 (generalmente main.cpp)
2. Localice las líneas que definen el SSID y la contraseña:
  const char* ssid = "RED_MONITOREO"; const char* password = "Holamundo6";
3. Modifique los valores entre comillas con sus propias credenciales
4. Guarde el archivo y vuelva a flashear el programa

#### Comportamiento del sistema sin conexión a internet

⚠️ IMPORTANTE: Aunque la placa no tenga acceso a internet:

- El sistema continuará tomando mediciones normalmente
- Los datos se almacenarán en la memoria local de la ESP32
- NO será posible visualizar los datos en tiempo real
- Los datos podrán ser consultados una vez se restablezca la conexión

### 7.3 Monitoreo Serial

El monitor serial permite ver mensajes de depuración y estado del sistema en tiempo real.

#### Abrir el monitor serial

1. Con la placa conectada y el programa ya flasheado, haga clic en el botón "Serial Monitor" (🔌) en la barra inferior de PlatformIO
2. Seleccione la velocidad de baudios correcta (generalmente 115200)
3. Observe los mensajes que la ESP32 envía:
  - Estado de inicialización
  - Lecturas de sensores
  - Intentos de conexión WiFi
  - Errores o advertencias

[Espacio para imagen: Monitor serial mostrando mensajes del sistema]

#### Interpretación de mensajes comunes

- "Connecting to WiFi...": La placa está intentando conectarse a la red
- "WiFi connected": Conexión exitosa a la red
- "IP address: X.X.X.X": Dirección IP asignada a la ESP32
- "Reading sensors...": El sistema está tomando mediciones
- "Data saved locally": Los datos fueron guardados en memoria

## 8. COMUNICACIÓN ENTRE MÓDULOS

### 8.1 Proceso de Adquisición de Datos

El sistema opera en ciclos de medición. Cada ciclo consiste en:

1. Despertar del modo de bajo consumo (si está habilitado)
2. Leer todos los sensores (pH, temperatura, TDS, turbidez)
3. Registrar fecha y hora desde el RTC
4. Almacenar los datos localmente en la memoria de la ESP32
5. Verificar si es momento de conectarse a internet
6. Volver a modo de bajo consumo (si está configurado)

#### Frecuencia de medición

El sistema está configurado para tomar mediciones cada cierto intervalo de tiempo (configurable en el código). Por defecto, puede ser cada 5, 10 o 15 minutos, dependiendo de la configuración específica del proyecto.

#### Frecuencia de conexión a internet

Para ahorrar energía, el sistema no se conecta a internet en cada medición. En su lugar, después de un número determinado de ciclos de medición (por ejemplo, cada 10 o 20 mediciones), la placa:

1. Intenta conectarse a la red WiFi configurada
2. Si la conexión es exitosa, espera solicitudes del servidor
3. Permanece en línea durante un tiempo determinado
4. Vuelve a modo autónomo si no hay actividad

### 8.2 Visualización de Datos en la Interfaz Web

Una vez que la ESP32 está conectada a internet, los datos pueden ser consultados a través de la interfaz web.

#### Iniciar el servidor web

1. Abra el proyecto del servidor en Visual Studio Code
2. Abra una terminal integrada
3. Ejecute el comando:
  npm start
  o el comando específico configurado en el proyecto
4. Espere el mensaje "Server running on port 3000" o similar
5. Abra su navegador web y acceda a:
  http://localhost:3000

[Espacio para imagen: Interfaz web del sistema]

#### Solicitar datos desde la interfaz

6. En la interfaz web, localice el botón "Solicitar Datos" o "Descargar Datos"
7. Este botón solo estará habilitado cuando la ESP32 esté conectada a internet
8. Haga clic en el botón
9. La página enviará una solicitud a la ESP32
10. La ESP32 responderá enviando los datos almacenados
11. Los datos aparecerán en la interfaz en forma de tabla o gráficos

#### Limitaciones de visualización

⚠️ IMPORTANTE: Por defecto, la interfaz web solo mostrará los 120 datos más recientes. Esta cantidad puede ser modificada en el código del servidor si se requiere visualizar más o menos datos.

Si tiene más de 120 mediciones almacenadas, solo verá las más recientes. Los datos más antiguos permanecen en la memoria de la ESP32 hasta que sean sobrescritos por nuevas mediciones.

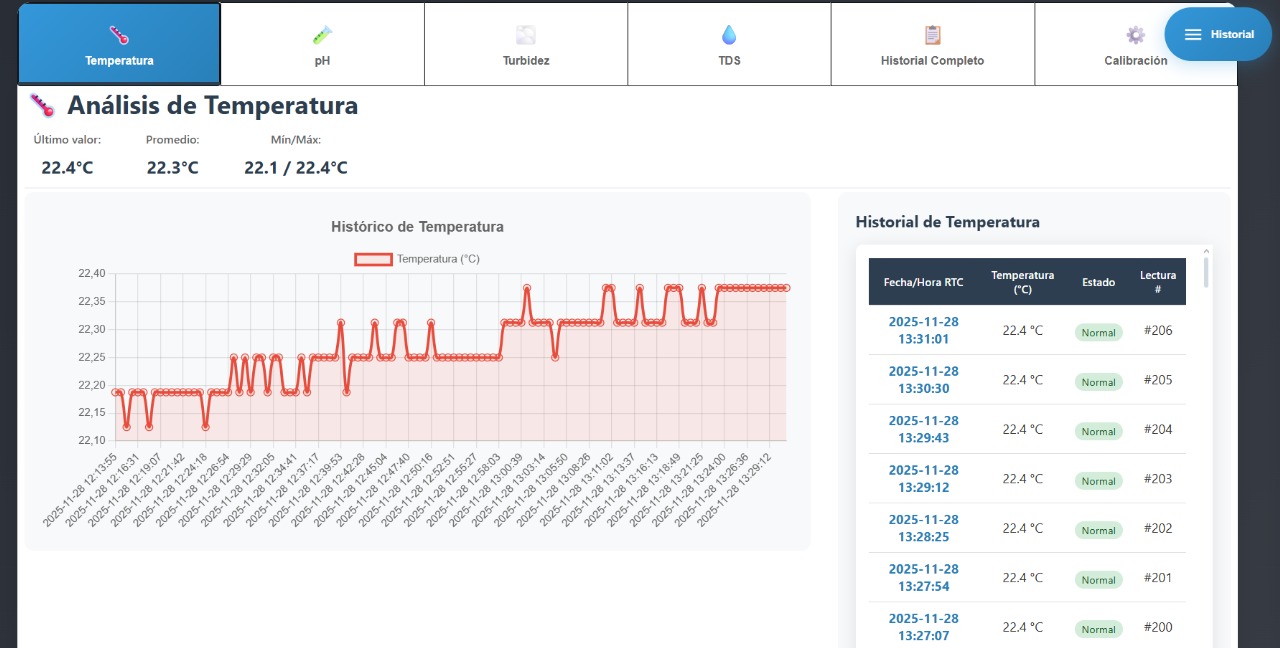
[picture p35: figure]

#### Interpretación de los datos mostrados

La interfaz web mostrará para cada medición:

- Fecha y hora: Estampa de tiempo de la medición
- pH: Valor entre 0-14 (7 es neutro, <7 ácido, >7 alcalino)
- Temperatura: Valor en grados Celsius
- TDS: Concentración de sólidos disueltos (generalmente en ppm)
- Turbidez: Nivel de claridad del agua (valores más bajos = agua más clara)

## 9. SOLUCIÓN DE PROBLEMAS COMUNES

### La placa no es reconocida por el computador

Síntomas:

- No aparece puerto COM en el administrador de dispositivos
- PlatformIO no encuentra la placa

Soluciones:

1. Verifique que los drivers CP210x están instalados
2. Intente voltear el conector USB tipo C
3. Pruebe con un cable USB diferente (algunos cables solo sirven para carga)
4. Reinicie el computador
5. Pruebe en un puerto USB diferente

### Error al flashear el programa

Síntomas:

- Mensaje "Timeout" durante el upload
- "Failed to connect to ESP32"

Soluciones:

1. Presione y mantenga el botón BOOT durante el inicio del flasheo
2. Cierre el monitor serial si está abierto
3. Desconecte y vuelva a conectar la placa
4. Verifique que no hay otros programas usando el puerto serial (Arduino IDE, etc.)

### La placa no se conecta al WiFi

Síntomas:

- Monitor serial muestra "Connecting..." repetidamente
- Nunca muestra "WiFi connected"

Soluciones:

1. Verifique que el hotspot está activo y con el SSID correcto
2. Asegúrese de que el nombre de red es exactamente "RED_MONITOREO" (distingue mayúsculas)
3. Confirme que la contraseña es "Holamundo6"
4. Acerque la ESP32 al punto de acceso WiFi
5. Revise que el hotspot usa WPA2 Personal (no WPA3)

### Los datos no tienen estampa de tiempo correcta

Síntomas:

- Las fechas mostradas no corresponden a cuándo se tomaron las mediciones
- Todas las mediciones muestran la misma fecha/hora

Soluciones:

1. Verifique el voltaje de la batería del RTC (debe ser > 3.0V)
2. Reemplace la batería del RTC si es necesario
3. Después de reemplazar la batería, la ESP32 debe conectarse a internet al menos una vez para sincronizar el RTC

### Lecturas de sensores incorrectas o erráticas

Síntomas:

- Valores fuera de rango esperado
- Lecturas que cambian drásticamente sin razón

Soluciones:

1. Verifique que las conexiones de los sensores están firmes y correctas
2. Confirme que está usando el voltaje de alimentación correcto para cada sensor
3. Revise que no hay cortocircuitos entre cables
4. Algunos sensores requieren calibración - consulte la documentación del fabricante
5. Asegúrese de que los sensores están completamente sumergidos en el agua (si aplica)

### No aparece el botón para descargar datos en la interfaz web

Síntomas:

- La interfaz web carga, pero el botón está deshabilitado o no aparece
- No hay comunicación con la ESP32

Soluciones:

1. Verifique que la ESP32 está conectada a internet (revise el monitor serial)
2. Asegúrese de que el servidor está ejecutándose
3. Confirme que la ESP32 y el computador están en la misma red
4. Revise la consola del navegador (F12) para ver errores de comunicación
5. Espere a que la ESP32 complete su ciclo de conexión (puede tomar algunos minutos)

### El sistema se reinicia constantemente

Síntomas:

- La placa se apaga y enciende repetidamente
- Monitor serial muestra reinicios frecuentes

Soluciones:

1. Verifique que la fuente de alimentación proporciona suficiente corriente (mínimo 500mA)
2. Revise que no hay cortocircuitos en las conexiones
3. Desconecte todos los sensores temporalmente para verificar si el problema es de la placa o de los sensores
4. Revise que el cable USB está en buen estado

## 10. REFERENCIAS Y RECURSOS ADICIONALES

### Documentación de sensores

- Sensor de pH: https://www.dfrobot.com/product-1782.html
- Sensor de Temperatura DS18B20: https://www.dfrobot.com/product-689.html
- Sensor TDS: https://wiki.dfrobot.com/Gravity__Analog_TDS_Sensor___Meter_For_Arduino_SKU__SEN0244
- Sensor de Turbidez: https://www.dfrobot.com/product-1394.html

### Drivers y software

- Drivers CP210x USB to UART Bridge: https://www.silabs.com/developers/usb-to-uart-bridge-vcp-drivers
- Visual Studio Code: https://code.visualstudio.com/
- PlatformIO: https://platformio.org/

### Repositorio del proyecto

- GitHub: https://github.com/dacostaca/WaterQualityMonitoring

### Documentación técnica

Para información más detallada sobre el código, arquitectura del sistema y configuraciones avanzadas, consulte:

- El archivo README.md en el repositorio del proyecto
- Los comentarios en el código fuente
- La carpeta de documentación técnica (si existe)

## APÉNDICE A: Especificaciones Técnicas

### Características de la ESP32

- Microcontrolador: Tensilica Xtensa 32-bit LX6
- Frecuencia de reloj: 240 MHz
- Memoria Flash: 4 MB
- RAM: 520 KB
- WiFi: 802.11 b/g/n
- Bluetooth: v4.2 BR/EDR y BLE
- Pines GPIO: 34 (uso configurable)
- ADC: 18 canales de 12 bits
- Voltaje de operación: 3.3V
- Voltaje de entrada USB: 5V

### Rangos de medición de sensores

- pH: 0-14
- Temperatura: -55°C a 125°C (DS18B20)
- TDS: 0-1000 ppm (típico)
- Turbidez: 0-1000 NTU (depende del modelo)

### Consumo de energía estimado

- Operación activa: ~200-300 mA
- Modo Deep Sleep: ~10-15 µA
- Promedio con ciclos de medición: Depende de configuración

## APÉNDICE B: Glosario de Términos

ADC (Analog-to-Digital Converter): Conversor analógico-digital que transforma señales analógicas en valores digitales.

Baudios: Velocidad de transmisión de datos en comunicación serial, medida en bits por segundo.

Deep Sleep: Modo de bajo consumo de energía donde el microcontrolador reduce drásticamente su actividad.

Flashear: Proceso de cargar un programa en la memoria flash de un microcontrolador.

GPIO (General Purpose Input/Output): Pines de propósito general que pueden configurarse como entrada o salida.

NTU (Nephelometric Turbidity Units): Unidades de medición de turbidez.

OneWire: Protocolo de comunicación que permite múltiples dispositivos en un solo cable.

pH: Medida de acidez o alcalinidad en una escala de 0 a 14.

ppm (parts per million): Partes por millón, unidad de concentración.

RTC (Real-Time Clock): Reloj de tiempo real que mantiene fecha y hora precisas.

SSID: Nombre identificador de una red WiFi.

TDS (Total Dissolved Solids): Sólidos totales disueltos en el agua.

UART (Universal Asynchronous Receiver-Transmitter): Protocolo de comunicación serial.

VCP (Virtual COM Port): Puerto COM virtual creado por drivers USB.

## HISTORIAL DE REVISIONES

Versión | Fecha | Autor | Descripción de Cambios
1.0 | 2025 | [Autores] | Versión inicial del manual

## NOTAS FINALES

Este manual está diseñado para facilitar la implementación y uso del Sistema de Monitoreo de Calidad del Agua. Se recomienda leerlo completamente antes de comenzar con el ensamblaje y configuración del sistema.

Para obtener la mejor experiencia:

- Siga los pasos en el orden presentado
- No omita las verificaciones de seguridad
- Consulte las referencias cuando tenga dudas
- Documente cualquier modificación que realice al sistema

¡Gracias por utilizar este sistema de monitoreo!

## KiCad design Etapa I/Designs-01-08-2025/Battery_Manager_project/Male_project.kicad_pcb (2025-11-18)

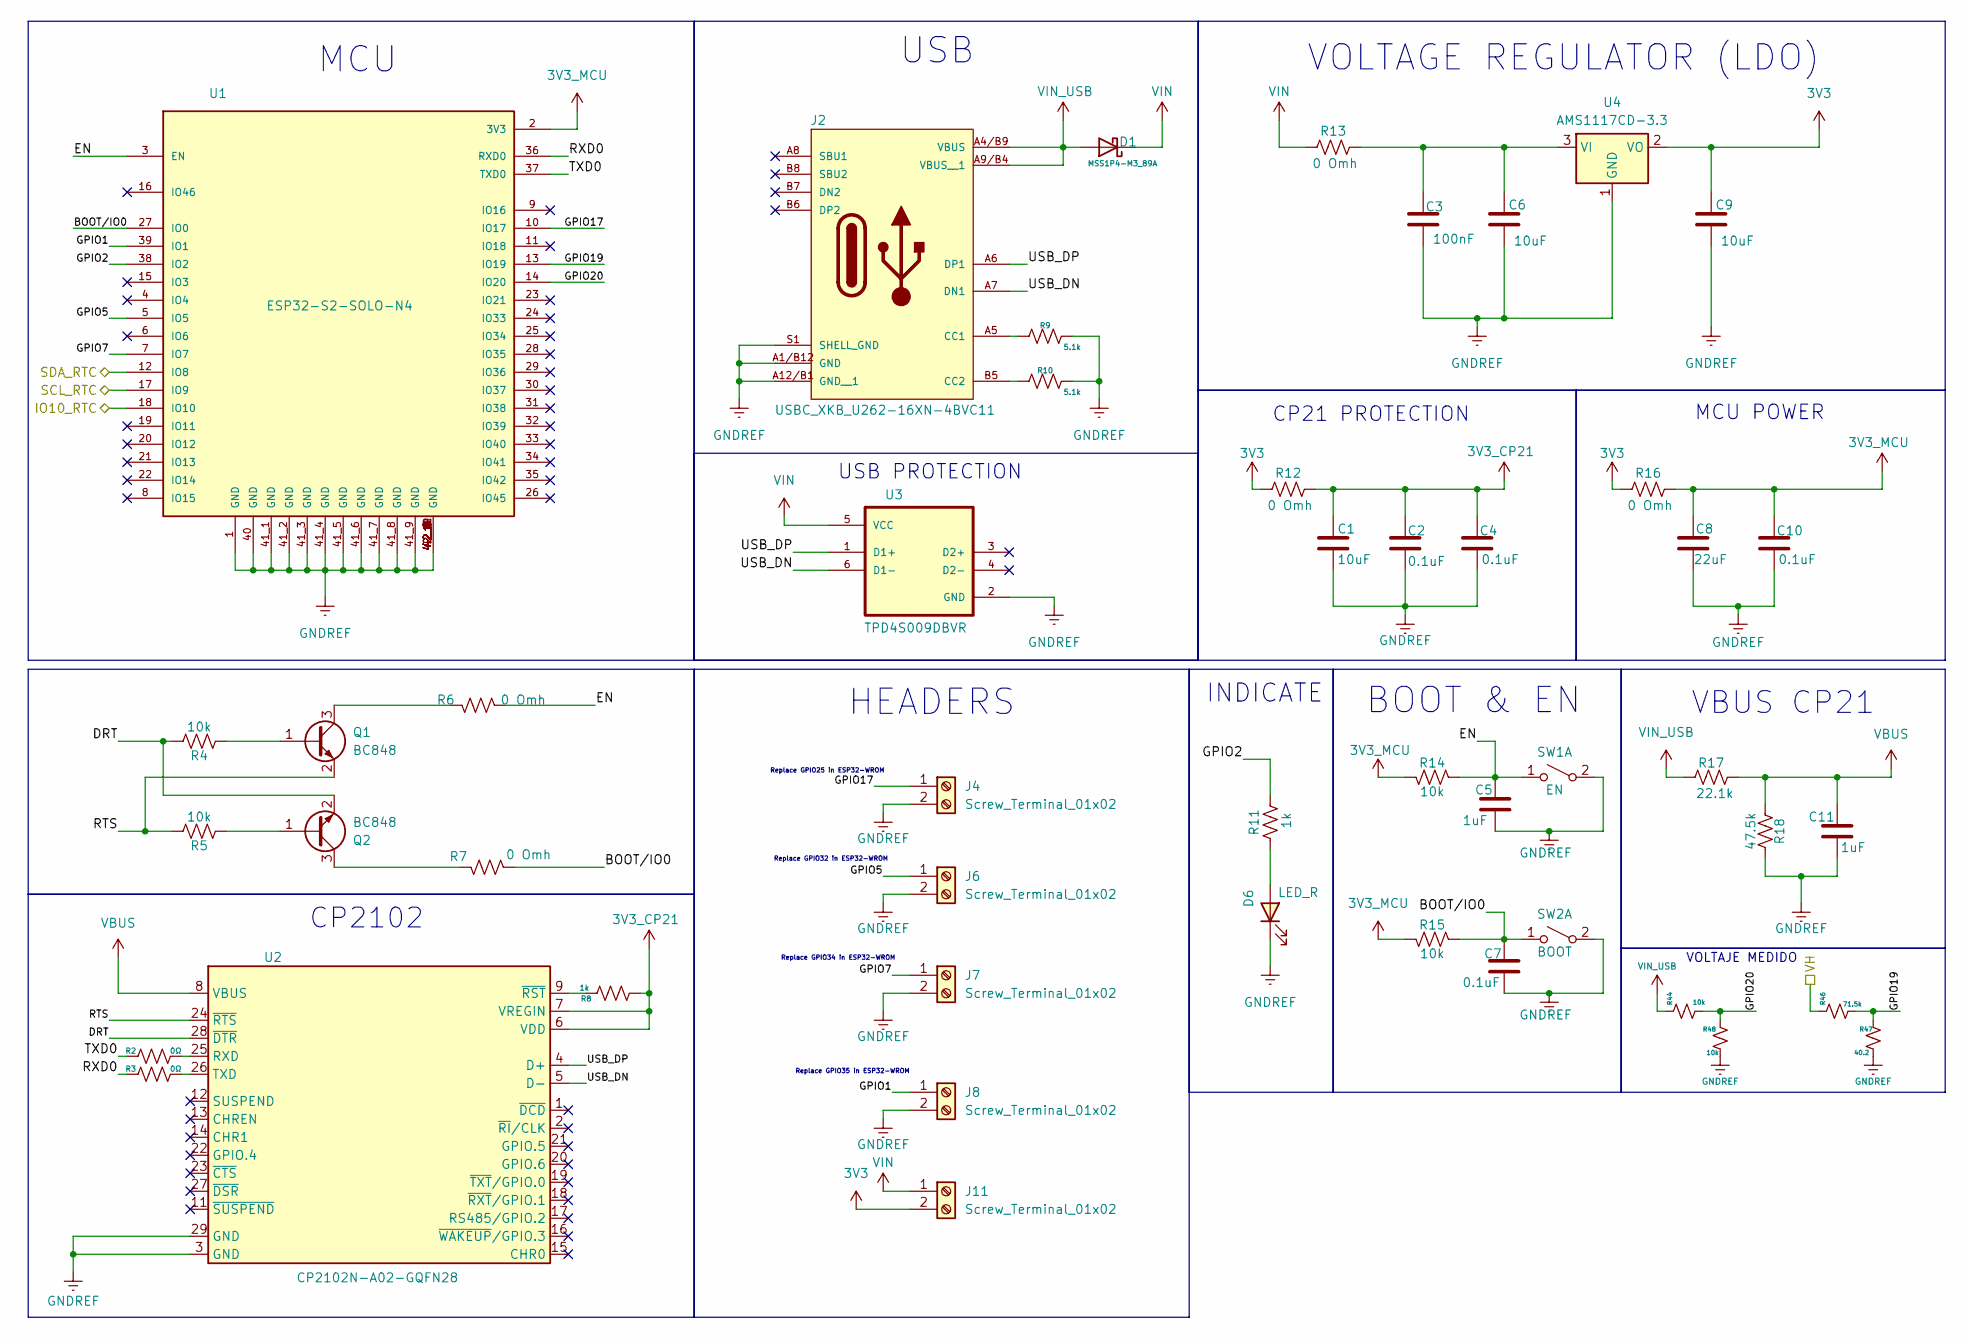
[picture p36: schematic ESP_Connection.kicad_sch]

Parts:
C1, C6, C9: 10uF; C_0805_2012Metric
C2, C4, C7, C10: 0.1uF; C_1206_3216Metric
C3: 100nF; C_0603_1608Metric; Mnf. Part # CC0603KRX7R7BB104
C5, C11: 1uF; C_0805_2012Metric; Manufacturer # CC0805KKX7R7BB105
C8: 22uF; C_0805_2012Metric
D1: MSS1P4-M3_89A; DIODE_MSS1P4-M3_89A
D6: LED_R; D_0603_1608Metric; Manufacturer # TLMS1100-GS08
J2: USBC_XKB_U262-16XN-4BVC11; USBC_Receptacle_XKB_U262-16XN-4BVC11; PARTREV B4
J4, J6, J7, J8, J11: Screw_Terminal_01x02; TerminalBlock_MaiXu_MX126-5.0-02P_1x02_P5.00mm
Q1, Q2: BC848; SOT-23
R2, R3: 0Ω; R_0603_1608Metric
R4, R5, R14, R15: 10k; R_0603_1608Metric; Manufacturer # CR0603-FX-1002ELF
R6, R7, R12, R13, R16: 0 Omh; R_0603_1608Metric
R8, R11: 1k; R_0603_1608Metric
R9, R10: 5.1k; R_1206_3216Metric
R17: 22.1k; R_0402_1005Metric
R18: 47.5k; R_0603_1608Metric; Manufacturer # CR0603-FX-1002ELF
R44, R48: 10k; R_0603_1608Metric
R46: 71.5k; R_0603_1608Metric
R47: 40.2; R_0603_1608Metric
SW1: EN; PTS810SJG250SMTR LFS; Manufacturer # PTS810SJG250SMTR LFS
SW2: BOOT; PTS810SJG250SMTR LFS; Manufacturer # PTS810SJG250SMTR LFS
U1: ESP32-S2-SOLO-N4; XCVR_ESP32-S2-SOLO-N4; PARTREV 1.6
U2: CP2102N-A02-GQFN28; QFN-28-1EP_5x5mm_P0.5mm_EP3.35x3.35mm
U3: TPD4S009DBVR; SOT95P280X145-6N
U4: AMS1117CD-3.3; TO-252-2

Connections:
3V3: C9.1, J11.2, R12.1, R16.1, U4.2 (VO); also elsewhere on the board
3V3_CP21: C1.1, C2.1, C4.1, R8.1, R12.2, U2.6 (VDD), U2.7 (VREGIN)
3V3_MCU: C8.1, C10.1, R14.2, R15.2, R16.2, U1.2 (3V3)
/Battery_Manager/IO10_RTC: U1.18 (IO10); also elsewhere on the board
/Battery_Manager/SCL_RTC: U1.17 (IO9); also elsewhere on the board
/Battery_Manager/SDA_RTC: U1.12 (IO8); also elsewhere on the board
/Battery_Manager/VH: R46.1; also elsewhere on the board
/MCU/BOOT/IO0: C7.1, R7.1, R15.1, SW2.1 (B), U1.27 (IO0)
/MCU/DRT: Q2.2 (E), R4.2, U2.28 (~DTR)
/MCU/EN: C5.1, R6.1, R14.1, SW1.1 (B), U1.3 (EN)
/MCU/GPIO1: J8.1, U1.39 (IO1)
/MCU/GPIO2: R11.2, U1.38 (IO2)
/MCU/GPIO5: J6.1, U1.5 (IO5)
/MCU/GPIO7: J7.1, U1.7 (IO7)
/MCU/GPIO17: J4.1, U1.10 (IO17)
/MCU/GPIO19: R46.2, R47.1, U1.13 (IO19)
/MCU/GPIO20: R44.2, R48.1, U1.14 (IO20)
/MCU/RTS: Q1.2 (E), R5.2, U2.24 (~RTS)
/MCU/RXD0: R3.1, U1.36 (RXD0)
/MCU/TXD0: R2.1, U1.37 (TXD0)
/MCU/USB_DN: J2.A7 (DN1), U2.5 (D-), U3.6 (D1-)
/MCU/USB_DP: J2.A6 (DP1), U2.4 (D+), U3.1 (D1+)
GNDREF: C1.2, C2.2, C3.2, C4.2, C5.2, C6.2, C7.2, C8.2, C9.2, C10.2, C11.2, D6.1 (K), J2.A1/B12 (GND), J2.A12/B1 (GND__1), J2.S1 (SHELL_GND), J4.2, J6.2, J7.2, J8.2, R9.2, R10.2, R18.2, R47.2, R48.2, SW1.2 (A), SW2.2 (A), U1.1 (GND), U1.40 (GND), U1.41_1 (GND), U1.41_2 (GND), U1.41_3 (GND), U1.41_4 (GND), U1.41_5 (GND), U1.41_6 (GND), U1.41_7 (GND), U1.41_8 (GND), U1.41_9 (GND), U1.42_1 (GND), U1.42_2 (GND), U1.42_3 (GND), U1.42_4 (GND), U1.42_5 (GND), U1.42_6 (GND), U1.42_7 (GND), U1.42_8 (GND), U1.42_9 (GND), U1.42_10 (GND), U1.42_11 (GND), U1.42_12 (GND), U2.3 (GND), U2.29 (GND), U3.2 (GND), U4.1 (GND); also elsewhere on the board
unnamed: D6.2 (A), R11.1
unnamed: J2.A5 (CC1), R9.1
unnamed: J2.B5 (CC2), R10.1
unnamed: Q1.1 (B), R4.1
unnamed: Q1.3 (C), R6.2
unnamed: Q2.1 (B), R5.1
unnamed: Q2.3 (C), R7.2
unnamed: R2.2, U2.25 (RXD)
unnamed: R3.2, U2.26 (TXD)
unnamed: R8.2, U2.9 (~RST)
unnamed: C3.1, C6.1, R13.2, U4.3 (VI)
VBUS: C11.1, R17.2, R18.1, U2.8 (VBUS)
VIN: D1.1 (K), J11.1, R13.1, U3.5 (VCC); also elsewhere on the board
VIN_USB: D1.2 (A), J2.A4/B9 (VBUS), J2.A9/B4 (VBUS__1), R17.1, R44.1; also elsewhere on the board

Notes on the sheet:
Replace GPIO35 in ESP32-WROM
USB
VOLTAJE MEDIDO
HEADERS
VBUS CP21
INDICATE
MCU
Replace GPIO34 in ESP32-WROM
Replace GPIO25 in ESP32-WROM
USB PROTECTION
Replace GPIO32 in ESP32-WROM
MCU POWER
CP21 PROTECTION
BOOT & EN
VOLTAGE REGULATOR (LDO)
CP2102

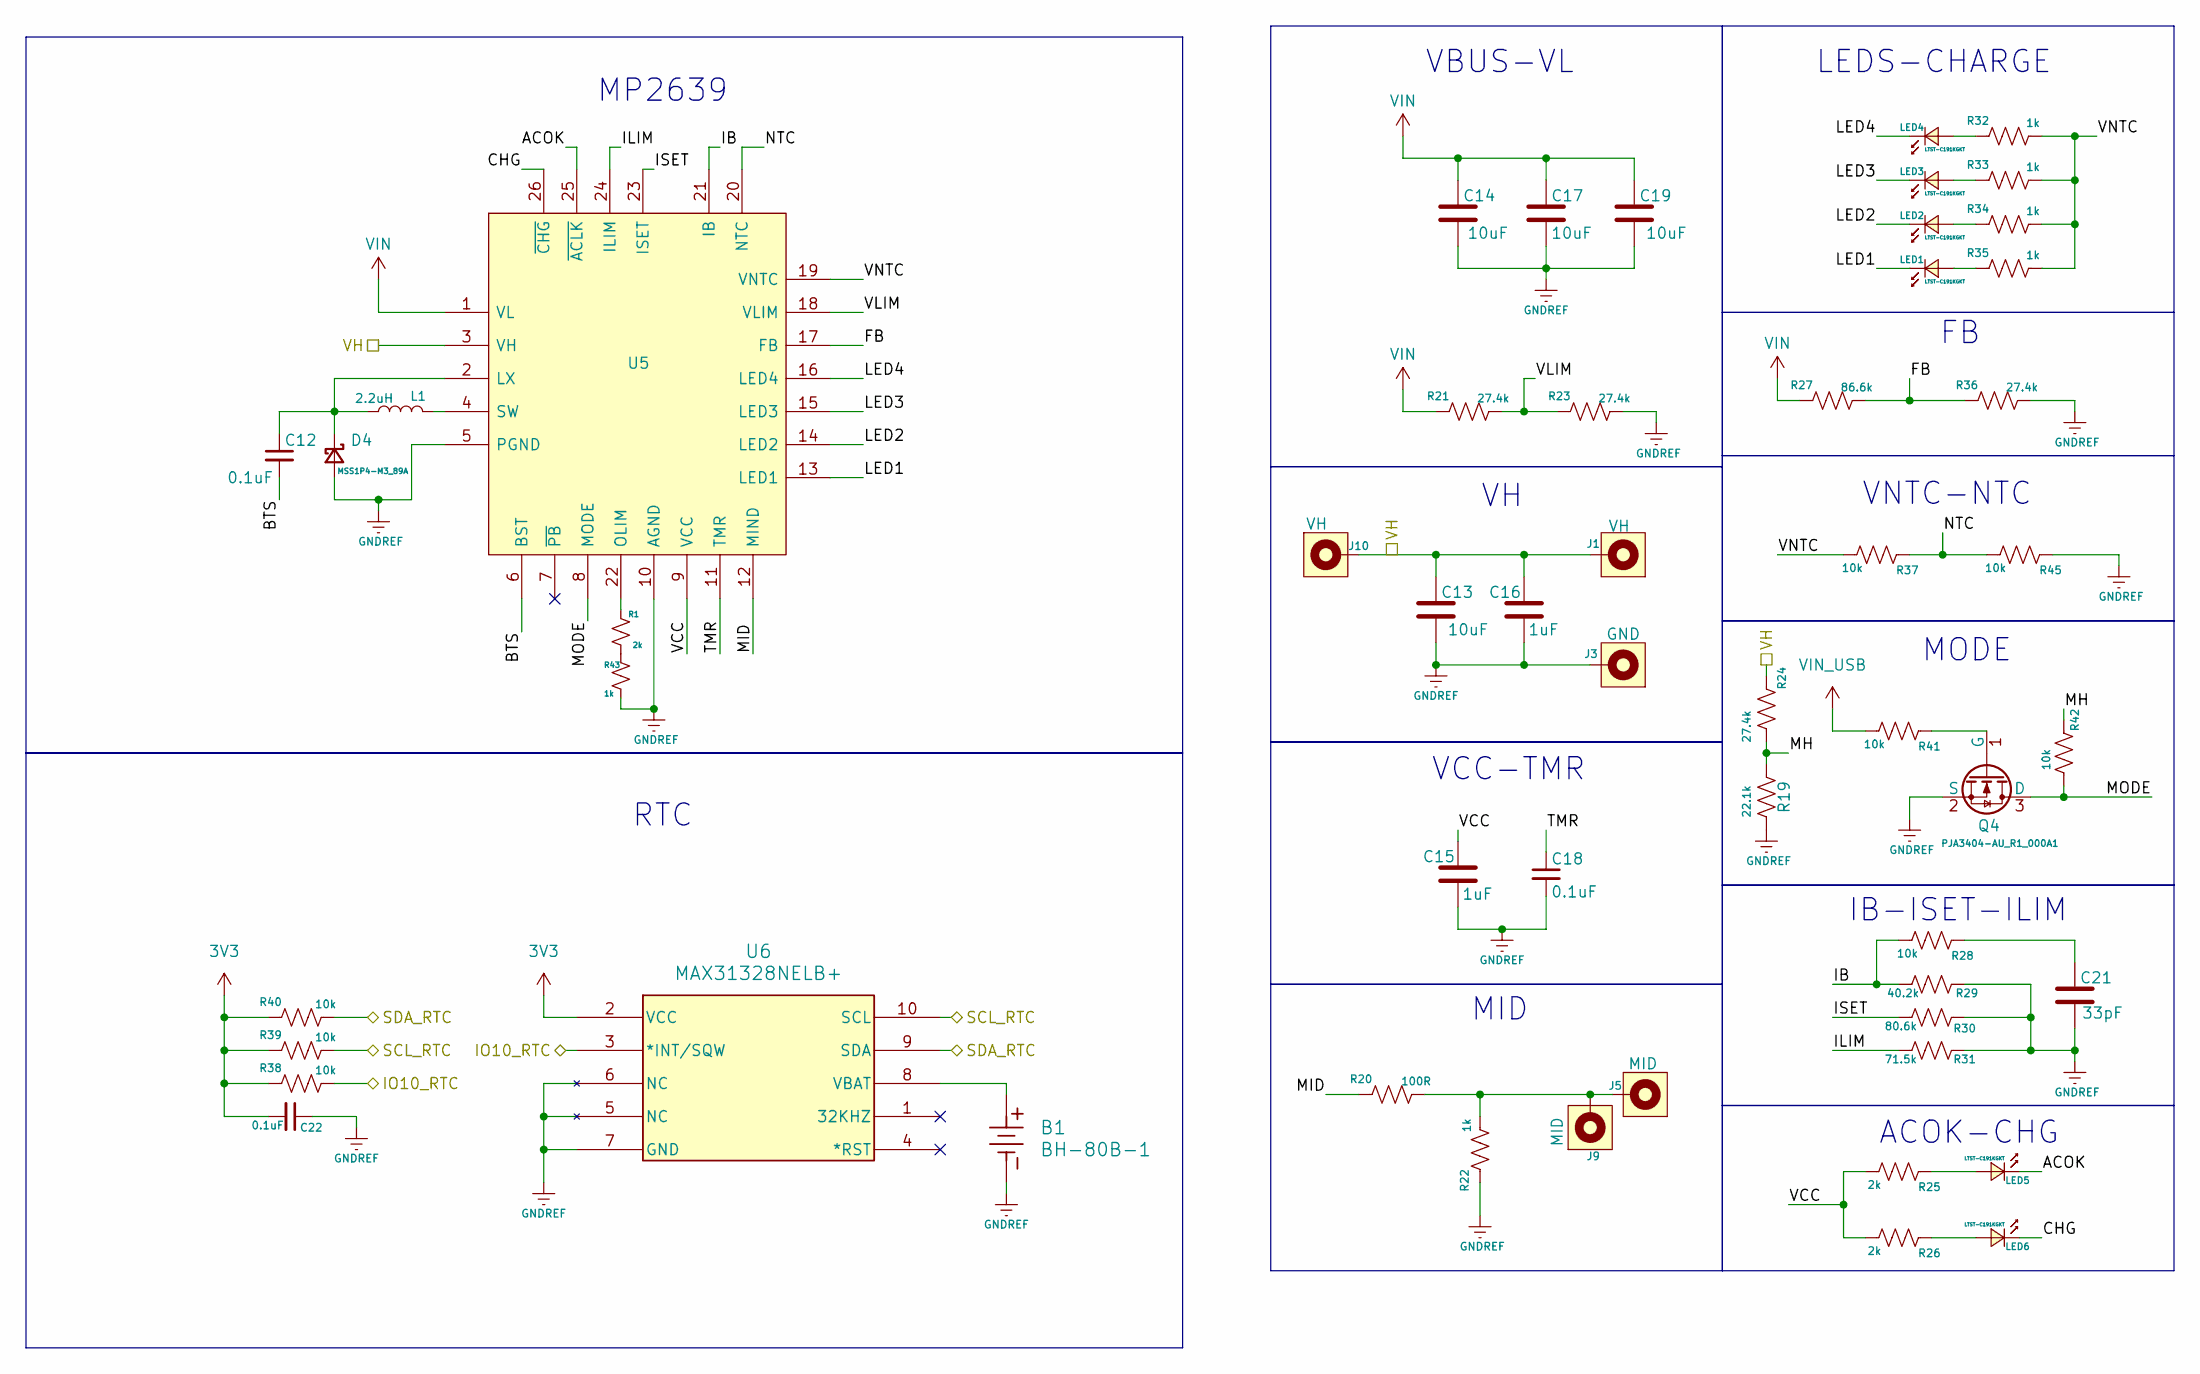
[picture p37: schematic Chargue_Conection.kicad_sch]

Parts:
B1: BH-80B-1; BH-80B-1_ADM
C12, C18, C22: 0.1uF; C_0603_1608Metric
C13, C14, C17, C19: 10uF; C_0805_2012Metric
C15, C16: 1uF; C_0805_2012Metric; Manufacturer # CC0805KKX7R7BB105
C21: 33pF; C_0402_1005Metric
D4: MSS1P4-M3_89A; DIODE_MSS1P4-M3_89A
J1, J10: VH; TEST-PIN
J3: GND; TEST-PIN
J5, J9: MID; TEST-PIN
L1: 2.2uH; 0630CDMCCDS-2R2MC___Inductor
LED1, LED2, LED3, LED4, LED5, LED6: LTST-C191KGKT; LED_0603_1608Metric
Q4: PJA3404-AU_R1_000A1; SOT-23
R1, R25, R26: 2k; R_0603_1608Metric
R19: 22.1k; R_0402_1005Metric
R20: 100R; R_0603_1608Metric
R21, R23, R24: 27.4k; C_0603_1608Metric; Man. part# RC0603FR-0727K4L
R22, R32, R33, R34, R35, R43: 1k; R_0603_1608Metric
R27: 86.6k; R_0603_1608Metric
R28, R37, R38, R39, R40, R41, R42, R45: 10k; R_0603_1608Metric
R29: 40.2k; R_0603_1608Metric
R30: 80.6k; R_0603_1608Metric
R31: 71.5k; R_0603_1608Metric
R36: 27.4k; R_0603_1608Metric
U5: MP2639AGR-Z; MP2639AGRZ; Mouser Part Number 946-MP2639AGR-Z
U6: MAX31328NELB+; 21-0140AK_L1055M-1_MXM

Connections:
3V3: C22.2, R38.1, R39.1, R40.1, U6.2 (VCC); also elsewhere on the board
/Battery_Manager/ACOK: LED5.1 (K), U5.25 (~ACLK)
/Battery_Manager/BTS: C12.2, U5.6 (BST)
/Battery_Manager/CHG: LED6.1 (K), U5.26 (~CHG)
/Battery_Manager/FB: R27.2, R36.1, U5.17 (FB)
/Battery_Manager/IB: R28.2, R29.2, U5.21 (IB)
/Battery_Manager/ILIM: R31.2, U5.24 (ILIM)
/Battery_Manager/IO10_RTC: R38.2, U6.3 (*INT/SQW); also elsewhere on the board
/Battery_Manager/ISET: R30.2, U5.23 (ISET)
/Battery_Manager/LED1: LED1.1 (K), U5.13 (LED1)
/Battery_Manager/LED2: LED2.1 (K), U5.14 (LED2)
/Battery_Manager/LED3: LED3.1 (K), U5.15 (LED3)
/Battery_Manager/LED4: LED4.1 (K), U5.16 (LED4)
/Battery_Manager/MH: R19.1, R24.2, R42.1
/Battery_Manager/MID: R20.1, U5.12 (MIND)
/Battery_Manager/MODE: Q4.3 (D), R42.2, U5.8 (MODE)
/Battery_Manager/NTC: R37.1, R45.2, U5.20 (NTC)
/Battery_Manager/SCL_RTC: R39.2, U6.10 (SCL); also elsewhere on the board
/Battery_Manager/SDA_RTC: R40.2, U6.9 (SDA); also elsewhere on the board
/Battery_Manager/TMR: C18.1, U5.11 (TMR)
/Battery_Manager/VCC: C15.1, R25.2, R26.2, U5.9 (VCC)
/Battery_Manager/VH: C13.1, C16.1, J1.1, J10.1, R24.1, U5.3 (VH); also elsewhere on the board
/Battery_Manager/VLIM: R21.2, R23.1, U5.18 (VLIM)
/Battery_Manager/VNTC: R32.2, R33.2, R34.2, R35.2, R37.2, U5.19 (VNTC)
GNDREF: B1.1, C13.2, C14.2, C15.2, C16.2, C17.2, C18.2, C19.2, C21.2, C22.1, D4.2 (A), J3.1, Q4.2 (S), R19.2, R22.1, R23.2, R29.1, R30.1, R31.1, R36.2, R43.2, R45.1, U5.5 (PGND), U5.10 (AGND), U6.5 (NC), U6.6 (NC), U6.7 (GND); also elsewhere on the board
unnamed: C21.1, R28.1
unnamed: C12.1, D4.1 (K), L1.1, U5.2 (LX)
unnamed: J5.1, J9.1, R20.2, R22.2
unnamed: LED1.2 (A), R35.1
unnamed: LED2.2 (A), R34.1
unnamed: LED3.2 (A), R33.1
unnamed: LED4.2 (A), R32.1
unnamed: LED5.2 (A), R25.1
unnamed: LED6.2 (A), R26.1
unnamed: Q4.1 (G), R41.1
unnamed: R1.2, R43.1
unnamed: R1.1, U5.22 (OLIM)
unnamed: L1.2, U5.4 (SW)
unnamed: B1.2, U6.8 (VBAT)
VIN: C14.1, C17.1, C19.1, R21.1, R27.1, U5.1 (VL); also elsewhere on the board
VIN_USB: R41.2; also elsewhere on the board

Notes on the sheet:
IB-ISET-ILIM
RTC
VNTC-NTC
VCC-TMR
MODE
ACOK-CHG
MP2639
VBUS-VL
MID
LEDS-CHARGE

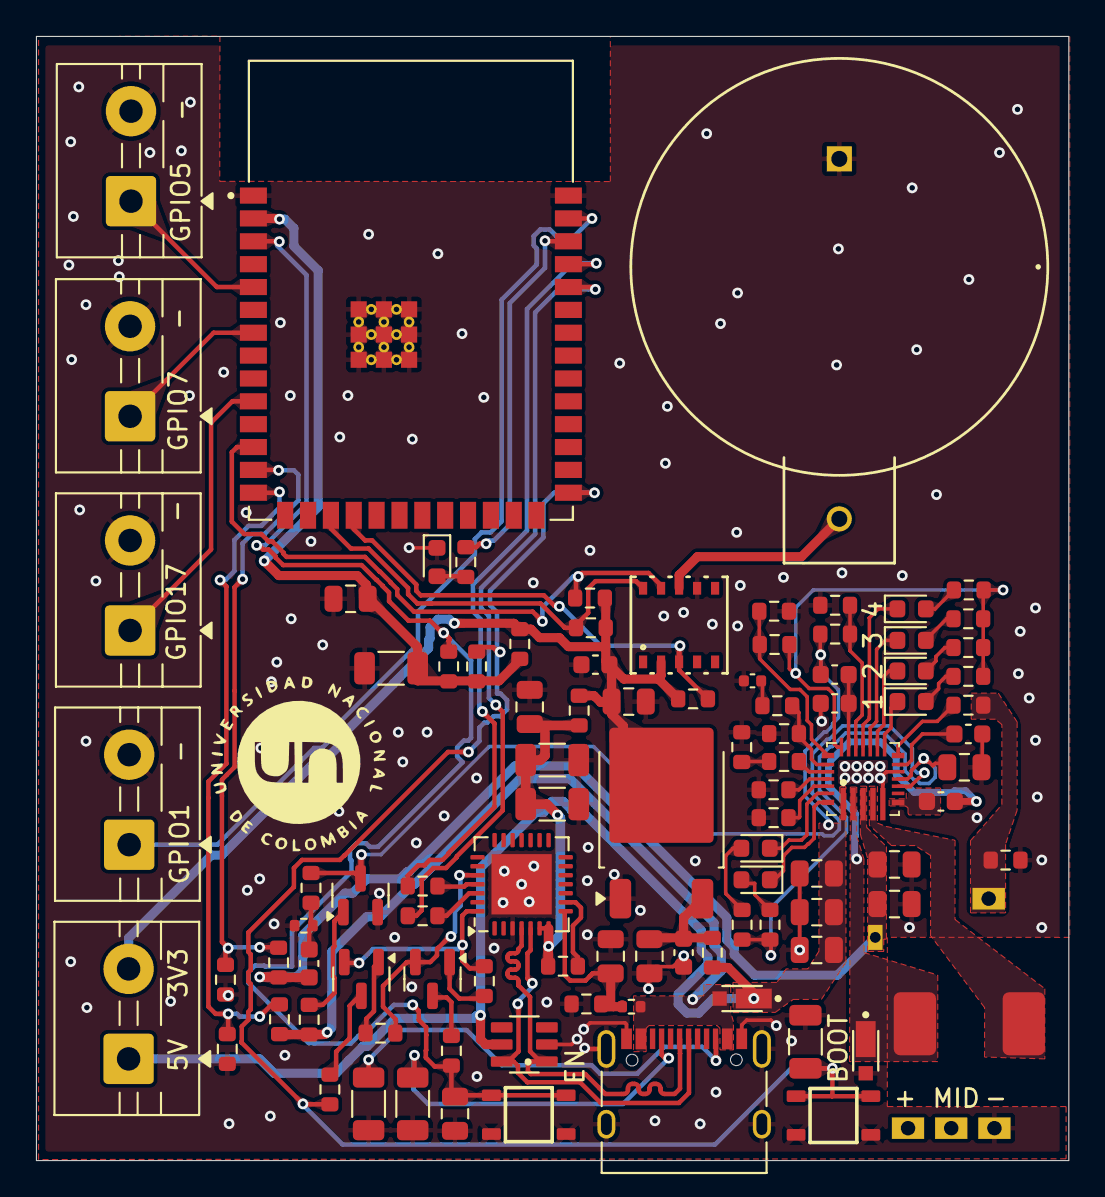
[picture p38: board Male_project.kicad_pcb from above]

Board: 2 copper layers, 57.4 x 62.5 mm, 102 parts (0 on the bottom side), 70 nets.

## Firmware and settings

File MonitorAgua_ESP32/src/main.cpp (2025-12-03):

/**
 * @file main.cpp
 * @brief Sistema de Monitoreo de Calidad del Agua basado en ESP32
 * @details Sistema completo de adquisición de datos de sensores de calidad del agua
 *          (temperatura, pH, TDS, turbidez) con almacenamiento en RTC Memory persistente,
 *          gestión de deep sleep para bajo consumo, envío de datos mediante WiFi/WebSocket,
 *          sincronización de RTC externo MAX31328, y monitoreo de salud del sistema con
 *          watchdog. Diseñado para operación autónoma prolongada con ciclos de medición
 *          configurables y transmisión de datos por solicitud del servidor.
 *
 * Arquitectura:
 * - Ciclo de deep sleep de 80 segundos
 * - Tiempo activo de 45 segundos para lecturas múltiples de sensores
 * - Almacenamiento persistente en RTC Memory (sobrevive deep sleep)
 * - Verificación WiFi cada N lecturas (configurable)
 * - Modo manual: Espera solicitud del servidor para descargar datos
 * - Watchdog hardware/software para recuperación ante fallos
 * - RTC externo para timestamps precisos
 *
 * @author Daniel Acosta - Santiago Erazo
 * @date 01/10/2025
 * @version 1.0
 */

#include <Arduino.h>
#include "WatchDogManager.h"
#include "RTCMemory.h"
#include "DeepSleepManager.h"
#include "Temperatura.h"
#include "TDS.h"
#include "Turbidez.h"
#include "WifiManager.h"
#include "RTC.h"
#include "pH.h"
#include "CalibrationManager.h"

// ——— Configuración del Sistema ———

/**
 * @def SLEEP_INTERVAL_SECONDS
 * @brief Intervalo de deep sleep en segundos entre ciclos de medición
 * @details Tiempo que el ESP32 permanece en deep sleep para ahorro de energía.
 *          Consumo típico: ~10µA en deep sleep vs ~80mA activo.
 * @note Valor típico: 60-300 segundos según aplicación.
 */
#define SLEEP_INTERVAL_SECONDS 80

/**
 * @def ACTIVE_TIME_SECONDS
 * @brief Tiempo activo en segundos para realizar mediciones múltiples de sensores
 * @details Durante este tiempo se toman lecturas periódicas de cada sensor según
 *          sus intervalos configurados (TEMP_INTERVAL, TDS_INTERVAL, etc.).
 * @note Debe ser suficiente para completar al menos una lectura de cada sensor.
 */
#define ACTIVE_TIME_SECONDS 40

/**
 * @def WIFI_CHECK_INTERVAL
 * @brief Número de ciclos de medición entre verificaciones WiFi
 * @details Sistema conecta WiFi cada WIFI_CHECK_INTERVAL lecturas almacenadas.
 *          Ejemplo: Si WIFI_CHECK_INTERVAL=2, conecta después de las lecturas #2, #4, #6, etc.
 * @note Valor bajo → Más frecuencia de transmisión, mayor consumo energético.
 *       Valor alto → Menos transmisiones, mayor acumulación de datos en RTC Memory.
 */
#define WIFI_CHECK_INTERVAL 2

/**
 * @def MANUAL_WAIT_TIMEOUT
 * @brief Timeout en milisegundos esperando solicitud del servidor en modo manual
 * @details Si no se recibe "request_all_data" del servidor en este tiempo, aborta.
 * @note 60000 ms = 1 minuto. Ajustar según latencia esperada del servidor.
 */
#define MANUAL_WAIT_TIMEOUT 60000

// ---Intervalos de muestreo para cada sensor (en milisegundos)---

/**
 * @def TEMP_INTERVAL
 * @brief Intervalo entre lecturas del sensor de temperatura en milisegundos
 * @note 10000 ms = 10 segundos. Durante ACTIVE_TIME_SECONDS (45s) se tomarán ~4 lecturas.
 */
#define TEMP_INTERVAL 5000 // Temperatura cada 5s

/**
 * @def TDS_INTERVAL
 * @brief Intervalo entre lecturas del sensor TDS en milisegundos
 * @note 10000 ms = 10 segundos. Durante ACTIVE_TIME_SECONDS (45s) se tomarán ~4 lecturas.
 */
#define TDS_INTERVAL 5000 // TDS cada 5s

/**
 * @def TURBIDITY_INTERVAL
 * @brief Intervalo entre lecturas del sensor de turbidez en milisegundos
 * @note 10000 ms = 10 segundos. Durante ACTIVE_TIME_SECONDS (45s) se tomarán ~4 lecturas.
 */
#define TURBIDITY_INTERVAL 5000 // Turbidez cada 5s

/**
 * @def PH_INTERVAL
 * @brief Intervalo entre lecturas del sensor de pH en milisegundos
 * @note 10000 ms = 10 segundos. Durante ACTIVE_TIME_SECONDS (45s) se tomarán ~4 lecturas.
 */
#define PH_INTERVAL 1000 // pH cada 1s

// ——— Pines de Sensores ———

/**
 * @def TEMPERATURE_PIN
 * @brief Pin GPIO para sensor de temperatura DS18B20 (protocolo OneWire)
 * @note Requiere resistencia pull-up de 4.7kΩ a Vcc.
 */
#define TEMPERATURE_PIN 17

/**
 * @def TDS_PIN
 * @brief Pin GPIO (ADC) para sensor TDS analógico
 * @note Debe ser pin compatible con ADC1 del ESP32 (GPIO32-39).
 */
#define TDS_PIN 7

/**
 * @def TURBIDITY_PIN
 * @brief Pin GPIO (ADC) para sensor de turbidez analógico
 * @note Debe ser pin compatible con ADC1 del ESP32 (GPIO32-39).
 */
#define TURBIDITY_PIN 5

/**
 * @def PH_PIN
 * @brief Pin GPIO (ADC) para sensor de pH analógico
 * @note Debe ser pin compatible con ADC1 del ESP32 (GPIO32-39).
 */
#define PH_PIN 1

/**
 * @def led
 * @brief Pin GPIO para LED indicador de estado
 * @note GPIO2 típicamente conectado a LED onboard en placas de desarrollo.
 */
#define led 2

// ——— Pines RTC

/**
 * @def RTC_SDA_PIN
 * @brief Pin GPIO para SDA del bus I2C del RTC MAX31328
 */
#define RTC_SDA_PIN 8

/**
 * @def RTC_SCL_PIN
 * @brief Pin GPIO para SCL del bus I2C del RTC MAX31328
 */
#define RTC_SCL_PIN 9

// ——— Configuración WiFi ———
const WiFiManager::wifi_config_t WIFI_CONFIG = {
    .ssid = "RED_MONITOREO",        ///< SSID de la red WiFi
    .password = "Holamundo6",       ///< Password de la red WiFi
    .server_ip = "192.168.137.1",   ///< IP del servidor WebSocket (hotspot móvil típic
    .server_port = 8765,            ///< Puerto del servidor WebSocket
    .connect_timeout_ms = 15000,    ///< Timeout conexión WiFi (15 segundos)
    .websocket_timeout_ms = 10000,  ///< Timeout conexión WebSocket (10 segundos)
    .max_retry_attempts = 3};       ///< Intentos de reconexión (no usado actualmente)

// ——— Instancias globales ———

/**
 * @var watchdog
 * @brief Instancia global del gestor de watchdog y monitoreo de salud
 * @note Parámetro true habilita salida por Serial.
 */
WatchdogManager watchdog(true);

/**
 * @var rtcMemory
 * @brief Instancia global del gestor de RTC Memory persistente
 * @note Parámetro true habilita salida por Serial.
 */
RTCMemoryManager rtcMemory(true);

/**
 * @var deepSleep
 * @brief Instancia global del gestor de deep sleep
 * @note Parámetros: sleep_seconds=80, active_seconds=45, serial_enable=true.
 */
DeepSleepManager deepSleep(SLEEP_INTERVAL_SECONDS, ACTIVE_TIME_SECONDS, true);

/**
 * @var wifiManager
 * @brief Instancia global del gestor de WiFi y WebSocket
 * @note Parámetro true habilita salida por Serial.
 */
WiFiManager wifiManager(true);

/**
 * @var rtcExterno
 * @brief Instancia global del RTC externo MAX31328
 * @note Proporciona timestamps Unix precisos y sincronización NTP.
 */
MAX31328RTC rtcExterno;
/**
 * @var calibManager
 * @brief Instancia global del gestor de calibración de sensores
 * @note Parámetro true habilita salida por Serial.
 */
CalibrationManager calibManager(true);

// ——— Variables para tracking de última lectura de cada sensor ———
// >>> Estas son las líneas que se añadieron (última vez de lectura)

/**
 * @var lastTempRead
 * @brief Timestamp (millis()) de la última lectura de temperatura
 * @note Usado para control de intervalo no bloqueante en loop de medición.
 */
unsigned long lastTempRead = 0; // >>> Esta es la línea que se añadió

/**
 * @var lastTDSRead
 * @brief Timestamp (millis()) de la última lectura de TDS
 * @note Usado para control de intervalo no bloqueante en loop de medición.
 */
unsigned long lastTDSRead = 0; // >>> Esta es la línea que se añadió

/**
 * @var lastTurbidityRead
 * @brief Timestamp (millis()) de la última lectura de turbidez
 * @note Usado para control de intervalo no bloqueante en loop de medición.
 */
unsigned long lastTurbidityRead = 0; // >>> Esta es la línea que se añadió

/**
 * @var lastPHRead
 * @brief Timestamp (millis()) de la última lectura de pH
 * @note Usado para control de intervalo no bloqueante en loop de medición.
 */
unsigned long lastPHRead = 0; // >>> Esta es la línea que se añadió

/**
 * @var forceManualCheck
 * @brief Bandera para forzar verificación WiFi fuera de programación normal
 * @note Se activa al detectar despertar por botón (ESP_SLEEP_WAKEUP_EXT0).
 */
bool forceManualCheck = false;

// ——— Estructuras globales para almacenar últimas lecturas ———

/**
 * @var tempReading
 * @brief Última lectura del sensor de temperatura
 */
TemperatureReading tempReading;

/**
 * @var tdsReading
 * @brief Última lectura del sensor TDS
 */
TDSReading tdsReading;

/**
 * @var turbidityReading
 * @brief Última lectura del sensor de turbidez
 */
TurbidityReading turbidityReading;

/**
 * @var phReading
 * @brief Última lectura del sensor de pH
 */
pHReading phReading;

/**
 * @brief Función setup() - Punto de entrada del programa después de boot/wake
 * @details Secuencia completa de inicialización y operación:
 *          1. Inicializa Serial y LED indicador
 *          2. Inicializa y alimenta watchdog
 *          3. Valida integridad de RTC Memory
 *          4. Inicializa RTC externo MAX31328
 *          5. Realiza health check del sistema
 *          6. Inicializa todos los sensores (temperatura, TDS, turbidez, pH)
 *          7. Loop de medición no bloqueante durante ACTIVE_TIME_SECONDS
 *          8. Obtiene timestamp del RTC externo
 *          9. Almacena lecturas en RTC Memory
 *          10. Verifica si corresponde conexión WiFi
 *          11. Si corresponde, conecta y espera solicitud del servidor
 *          12. Sincroniza RTC con NTP si necesario
 *          13. Muestra resumen del ciclo y estadísticas
 *          14. Entra en deep sleep hasta próximo ciclo
 *
 * @note Esta función se ejecuta después de cada despertar (deep sleep wake, reset, power on).
 * @note Todo el código crítico debe completarse antes de entrar en deep sleep.
 */
void setup()
{
    Serial.begin(115200);
    delay(100);

    Serial.println("\n=== SISTEMA DE MONITOREO DE CALIDAD DEL AGUA ===");
    Serial.println("================================================\n");

    pinMode(led, OUTPUT);
    digitalWrite(led, HIGH);
    // ——— 1. INICIALIZAR WATCHDOG ———
    watchdog.begin();
    watchdog.feedWatchdog();

    // 1.5. INICIALIZAR CALIBRATION MANAGER
    calibManager.begin();
    watchdog.feedWatchdog();

    // ——— 2. VERIFICAR/INICIALIZAR RTC MEMORY ———
    rtcMemory.begin();
    if (!rtcMemory.validateIntegrity())
    {
        // Serial.println(" Datos RTC Memory corruptos - Inicializando");
        rtcMemory.initialize();
        watchdog.logError(WatchdogManager::ERROR_RTC_CORRUPTION,
                            WatchdogManager::SEVERITY_WARNING, 0);
    }
    else
    {
        Serial.println(" Datos RTC Memory válidos");

        // Mostrar información del sistema
        deepSleep.begin();
        deepSleep.printWakeupReason();
        watchdog.displaySystemHealth();

        if (watchdog.getHealthScore() < 20)
        {
            Serial.println("Salud muy baja - Intentando recovery");
            watchdog.attemptRecovery();
        }
    }

    watchdog.feedWatchdog();

    // ——— 3. INICIALIZAR RTC EXTERNO MAX31328 ———
    Serial.println("\n === INICIALIZANDO RTC MAX31328 ===");
    bool rtcAvailable = false;

    // Serial.printf("Inicializando MAX31328 (SDA=%d, SCL=%d)...\n", RTC_SDA_PIN, RTC_SCL_PIN);

    if (!rtcExterno.begin(RTC_SDA_PIN, RTC_SCL_PIN))
    {
        Serial.println(" Error inicializando RTC MAX31328");

        watchdog.logError(WatchdogManager::ERROR_SENSOR_INIT_FAIL,
                            WatchdogManager::SEVERITY_WARNING, 0x31328);
    }
    else
    {
        Serial.println(" RTC MAX31328 inicializado correctamente");
        rtcAvailable = true;

        rtcExterno.printDebugInfo();
        if (deepSleep.isFirstBoot() || rtcExterno.hasLostTime())
        {
            Serial.println(" RTC necesita sincronización");
        }

        watchdog.recordSuccess();
    }

    watchdog.feedWatchdog();

    // ——— 4. HEALTH CHECK ———
    bool health_ok = watchdog.performHealthCheck();
    if (!health_ok && watchdog.getConsecutiveFailures() >= 5)
    {
        Serial.println(" Sistema en falla crítica");
        watchdog.attemptRecovery();
    }

    // ——— 5. CONFIGURAR ERROR LOGGER PARA SENSORES ———
    auto errorLogger = [](int code, int severity, uint32_t context)
    {
        watchdog.logError(static_cast<WatchdogManager::error_code_t>(code),
                            static_cast<WatchdogManager::error_severity_t>(severity),
                            context);
    };

    // ——— 6. INICIALIZAR SENSOR DE TEMPERATURA ———
    // Serial.println("\n Inicializando sensor de temperatura...");
    TemperatureSensor::setErrorLogger(errorLogger);

    if (!TemperatureSensor::initialize(TEMPERATURE_PIN))
    {
        Serial.println(" Error inicializando sensor temperatura");
        watchdog.logError(WatchdogManager::ERROR_SENSOR_INIT_FAIL,
                            WatchdogManager::SEVERITY_CRITICAL, TEMPERATURE_PIN);
        watchdog.recordFailure();
    }
    else
    {
        Serial.println(" Sensor temperatura inicializado");
        watchdog.recordSuccess();
    }

    watchdog.feedWatchdog();

    // ——— 7. INICIALIZAR SENSOR TDS ———
    // Serial.println("\n Inicializando sensor TDS...");
    TDSSensor::setErrorLogger(errorLogger);

    if (!TDSSensor::initialize(TDS_PIN))
    {
        Serial.println(" Error inicializando sensor TDS");
        watchdog.logError(WatchdogManager::ERROR_SENSOR_INIT_FAIL,
                            WatchdogManager::SEVERITY_CRITICAL, TDS_PIN);
        watchdog.recordFailure();
    }
    else
    {
        Serial.println(" Sensor TDS inicializado");

        float kValue, vOffset;
        TDSSensor::getCalibration(kValue, vOffset);

        watchdog.recordSuccess();
    }

    watchdog.feedWatchdog();

    // ——— 8. INICIALIZAR SENSOR DE TURBIDEZ ———
    // Serial.println("\n Inicializando sensor de turbidez...");
    TurbiditySensor::setErrorLogger(errorLogger);

    if (!TurbiditySensor::initialize(TURBIDITY_PIN))
    {
        Serial.println(" Error inicializando sensor turbidez");
        watchdog.logError(WatchdogManager::ERROR_SENSOR_INIT_FAIL,
                            WatchdogManager::SEVERITY_CRITICAL, TURBIDITY_PIN);
        watchdog.recordFailure();
    }
    else
    {
        Serial.println(" Sensor turbidez inicializado");
        watchdog.recordSuccess();
    }

    watchdog.feedWatchdog();

    // ——— 9. INICIALIZAR SENSOR DE pH ———
    // Serial.println("\n Inicializando sensor pH...");
    pHSensor::setErrorLogger(errorLogger);

    if (!pHSensor::initialize(PH_PIN))
    {
        Serial.println(" Error inicializando sensor pH");
        watchdog.logError(WatchdogManager::ERROR_SENSOR_INIT_FAIL,
                            WatchdogManager::SEVERITY_CRITICAL, PH_PIN);
        watchdog.recordFailure();
    }
    else
    {
        Serial.println(" Sensor pH inicializado");

        float phOffset, phSlope;
        pHSensor::getCalibration(phOffset, phSlope);

        watchdog.recordSuccess();
    }

    watchdog.feedWatchdog();

    // ——— 10. TOMAR LECTURAS DE SENSORES ———
    Serial.println("\n === TOMANDO LECTURAS DE SENSORES ===");

    unsigned long startActive = millis(); // >>> Esta es la línea que se añadió

    while ((millis() - startActive) < (ACTIVE_TIME_SECONDS * 1000))
    {                                           // >>> Esta es la línea que se añadió
        unsigned long currentMillis = millis(); // >>> Esta es la línea que se añadió

    // Serial.println(" Leyendo temperatura...");
        if (currentMillis - lastTempRead >= TEMP_INTERVAL)
        {                                                              // >>> Esta es la línea que se añadió
            tempReading = TemperatureSensor::takeReadingWithTimeout(); // >>> Esta es la línea que se añadió
            if (tempReading.valid)
            {
                Serial.printf("Temperatura: %.2f °C\n", tempReading.temperature); // >>> Esta es la línea que se añadió
            }
            lastTempRead = currentMillis; // >>> Esta es la línea que se añadió
        }

    watchdog.feedWatchdog();

    // Serial.println(" Leyendo TDS...");
        if (currentMillis - lastTDSRead >= TDS_INTERVAL)
        {                                                         // >>> Esta es la línea que se añadió
            tdsReading = TDSSensor::takeReadingWithTimeout(25.0); // >>> Esta es la línea que se añadió
            if (tdsReading.valid)
            {
                Serial.printf("TDS: %.1f ppm | EC: %.1f µS/cm\n", tdsReading.tds_value, tdsReading.ec_value); // >>> Esta es la línea que se añadió
            }
            lastTDSRead = currentMillis; // >>> Esta es la línea que se añadió
        }
    watchdog.feedWatchdog();

    // Serial.println(" Leyendo turbidez...");
        if (currentMillis - lastTurbidityRead >= TURBIDITY_INTERVAL)
        {                                                                 // >>> Esta es la línea que se añadió
            turbidityReading = TurbiditySensor::takeReadingWithTimeout(); // >>> Esta es la línea que se añadió
            if (turbidityReading.valid)
            {
                Serial.printf("Turbidez: %.1f NTU\n", turbidityReading.turbidity_ntu); // >>> Esta es la línea que se añadió
            }
            lastTurbidityRead = currentMillis; // >>> Esta es la línea que se añadió
        }
    watchdog.feedWatchdog();

    // Serial.println(" Leyendo pH...");
        if (currentMillis - lastPHRead >= PH_INTERVAL)
        {                                                       // >>> Esta es la línea que se añadió
            phReading = pHSensor::takeReadingWithTimeout(25.0); // >>> Esta es la línea que se añadió
            if (phReading.valid)
            {
                Serial.printf("pH: %.2f\n", phReading.ph_value); // >>> Esta es la línea que se añadió
            }
            lastPHRead = currentMillis; // >>> Esta es la línea que se añadió
        }

        delay(50); // >>> Esta es la línea que se añadió (evita saturar CPU)
    }
    watchdog.feedWatchdog();

    // ——— 11. OBTENER TIMESTAMP DEL RTC MAX31328 ———
    uint32_t rtcTimestamp = 0;
    String rtcDateTime = "No disponible";

    if (rtcAvailable && rtcExterno.isPresent())
    {
        rtcTimestamp = rtcExterno.getUnixTimestamp();
        rtcDateTime = rtcExterno.getFormattedDateTime();

        if (rtcTimestamp < 1609459200)
        {
            Serial.println(" Timestamp RTC inválido - usando tiempo relativo");
            rtcTimestamp = millis() / 1000; // Segundos desde boot
        }
        else
        {
            Serial.printf(" Timestamp RTC: %u (%s)\n", rtcTimestamp, rtcDateTime.c_str());
        }
    }
    else
    {
        Serial.println(" RTC no disponible - usando timestamp relativo");
        rtcTimestamp = millis() / 1000;
    }

    // ——— 12. ALMACENAR EN RTC MEMORY ———
    bool readingStored = false;

    if (tempReading.valid || tdsReading.valid || turbidityReading.valid || phReading.valid)
    {

        RTCMemoryManager::SensorReading reading = rtcMemory.createFullReading(
            tempReading.valid ? tempReading.temperature : 0.0f,
            phReading.valid ? phReading.ph_value : 0.0f,
            turbidityReading.valid ? turbidityReading.turbidity_ntu : 0.0f,
            tdsReading.valid ? tdsReading.tds_value : 0.0f,
            tdsReading.valid ? tdsReading.ec_value : 0.0f,
            (tempReading.sensor_status << 0) |
                (tdsReading.sensor_status << 2) |
                (turbidityReading.sensor_status << 4) |
                (phReading.sensor_status << 6));

        reading.rtc_timestamp = rtcTimestamp;

        reading.valid = (tempReading.valid || tdsReading.valid || turbidityReading.valid || phReading.valid);

        if (rtcMemory.storeReading(reading))
        {
            Serial.println("\n === LECTURA ALMACENADA ===");
            Serial.printf(" Lectura #%d guardada exitosamente\n", rtcMemory.getTotalReadings());
            Serial.printf(" Timestamp: %s (Unix: %u)\n", rtcDateTime.c_str(), rtcTimestamp);

            if (tempReading.valid)
            {
                Serial.printf(" Temperatura: %.2f°C\n", tempReading.temperature);
            }
            if (tdsReading.valid)
            {
                Serial.printf(" TDS: %.1f ppm (EC: %.1f µS/cm)\n",
                                tdsReading.tds_value, tdsReading.ec_value);
            }
            if (turbidityReading.valid)
            {
                Serial.printf(" Turbidez: %.1f NTU (%s)\n",
                                turbidityReading.turbidity_ntu,
                                TurbiditySensor::getWaterQuality(turbidityReading.turbidity_ntu).c_str());
            }
            if (phReading.valid)
            {
                Serial.printf(" pH: %.2f (%s)\n",
                                phReading.ph_value,
                                pHSensor::getWaterType(phReading.ph_value).c_str());
            }
            Serial.println("==========================");

            watchdog.recordSuccess();
            readingStored = true;
        }
        else
        {
            Serial.println(" Error almacenando lecturas");
            watchdog.logError(WatchdogManager::ERROR_RTC_WRITE_FAIL,
                                WatchdogManager::SEVERITY_CRITICAL, 0);
            watchdog.recordFailure();
        }
    }
    else
    {
        Serial.println(" Todas las lecturas inválidas - no se almacena");
        watchdog.recordFailure();
    }

    // ——— 13. VERIFICAR SI ES MOMENTO DE CONECTAR WIFI ———
    bool shouldCheckWiFi = (rtcMemory.getTotalReadings() % WIFI_CHECK_INTERVAL == 0) && (rtcMemory.getTotalReadings() > 0);

    if (deepSleep.getWakeupCause() == ESP_SLEEP_WAKEUP_EXT0)
    {
        Serial.println(" Despertar por botón - Forzando verificación WiFi");
        forceManualCheck = true;
    }
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
void loop()
{
    // No se ejecuta con Deep Sleep
    Serial.println(" ERROR: No entró en Deep Sleep");
    delay(5000);
    ESP.restart();
}

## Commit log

2025-09-26 Comentarios en las librerias de sensores, watchdog y wifi
2025-09-26 Comentarios sensores de Turbidez y Temperatura
2025-11-05 Modificaciónes realizadas: Documentación compatible con Doxygen y variables ajustables de tiempo para la toma de muestras
2025-11-05 Creada nueva rama para gestionar código
2025-11-18 cambios de identación
2025-11-18 añadiendo carpetas correspondientes al diseño e implementación de websocket para cominucación con pagina web y carpeta de esquematicos de la placa prototipo
    [AVAILABLE_COMPONENTS.xlsx, BOM_V1.xlsx, Chargue_Conection.kicad_sch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]
2025-12-03 Organización de carpetas por etapa en la que se desarrollaron los documentos
    [AVAILABLE_COMPONENTS.xlsx, BOM_V1.xlsx, Chargue_Conection.kicad_sch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]
2025-12-07 Agregando documento Doxyfile para generación de documentación en doxygen y probando modificación de gitignore
2025-12-07 Actualización de documentación de Etapas I y II, y actualización de gitignore
    [AVAILABLE_COMPONENTS.xlsx, BOM_V1.xlsx, Chargue_Conection.kicad_sch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]
2025-12-08 Agregando comentarios para sección CalibrationManager
2025-12-08 Actualización de README del repositorio

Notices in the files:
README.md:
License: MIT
